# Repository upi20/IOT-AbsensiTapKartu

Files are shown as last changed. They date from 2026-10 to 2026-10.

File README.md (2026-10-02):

# Absensi RFID Terintegrasi

Alat absensi **tap kartu RFID** berbasis ESP32 yang **terhubung langsung ke website**. Kartu ditempel, alat mengirim nomornya ke server lewat WiFi (HTTP/HTTPS), dan hasilnya (MASUK / PULANG / tidak terdaftar) tampil di layar sentuh 3.5", LED RGB, dan bunyi buzzer. Semua data kehadiran tersimpan di website, bukan di alat.

*Open-source RFID attendance terminal (ESP32 + RC522 + 3.5" touch LCD) that talks to any web app through a small HTTP API. Includes firmware, a Laravel reference server, integration examples, perfboard/PCB layouts and a 3D-printed case. Documentation is in Indonesian.*

Repositori ini berisi **semua yang dibutuhkan dari nol sampai alat jadi**: daftar komponen, kabel prototipe, firmware, server + panel admin, contoh integrasi ke aplikasi lain, tata letak PCB, dan casing cetak 3D.

---

## Daftar isi

- [Fitur](#fitur)
- [Status proyek](#status-proyek-baca-dulu)
- [Cara kerja](#cara-kerja)
- [Peta tahapan](#peta-tahapan)
- [Tahap 0 — Siapkan komponen, alat, dan software](#tahap-0--siapkan-komponen-alat-dan-software)
- [Tahap 1 — Prototipe dengan kabel jumper](#tahap-1--prototipe-dengan-kabel-jumper)
- [Tahap 2 — Firmware](#tahap-2--firmware)
- [Tahap 3 — Backend (website)](#tahap-3--backend-website)
- [Tahap 4 — PCB](#tahap-4--pcb)
- [Tahap 5 — Casing cetak 3D](#tahap-5--casing-cetak-3d)
- [Pemecahan masalah](#pemecahan-masalah)
- [Struktur folder](#struktur-folder)
- [Untuk kontributor](#untuk-kontributor)
- [Lisensi](#lisensi)

Dokumen lain: [Panduan pengguna untuk klien](doc/panduan-pengguna.md) · [Panduan integrasi aplikasi](doc/integrasi-aplikasi.md) · [Riwayat perubahan](CHANGELOG.md)

---

## Fitur

**Alat (firmware ESP32)**
- Tap kartu MIFARE 13,56 MHz (RC522), hasil tampil dalam ± 0,4–0,6 detik di jaringan normal.
- Semua pengaturan lewat **layar sentuh**: pilih WiFi, isi password, Base URL server, dan API key. Tidak perlu mengubah kode untuk tiap lokasi.
- **Antrean offline** 200 tap: kalau server tidak bisa dihubungi, tap disimpan dan dikirim ulang otomatis (tanpa catatan ganda berkat `tap_id`).
- Foto pemilik kartu (JPEG kecil), pesan dari server, jam tersinkron.
- **Screensaver pengumuman** (judul, isi, ikon) yang diambil dari website.
- **Layar meredup** saat alat diam; kartu tetap terbaca.
- Menu Pengaturan ber-PIN, kalibrasi layar, tes buzzer & LED, cek kabel RFID, reset pabrik (tekan EN 3 kali).
- Heartbeat tiap menit, sehingga website tahu alat mana yang aktif.
- Tahan menyala lama: **watchdog** (restart sendiri kalau program macet) dan **restart harian terjadwal** saat sepi (jamnya diatur per alat dari website, bawaan 03:00).
- **Mode absen**: otomatis (server menentukan datang/pulang) atau **pilih DATANG / PULANG** lewat dua tombol di layar utama (endpoint `/check-in` & `/check-out`), diatur dari menu alat atau dari website.
- Mudah dirawat dari jauh: **kode error di layar** (contoh `E11` = password WiFi salah), laporan kesehatan dan **ringkasan crash** ke website, dan **update firmware jarak jauh (OTA)** yang kembali sendiri ke versi lama kalau firmware baru gagal.

**Website**
- **API sederhana** (`/ping`, `/tap`, `/heartbeat`, opsional `/announcements`) yang bisa diterapkan di aplikasi apa saja: lihat [doc/spesifikasi-api.md](doc/spesifikasi-api.md).
- **Server acuan Laravel** dengan panel admin: anggota & kartu, kehadiran, kartu belum terdaftar, rekap + CSV, daftar alat (PIN per alat), pengumuman, pengaturan (API key, judul, layar redup).
- **Contoh integrasi** PHP dan Node.js tanpa framework, skrip pemeriksa server, dan koleksi Postman lengkap.

---

## Status proyek (baca dulu)

Supaya tidak ada yang tersesat: bagian di bawah ini dibedakan antara yang **sudah diuji di alat sungguhan** dan yang **baru berupa desain**.

| Bagian | Status |
|---|---|
| Prototipe kabel jumper di expansion board | ✅ Dirakit dan berjalan |
| Firmware v1.3.0 | ✅ Berjalan di alat prototipe (tap, antrean, pengumuman, layar redup) |
| Firmware v1.4.0 (watchdog, restart harian, identitas baru) | ✅ Berjalan di alat (boot, tap, heartbeat, watchdog aktif); ⚠️ restart harian **belum diuji** |
| Firmware v1.5.0 (kode error, ringkasan crash, update jarak jauh) | ✅ Update jarak jauh diuji di alat (unduh ± 15 detik, rollback saat restart di masa percobaan juga terbukti); ⚠️ tiap kode error belum diuji satu per satu |
| Server Laravel + panel admin | ✅ Dipakai di server percobaan; 145 tes otomatis lulus |
| Contoh integrasi PHP/Node + Postman | ✅ Lolos skrip pemeriksa dan 114 pemeriksaan Postman |
| Firmware v1.6.0–1.9.1 (mode absen DATANG/PULANG, menu Update firmware, buzzer langsung ke D17) | ✅ Dikirim ke alat lewat update jarak jauh: otomatis 1.5.0 → 1.6.0 → 1.7.0, manual 1.7.0 → 1.8.0 → 1.9.0 → 1.9.1. ⚠️ Mode Pilih Datang/Pulang **belum diuji dengan tap sungguhan** |
| PCB dot matrix (papan bolong 1 sisi 30 × 50) | ✅ Alat pertama dirakit dengan tata letak ini dan berjalan (layar, sentuh, RFID, WiFi, tap, buzzer). ⚠️ Kabel LED (tahap 16) belum diuji; casing belum disesuaikan |
| PCB cetak (KiCad) | ⚠️ Desain lolos DRC, **belum dipesan dan belum diuji** |
| Casing cetak 3D | ⚠️ Desain lolos cek tabrakan otomatis, **belum dicetak** |

Kalau Anda merakit bagian yang bertanda ⚠️, lakukan cek cetak kertas 1:1 yang dijelaskan di tahap itu, dan laporkan hasilnya lewat *Issues*.

---

## Cara kerja

```mermaid
flowchart LR
  K[Kartu RFID] -->|tap| A["Alat<br/>ESP32 + RC522 + LCD"]
  A -->|"POST /tap (WiFi, HTTPS)"| W["Website<br/>(server acuan Laravel<br/>atau aplikasi Anda)"]
  W -->|"status: MASUK / PULANG / ..."| A
  A -.->|heartbeat tiap 1 menit| W
  W -.->|pengaturan & pengumuman| A
  W --> P[Panel admin / laporan]
```

1. Kartu ditempel. Alat membaca UID kartu dan mengubahnya menjadi **nomor 10 digit**.
2. Alat mengirim `POST {Base URL}/tap` dengan header `X-API-Key` dan `X-Device-ID`.
3. Website memutuskan statusnya (`check_in`, `check_out`, `duplicate`, `unknown`, `rejected`) dan membalas nama, pesan, dan (opsional) URL foto.
4. Alat menampilkan hasil, berbunyi, dan menyalakan LED sesuai status.

Website juga bisa mengirim **pengaturan jarak jauh** (PIN menu, judul layar, layar redup) dan **pengumuman** ke alat. Kontrak lengkapnya ada di [doc/spesifikasi-api.md](doc/spesifikasi-api.md).

---

## Peta tahapan

| Tahap | Hasil | Dokumen utama |
|---|---|---|
| 0. Persiapan | Komponen, alat, software siap | bagian di bawah |
| 1. Prototipe | Rangkaian kabel jumper berjalan | [doc/skema-lengkap.md](doc/skema-lengkap.md), [doc/rakit-lengkap.html](doc/rakit-lengkap.html) |
| 2. Firmware | Alat membaca kartu dan tampil di layar | [firmware/](firmware/) |
| 3. Backend | Website menerima tap, panel admin | [api/README.md](api/README.md), [doc/integrasi-aplikasi.md](doc/integrasi-aplikasi.md), [doc/spesifikasi-api.md](doc/spesifikasi-api.md), [contoh-integrasi/](contoh-integrasi/README.md) |
| 4. PCB | Rangkaian rapi tanpa kabel jumper | [doc/rakit-dotmatrix.html](doc/rakit-dotmatrix.html), [doc/pcb-papan-induk.md](doc/pcb-papan-induk.md) |
| 5. Casing | Alat jadi, siap dipasang di dinding | [doc/casing.md](doc/casing.md) |

> **File `.html`** di folder `doc/` adalah panduan interaktif. GitHub hanya menampilkan kodenya, jadi **unduh repositori lalu buka file itu di browser** (dobel klik).

---

## Tahap 0 — Siapkan komponen, alat, dan software

### Komponen (1 unit)

| Komponen | Keterangan | Catatan |
|---|---|---|
| ESP32 DOIT DevKit V1 **30 pin** | Chip USB CH340, jarak dua deret pin 25,4 mm | Varian 38 pin **tidak** cocok dengan PCB dan casing |
| LCD 3.5" SPI **ILI9488** + touch **XPT2046** | 480 × 320, 14 pin di satu sisi pendek, PCB 98 × 56,34 mm (kompatibel LCDWIKI MSP3520) | Jumper **J1** di belakang LCD harus disolder (lihat Tahap 1) |
| RFID **RC522** | Modul standar 60 × 40 mm, 8 pin, 3,3 V | Header pin lurus |
| LED RGB 5 mm **common cathode** | 4 kaki, kaki terpanjang = katoda (−) | Bukan *common anode* |
| Buzzer **aktif** 3–5 V | 2 kaki, berbunyi sendiri bila diberi tegangan | Bukan buzzer pasif |
| Kartu / gantungan kunci MIFARE 13,56 MHz | Biasanya satu paket dengan RC522 | |
| Kabel USB data + adaptor 5 V | Untuk daya alat | |

**Untuk prototipe (Tahap 1):** expansion board ESP32 30 pin (header G-V-S per pin) dan ± 30 kabel jumper female-female.
**Untuk versi rapi (Tahap 4):** papan dot matrix atau PCB cetak beserta komponen kecilnya (resistor, transistor, dioda, kapasitor, header female). Daftarnya ada di tahap itu.

### Alat

Solder + timah, tang potong, multimeter (mode bunyi dan volt DC), obeng kecil. Untuk Tahap 4: cutter, bor 3 mm, lem. Untuk Tahap 5: baut M3 dan spacer.

### Software

| Software | Untuk | Versi yang dipakai di proyek ini |
|---|---|---|
| [Arduino IDE 2](https://www.arduino.cc/en/software) (atau `arduino-cli`) | Firmware | IDE 2.3.10 / arduino-cli 1.5.1 |
| Paket board **esp32 by Espressif Systems** | Firmware | 3.3.12 |
| PHP 8.3 + Composer + PostgreSQL | Server acuan (Tahap 3) | PHP 8.3, Laravel 13 |
| KiCad 10 (opsional) | Membuka / mengubah PCB cetak | 10.0.6 |
| OpenSCAD versi *snapshot* (opsional) | Membuka / mengubah casing | 2026.09.30 |
| Python 3 + PyMuPDF (opsional) | Membuat ulang templat dot matrix | |

---

## Tahap 1 — Prototipe dengan kabel jumper

Tujuannya membuktikan semua komponen berfungsi sebelum dibuat rapi. **Cabut USB setiap kali memasang atau memindah kabel.**

### 1.1 Aturan daya (penting)

- **Semua komponen memakai 3,3 V.** Jangan ada kabel ke pin 5V.
- Di expansion board, jumper **JUMP** harus di posisi **3.3V** (mengatur semua pin V).
- Pakai satu kabel USB saja, ke port **ESP32** (bukan port expansion).
- ESP32 hanya bisa tersambung ke WiFi **2,4 GHz**.

### 1.2 Solder jumper J1 di LCD

Menurut skema resmi modul LCD: kalau VCC diberi **3,3 V**, jumper **J1 harus disambung** (dijembatani timah). Kalau VCC 5 V, J1 dibiarkan terbuka. Rangkaian ini memakai 3,3 V, jadi:

1. Cari bantalan bertanda **J1** di belakang LCD (dekat regulator U1).
2. Sambungkan kedua bantalannya dengan sedikit timah.
3. Setelah J1 disambung, **VCC LCD tidak boleh lagi diberi 5 V**: chip layar bisa rusak.

### 1.3 Pasang kabel

Ikuti [doc/skema-lengkap.md](doc/skema-lengkap.md) (versi interaktif: [doc/rakit-lengkap.html](doc/rakit-lengkap.html)). Ringkasan pin:

| Bagian | Pin modul → GPIO ESP32 |
|---|---|
| LCD | VCC → 3V3, GND → GND, CS → 5, RESET → 4, DC → **16**, SDI → 23, SCK → 18, **LED → 2**, SDO tidak disambung |
| Touch | T_CLK → 22, T_CS → 15, T_DIN → 21, T_DO → 19, T_IRQ tidak disambung |
| RC522 | SDA → 33, SCK → 14, MOSI → 13, MISO → 35, RST → 32, 3.3V → 3V3, GND → GND, IRQ tidak disambung |
| Buzzer aktif | + → 17, − → GND |
| LED RGB | R → 25, G → 26, B → 27, kaki terpanjang (K) → GND |

Catatan:
- **DC jangan di GPIO2.** Pin LED LCD (lampu latar) memang di GPIO2; firmware memakainya untuk meredupkan layar. Kalau LED LCD disambung ke 3V3, layar menyala terus tanpa fitur redup.
- Pin **GPIO12 jangan dipakai** (pin boot yang membuat ESP32 gagal menyala).
- Resistor 220–330 Ω di tiap kaki warna LED RGB disarankan. Untuk prototipe boleh tanpa resistor karena firmware membatasi arus pin.

### 1.4 Tes per bagian

Sebelum menjalankan tes, siapkan software di [Tahap 2.1](#21-pasang-software). Sketsa tes ada di [firmware/tes/](firmware/tes/):

| Urutan | Sketsa | Yang dites | Hasil yang benar |
|---|---|---|---|
| 1 | `tes_touch` | Layar + layar sentuh | Muncul kalibrasi 3 titik, lalu mode menggambar: titik muncul tepat di bawah jari/stylus |
| 2 | `tes_miso` | Kabel MOSI dan MISO RC522 tidak bersentuhan | Monitor serial menulis `AMAN` terus-menerus |
| 3 | `tes_rfid` | RC522 menjawab | Baris pertama (susunan kabel yang direncanakan) diakhiri `<== RC522 MENJAWAB` |

Buzzer dan LED dites dari firmware utama (menu **Tes buzzer & LED**), setelah Tahap 2.

---

## Tahap 2 — Firmware

Kode ada di [firmware/absensi/](firmware/absensi/). Bahasa komentar: Indonesia.

### 2.1 Pasang software

1. Pasang **Arduino IDE 2**.
2. **Tools → Board → Boards Manager**, cari `esp32`, pasang **esp32 by Espressif Systems** (dipakai: 3.3.12). Kalau tidak muncul, tambahkan URL `https://espressif.github.io/arduino-esp32/package_esp32_index.json` di **Settings → Additional boards manager URLs**.
3. **Tools → Manage Libraries**, pasang:

   | Library | Versi dipakai | Untuk |
   |---|---|---|
   | TFT_eSPI (Bodmer) | 2.5.43 | Layar |
   | RFID_MFRC522v2 | 2.0.6 | RC522 |
   | ArduinoJson (Benoit Blanchon) | 7.4.3 | JSON |
   | TJpg_Decoder (Bodmer) | 1.1.0 | Foto |
   | XPT2046_Touchscreen (Paul Stoffregen) | 1.4 | Hanya untuk sketsa `tes_touch` |

   Pengaturan pin layar ada di `tft_setup.h` di folder sketsa dan dibaca otomatis oleh TFT_eSPI. **File library tidak perlu diubah.**
4. **Mac Apple Silicon:** pasang Rosetta 2 (alat `ctags` di paket Arduino masih x86):
   ```bash
   softwareupdate --install-rosetta --agree-to-license
   ```
5. **Windows:** pasang driver **CH340** kalau port COM tidak muncul.

### 2.2 Atur ID alat

Buka [firmware/absensi/config.h](firmware/absensi/config.h), ubah `ID_ALAT` (bawaan `"ABS-001"`). **Setiap alat harus punya ID berbeda**; ID ini dikirim sebagai `X-Device-ID` dan tidak terhapus saat reset pabrik. Isi `""` supaya dibuat otomatis dari alamat MAC (contoh `ABS-79438C`).

Sejak v1.5.0, ID yang dipakai juga disimpan di memori alat. Upload lewat USB memakai `ID_ALAT` di `config.h`. Update jarak jauh (2.7) tidak memakai `ID_ALAT`, tapi ID yang tersimpan di alat, jadi satu file firmware aman dikirim ke semua alat.

Pengaturan lain di file yang sama (biasanya tidak perlu diubah): PIN bawaan `2026`, interval heartbeat 60 detik, batas antrean 200, batas waktu tap 3 detik, layar redup 60 detik ke 20 %.

### 2.3 Upload

**Lewat Arduino IDE (semua sistem operasi):**
1. Buka `firmware/absensi/absensi.ino`.
2. Board: **ESP32 Dev Module** (bukan "DOIT ESP32 DEVKIT V1", karena yang itu tidak punya menu partisi).
3. **Partition Scheme: Minimal SPIFFS (1.9MB APP with OTA/128KB SPIFFS)**. Wajib: firmware ± 1,35 MB tidak muat di partisi bawaan, dan skema ini punya 2 slot untuk update jarak jauh.
4. Upload Speed: **460800** (Mac/Linux). Kalau upload gagal atau di Windows, pakai **115200**.
5. Pilih port, klik Upload. Kalau tertahan di `Connecting....`, tahan tombol **BOOT** sampai persentase muncul.

**Lewat skrip (Mac/Linux, butuh `arduino-cli`):** dari folder `firmware/`:
```bash
./upload.sh -m              # compile + upload firmware utama, lalu buka monitor serial
./upload.sh -c              # compile saja (cek tanpa alat)
./upload.sh -b              # buat file untuk update jarak jauh (lihat 2.7)
./upload.sh tes_rfid -m     # upload sketsa tes
./monitor.sh                # monitor serial 115200 baud, keluar: Ctrl+C
PORT=/dev/ttyUSB0 ./upload.sh    # pilih port sendiri
```
Skrip memakai partisi Minimal SPIFFS dan kecepatan 460800 secara otomatis. `arduino-cli` dicari di `PATH`, lalu di dalam Arduino IDE (macOS). Lokasi lain: `ARDUINO_CLI=/path/arduino-cli ./upload.sh`.

> **Alat dengan firmware ≤ 1.4.0** (partisi lama Huge APP) harus di-upload **sekali lewat USB** ke v1.5.0, karena partisinya berubah. Pengaturan (WiFi, Base URL, API key, PIN, kalibrasi) tetap, tapi antrean tap dan pengumuman yang tersimpan terhapus. Kirim dulu antrean yang tersisa (tunggu sampai Info alat → Antrean = 0). Setelah itu, update berikutnya bisa lewat jarak jauh.

### 2.4 Siapkan server sementara (kalau website belum ada)

Saat pertama menyala, alat meminta **Base URL** dan **API key**. Kalau server Tahap 3 belum siap, jalankan contoh server PHP di laptop (satu WiFi dengan alat):

```bash
cd contoh-integrasi/php
php -S 0.0.0.0:8080 index.php
```

Base URL-nya `http://<IP-laptop>:8080`, API key `ganti-dengan-kunci-anda`. Kartu contoh yang terdaftar: `0218893066` dan `0012345678` (`0055555555` sengaja nonaktif). Kartu Anda sendiri akan tampil "tidak terdaftar" sampai nomornya ditambahkan ke data contoh. Ini cukup untuk membuktikan alat bekerja. Rinciannya: [contoh-integrasi/README.md](contoh-integrasi/README.md).

### 2.5 Pertama kali menyala

Alat baru (atau setelah reset pabrik) menjalankan urutan ini:
1. **Kalibrasi layar sentuh** 3 titik (hanya kalau belum pernah).
2. **Panduan 4 langkah:**
   1. **WiFi**: pilih dari hasil pindai (atau "Ketik manual"), isi password.
   2. **Base URL**: sudah terisi `https://`. Lengkapi, contoh `https://absensi.example.com/api/absensi` atau `http://192.168.1.10:8080`. Tanpa `/` di akhir.
   3. **API key**: sama persis dengan di server.
   4. **Tes koneksi**, lalu **Simpan**.
3. Layar utama tampil. Tempel kartu.

Monitor serial (115200 baud) menampilkan catatan seperti `RFID: RC522 terdeteksi`, `HTTP POST /tap -> 200`, dan `Tap: 245 ms`.

### 2.6 Menu dan fitur alat

| Fitur | Cara |
|---|---|
| Menu Pengaturan | Ikon gir di layar utama, PIN bawaan **2026** (5 kali salah = terkunci 60 detik). Menu tertutup sendiri setelah 60 detik tanpa sentuhan |
| Isi menu | WiFi, Server, Tes koneksi, Info alat, Ganti PIN, Kalibrasi layar, Tes buzzer & LED, Tes screensaver, Cek kabel RFID, Mode absen, Update firmware, Reset pabrik |
| Mode absen | Menu **Mode absen**: **Otomatis** (semua tap ke `/tap`, server menentukan datang/pulang) atau **Pilih Datang / Pulang**: layar utama menampilkan tombol **DATANG** dan **PULANG**. Petugas memilih sekali, lalu semua tap dikirim ke `/check-in` atau `/check-out` sampai diganti. Pilihan dikosongkan otomatis saat tanggal berganti; tap sebelum memilih tidak dikirim. Bisa juga diatur per alat dari website (`config.tap_mode`) |
| Kalibrasi ulang layar | Menu **Kalibrasi layar**, atau tekan **EN** lalu tekan **BOOT** saat muncul "Tekan BOOT sekarang" (jeda 1 detik) |
| Reset pabrik | Tekan **EN 3 kali berturut-turut** (masing-masing sebelum alat menyala 5 detik), lalu pilih "Ya, reset"; atau lewat menu. Menghapus WiFi, URL, API key, PIN, judul, kalibrasi, antrean, pengumuman. **ID alat tidak terhapus** |
| Layar redup | Setelah diam 60 detik, layar meredup ke 20 %. Kartu tetap diproses. Sentuhan pertama hanya menyalakan layar. Angka bisa diubah dari website (`dim_after`, `dim_level`) |
| Antrean offline | Server tidak terjangkau → tap disimpan (maks. 200) dan dikirim ulang saat alat diam |
| Restart harian | Sekali sehari pada jam yang diatur per alat di website (bawaan **03:00**, jam alat), hanya saat alat diam. Antrean tap tetap tersimpan. Kosongkan jamnya di website untuk mematikan |
| Watchdog | Kalau program macet lebih dari 60 detik, alat restart sendiri. Alasan restart terakhir terlihat di **Info alat → Restart** dan dikirim ke website |
| Kode error | Masalah tampil di baris bawah layar utama dengan kode, contoh **E11 Password WiFi salah**. Daftar lengkap di 2.8. Kode yang sedang aktif juga ada di **Info alat → Error** |
| Laporan ke website | Tiap menit: sinyal, RAM, status RFID, antrean, kode error, alasan restart, dan ringkasan crash terakhir. Website menandai alat yang perlu diperhatikan |
| Update jarak jauh | Firmware baru diunggah di website, lalu alat memasangnya sendiri saat diam, **atau langsung lewat menu Update firmware** (lihat 2.7) |
| Pengaturan dari website | PIN menu (per alat), jam restart (per alat), judul layar, layar redup, pengumuman, update firmware (per alat) |

### 2.7 Update firmware jarak jauh (OTA)

Dipakai untuk memperbarui alat yang sudah terpasang di lokasi **tanpa kabel USB**: file firmware diunggah ke website, lalu alat mengunduh dan memasangnya sendiri.

**Syarat (cukup dicek sekali):**
- Alat sudah ber-firmware **1.5.0 atau lebih baru**. Alat dengan firmware lama harus di-upload lewat USB dulu (lihat catatan di 2.3), karena partisinya berbeda.
- Website mendukung update firmware. Server acuan Laravel (Tahap 3.A) sudah punya menu **Firmware**. Aplikasi sendiri: lihat [doc/spesifikasi-api.md](doc/spesifikasi-api.md) bagian 6.1.

#### Langkah 1 — Naikkan nomor versi

Buka [firmware/absensi/config.h](firmware/absensi/config.h) dan ubah `VERSI_FIRMWARE`, contoh `"1.5.0"` → `"1.5.1"`.

Wajib: alat **mengabaikan** update yang versinya sama dengan versi yang sedang terpasang, dan website menolak file yang di dalamnya tidak ada nomor versi yang Anda isi.

#### Langkah 2 — Build file `.bin`

File untuk OTA **bukan** hasil upload biasa. ID alat tidak boleh ikut tertanam, supaya satu file bisa dikirim ke semua alat dan tiap alat tetap memakai ID-nya sendiri. Pilih salah satu cara:

**Cara A — skrip (Mac/Linux, disarankan).** Dari folder `firmware/`, tanpa alat tersambung:
```bash
./upload.sh -b
```
Hasilnya di folder `firmware/build/`:

| File | Untuk apa |
|---|---|
| `absensi-1.5.1.bin` | **Diunggah ke website** (Langkah 3) |
| `absensi-1.5.1.elf` | **Simpan baik-baik** (jangan diunggah). Hanya file ini yang bisa menerjemahkan laporan crash dari versi 1.5.1 (lihat 2.8) |
| `absensi/` | File sementara hasil compile, abaikan |

**Cara B — Arduino IDE (semua sistem operasi).**
1. Di `config.h`, hapus `//` di depan baris `// #define OTA_BUILD`, sehingga menjadi `#define OTA_BUILD`.
2. Board dan Partition Scheme sama seperti 2.3 (**ESP32 Dev Module**, **Minimal SPIFFS (1.9MB APP with OTA/128KB SPIFFS)**).
3. Menu **Sketch → Export Compiled Binary**. Tunggu sampai selesai.
4. Buka folder `firmware/absensi/build/esp32.esp32.esp32/`. Yang diunggah ke website adalah **`absensi.ino.bin`**. Jangan pakai `absensi.ino.merged.bin`, `absensi.ino.bootloader.bin`, atau `absensi.ino.partitions.bin`. Simpan juga `absensi.ino.elf`, beri nama sesuai versinya.
5. **Kembalikan `//` di depan `#define OTA_BUILD`.** Kalau lupa, upload lewat USB ke alat baru tidak memakai `ID_ALAT`, tapi ID dari MAC (contoh `ABS-79438C`).

#### Langkah 3 — Unggah dan pilih alat (server acuan)

1. Panel admin → **Firmware** → **Unggah firmware**. Isi **Versi** sama persis dengan `VERSI_FIRMWARE` (contoh `1.5.1`), pilih file `.bin`, lalu klik **Unggah**.
2. Panel admin → **Alat** → di kartu alat yang akan diperbarui, pilih **Update firmware ke: 1.5.1**, lalu simpan. Status alat menjadi **"Menunggu alat mengunduh"**.
3. Untuk semua alat sekaligus, pakai tombol **Terapkan ke semua alat** di halaman Firmware. **Cobakan dulu ke satu alat** sampai statusnya "Sudah terpasang", baru ke semua.

#### Langkah 4 — Tunggu alat memasang sendiri

1. Alat menerima tawaran update lewat heartbeat (paling lama 1 menit).
2. Update baru mulai saat **tidak ada kartu atau sentuhan selama 1 menit**, supaya orang yang sedang absen tidak terganggu.
3. Layar menampilkan **"Memperbarui firmware v1.5.0 → v1.5.1"**, bilah kemajuan, dan **"Jangan cabut listrik alat"**. Unduhan memakan waktu ± 15–60 detik, tergantung internet.
4. Alat mengecek isi file (MD5), menampilkan "Firmware terpasang", lalu restart dengan versi baru.
5. Di halaman Alat, status menjadi **"Sudah terpasang"**, dan riwayat kejadian mencatat `Firmware 1.5.0 -> 1.5.1`.

**Atau pasang sekarang juga (manual, firmware 1.7.0 ke atas):** di alat buka **Pengaturan → Update firmware**. Alat langsung bertanya ke server. Kalau muncul **"Tersedia v…"**, tekan **Pasang sekarang** → **Pasang**. Cara ini tidak menunggu alat diam dan tidak menunggu jeda 30 menit setelah gagal, dan alasan kegagalan tampil di layar. Server hanya menawarkan versi yang **sudah dijadwalkan untuk alat itu** (Langkah 3). Kalau belum dijadwalkan, menu menjawab "Sudah versi terbaru".

Selama update, buzzer diam, LED menyala biru, dan tampilan lain (jam, sinyal) berhenti sebentar: semua kemampuan alat dipakai untuk mengunduh. Itu wajar selama bilah kemajuan bergerak.

#### Kalau ada yang salah

| Yang terjadi | Artinya / yang dilakukan |
|---|---|
| Server sudah menawarkan update tapi alat tidak kunjung memasang | Alat sedang dipakai, menu Pengaturan sedang terbuka, atau percobaan pertama gagal tersambung (alat lalu menunggu 30 menit). Pakai **menu Update firmware** untuk memasang langsung dan melihat alasannya |
| Lama di "Menunggu alat mengunduh" | Alat offline, sedang dipakai terus, atau firmware alat masih < 1.5.0. Cek status Online dan versi firmware alat |
| Layar "Update firmware gagal" | Unduhan putus atau file rusak. Alat tetap memakai versi lama dan **mencoba lagi 30 menit kemudian**. Alasannya terlihat di Info alat → Firmware |
| Riwayat: "Firmware 1.5.1 -> 1.5.0" tanpa status gagal | Listrik padam atau tombol EN ditekan di menit pertama setelah update, jadi alat kembali ke versi lama untuk berjaga-jaga. Bukan salah firmware: alat **mengulang update sendiri** (paling banyak 3 kali) |
| Status "Gagal, kembali ke 1.5.0" | Firmware baru crash, macet (watchdog), atau listrik drop (brownout) sebelum dinyatakan sehat (5 menit, atau 1 menit setelah server tersambung), jadi alat **kembali sendiri ke versi lama**. Versi itu tidak dicoba lagi. Perbaiki kodenya (lihat laporan crash di riwayat kejadian), naikkan versi (1.5.2), lalu unggah ulang |
| Website menolak file | Versi yang diisi tidak ditemukan di dalam file (lupa Langkah 1, atau salah ketik), file bukan `absensi.ino.bin`, atau ukuran lebih dari 1,9 MB |

Jangan cabut listrik selama layar "Memperbarui firmware" dan di menit pertama setelah alat restart. Kalaupun terjadi, alat tidak rusak: saat mengunduh, firmware baru ditulis ke slot cadangan dan baru dipakai setelah selesai dicek; sesudah restart, alat kembali ke versi lama lalu mengulang update.

Catatan keamanan: alat memakai HTTPS tanpa pemeriksaan sertifikat (sama seperti request lain). Orang yang bisa menyadap jaringan alat secara teori bisa mengirim firmware palsu. Karena itu, update hanya dikirim ke alat yang dipilih di website.

### 2.8 Kode error di layar

Konsumen cukup menyebutkan kode yang tampil di baris bawah layar (atau di **Info alat → Error**).

| Kode | Arti | Yang dicek |
|---|---|---|
| E10 | WiFi tidak ditemukan | Router menyala? Nama WiFi benar? WiFi harus **2,4 GHz**. Alat terlalu jauh dari router? |
| E11 | Password WiFi salah | Ganti password di Pengaturan → WiFi (password router mungkin baru diganti) |
| E12 | WiFi gagal tersambung | Router penuh atau menolak perangkat baru (filter MAC). Restart router |
| E13 | WiFi tidak memberi alamat IP | DHCP router mati atau alamat habis. Restart router |
| E20 | Server tidak bisa dihubungi | Internet lokasi putus, atau Base URL salah alamat. Buka website dari HP di WiFi yang sama |
| E21 | API key salah | Samakan API key di alat (Pengaturan → Server) dengan di website |
| E22 | Alat ditolak server | Alat dinonaktifkan / belum diizinkan di website |
| E23 | Alamat API salah | Base URL keliru (harus diakhiri jalur API, tanpa `/` di akhir), atau `http` vs `https` |
| E24 | Server error / sibuk | Masalah di website (HTTP 5xx / 429). Tap tetap disimpan di antrean |
| E25 | Balasan server tidak valid | Base URL mengarah ke halaman biasa, bukan API |
| E26 | Server terlalu lama menjawab | Internet lambat atau server berat |
| E30 | Pembaca RFID tidak terdeteksi | Kabel RC522 longgar. Menu → Cek kabel RFID |
| E31 | Jam belum sinkron | Server tidak mengirim `server_time` dan NTP diblokir jaringan |

**Membaca laporan crash.** Kalau alat pernah crash, halaman Alat di website menampilkan alamat seperti `0x400d4634 0x400880ed` beserta id build. Terjemahkan alamat itu dengan file `.elf` dari versi yang sama:

```bash
~/Library/Arduino15/packages/esp32/tools/esp-x32/*/bin/xtensa-esp32-elf-addr2line -pfiaC \
  -e firmware/build/absensi-1.5.0.elf 0x400d4634 0x400880ed
```
Hasilnya berupa nama fungsi dan baris kode penyebab crash. Linux: ganti `~/Library/Arduino15` dengan `~/.arduino15`.

---

## Tahap 3 — Backend (website)

Pilih salah satu (boleh keduanya):

### 3.A Pakai server acuan Laravel (paling cepat)

Server lengkap dengan panel admin ada di [api/](api/README.md). Ringkasnya:

```bash
cd api
composer install
cp .env.example .env          # isi DB_* (PostgreSQL) dan APP_URL
php artisan key:generate
php artisan migrate           # membuat akun "admin" (tanpa password) dan API key acak
php artisan absensi:admin-password admin
php artisan storage:link
./serve.sh                    # http://127.0.0.1:8133
```

Kebutuhan: PHP ^8.3 (ekstensi pdo_pgsql, mbstring, fileinfo; gd untuk foto), Composer, **PostgreSQL** (SQLite/MySQL tidak didukung). Tidak perlu Node/npm.

Di panel admin (`/admin`):
1. **Pengaturan**: salin **Base URL** (`<APP_URL>/api/absensi`) dan **API key**, isikan di alat.
2. Tempel kartu di alat. Kartu baru muncul di **Kartu belum terdaftar** → klik **Daftarkan** → isi nama → simpan.
3. Tempel lagi: alat menampilkan **MASUK** (tap pertama hari itu). Tap lagi dalam 60 detik = **sudah tercatat**; tap setelahnya = **PULANG**.

Langkah lengkap, opsi, dan perintah artisan: [api/README.md](api/README.md).

### 3.B Integrasikan ke aplikasi Anda sendiri

Alat tidak terikat ke Laravel. Aplikasi apa pun (PHP, Node, Python, Go, ...) bisa memakainya.

1. **Mulai dari [doc/integrasi-aplikasi.md](doc/integrasi-aplikasi.md)**: gambaran besar, **6 fitur wajib** (Kartu belum terdaftar, Rekap, Alat, Firmware, Pengumuman, Pengaturan), data yang perlu disimpan, urutan kerja, dan checklist siap pakai.
2. Kontrak teknis alat ↔ aplikasi: [doc/spesifikasi-api.md](doc/spesifikasi-api.md).
3. Salin pola dari server contoh yang sudah menjalankan keenam fitur: [contoh-integrasi/php/index.php](contoh-integrasi/php/index.php) atau [contoh-integrasi/node/server.js](contoh-integrasi/node/server.js) ([cara pakai](contoh-integrasi/README.md)).
4. Uji aplikasi Anda dengan [contoh-integrasi/tes/cek-server.sh](contoh-integrasi/tes/cek-server.sh) dan koleksi Postman di [contoh-integrasi/postman/](contoh-integrasi/postman/) (bisa otomatis dengan Newman).

### 3.C Online di internet

- Alat mendukung **HTTPS** (sertifikat tidak diverifikasi, jadi tetap gunakan API key yang panjang dan acak).
- Pasang server di VPS (nginx + PHP-FPM) atau jalankan di komputer sendiri dan buka lewat **Cloudflare Tunnel**. Penjelasannya ada di [api/README.md](api/README.md#memasang-di-internet).
- Untuk server publik: `APP_ENV=production`, `APP_DEBUG=false`, dan buat API key baru dari halaman Pengaturan.

---

## Tahap 4 — PCB

Setelah prototipe berjalan, pindahkan rangkaian ke papan supaya rapi dan muat di casing. Ada dua pilihan dengan **posisi soket LCD yang sama**, sehingga casingnya serupa:

| | A. PCB dot matrix (papan bolong) | B. PCB cetak |
|---|---|---|
| Biaya | Paling murah | Biaya cetak + ongkir |
| Cara | Rakit dan sambung kabel sendiri | Pesan ke pabrik, solder komponen |
| Status | Tata letak & panduan selesai, belum dirakit fisik | Desain lolos DRC, belum dipesan |
| Panduan | [doc/rakit-dotmatrix.html](doc/rakit-dotmatrix.html) | [doc/pcb-papan-induk.md](doc/pcb-papan-induk.md) |

Pada kedua pilihan, ESP32, LCD, dan RC522 **dicolokkan ke header female** (tidak disolder), sehingga mudah diganti. Pin yang dipakai sama dengan prototipe, jadi **firmware tidak berubah**.

### 4.A PCB dot matrix

1. Bahan per unit: papan dot matrix **1 sisi** 9 × 15 cm berisi **30 × 50 lubang** (label kolom `1a`–`1z`, `2a`–`2d`, baris `001`–`050`), header female 1×15 ×2, 1×14 ×1, 1×8 ×1, header male 1×4 (kabel LED), resistor 220 Ω ×3, elko **220 µF**, keramik **47 nF** ×2, buzzer aktif 12 mm, kabel silikon 24 AWG merah dan hitam, kabel jumper female 4 jalur untuk LED. Papan dipakai utuh; baris 042–050 tidak dipakai.
2. Buka [doc/rakit-dotmatrix.html](doc/rakit-dotmatrix.html) di browser dan ikuti langkahnya. Semua komponen dipasang di **depan** (sisi polos) dan disolder di **belakang** (sisi tembaga); kabel disolder langsung menempel ke kaki, tanpa lubang tembus. Buzzer langsung ke D17 (tanpa transistor), LED dipasang di casing lewat kabel. Papan di halaman itu bisa dibalik depan/belakang, dan setiap kabel punya kode serta posisi lubang yang ditulis **sama dengan label di papan** (`1z-024` = kolom 1z, baris 024).
3. Opsional: cetak templat 1:1 [hardware/dotmatrix/hasil/templat-1-1.pdf](hardware/dotmatrix/hasil/templat-1-1.pdf) (A4 tegak, skala 100 %, garis skala harus tepat 50 mm) sebagai peta di samping papan.

> Tata letak ini memakai papan 30 × 50. LCD lebih lebar dari papan dan menjorok ke kiri dan atas, jadi **casing (Tahap 5) belum cocok** untuk versi dot matrix ini dan akan dirancang ulang.

Semua posisi berasal dari satu file, [hardware/dotmatrix/tata_letak.py](hardware/dotmatrix/tata_letak.py). Kalau diubah, jalankan `python3 hardware/dotmatrix/tata_letak.py` untuk memperbarui panduan HTML, data JSON, dan templat (PDF dibuat kalau PyMuPDF terpasang; kalau tidak, cetak file SVG-nya dari browser dengan skala 100 %).

### 4.B PCB cetak

Desain KiCad ada di [hardware/pcb/](hardware/pcb/). File siap pesan sudah tersedia di [hardware/pcb/hasil/](hardware/pcb/hasil/) (Gerber `.zip` untuk JLCPCB atau pabrik lain, PDF cetak 1:1, gambar 3D). Langkah memesan, cek cetak kertas 1:1, dan merakit: [doc/pcb-papan-induk.md](doc/pcb-papan-induk.md).

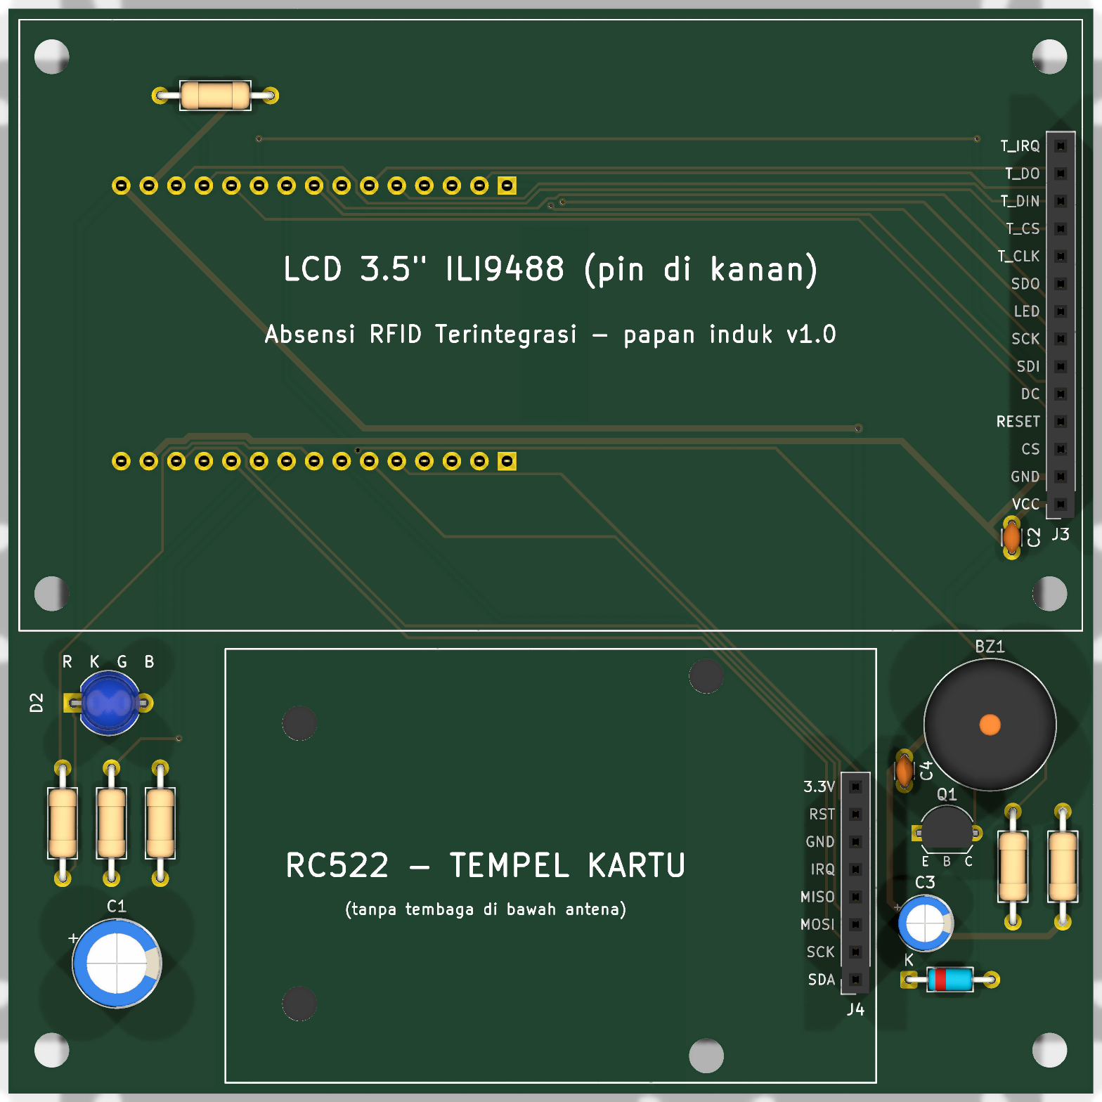
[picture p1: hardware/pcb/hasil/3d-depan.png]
PCB tampak depan (render 3D)


---

## Tahap 5 — Casing cetak 3D

Casing dua bagian (depan + tutup belakang, 105,8 × 113,8 × 41,2 mm) dibuat di OpenSCAD dari ukuran PCB, dengan jendela LCD, area **TEMPEL KARTU**, tabung cahaya LED, lubang USB-C di samping, lubang tombol EN/BOOT, dan gantungan dinding.

1. File cetak: [hardware/casing/hasil/casing-depan.stl](hardware/casing/hasil/casing-depan.stl) dan [hardware/casing/hasil/casing-belakang.stl](hardware/casing/hasil/casing-belakang.stl), untuk **PCB dot matrix** (bawaan). Untuk PCB cetak, ubah `versi = "pcb"` di [hardware/casing/casing.scad](hardware/casing/casing.scad) lalu buat ulang STL.
2. Saran cetak: **PETG**, layer 0,2 mm, infill 20–30 %, sisi luar menempel ke bed, tanpa support.
3. Baut per unit: spacer M3 11 mm F-F ×8, baut M3×25 ×8, M3×5 ×8, M3×30 ×4.

Panduan lengkap (pesan ke jasa cetak, urutan merakit, cara mengubah ukuran): [doc/casing.md](doc/casing.md).

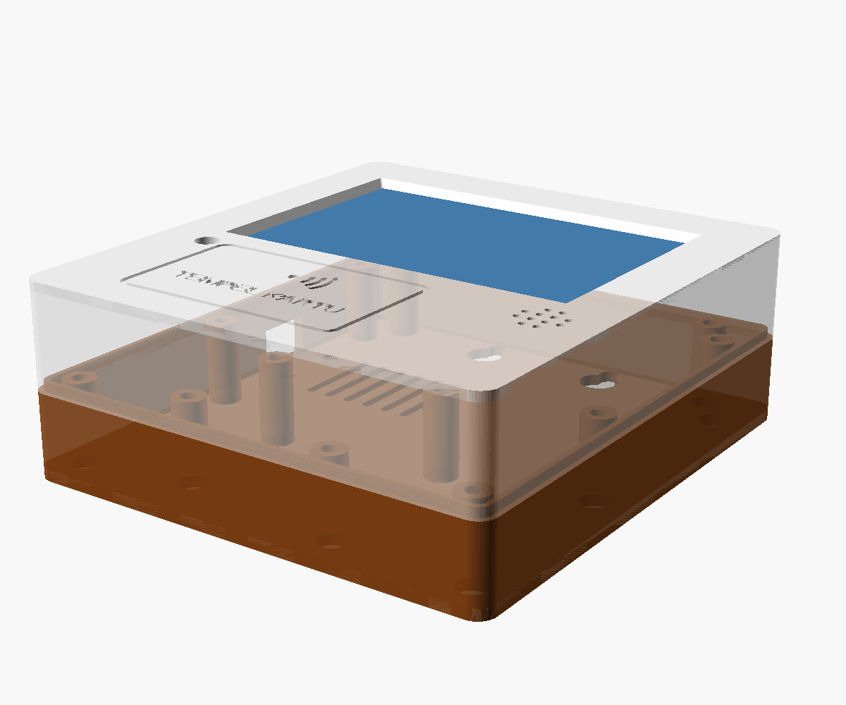
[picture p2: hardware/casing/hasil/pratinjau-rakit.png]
Casing tampak rakitan


---

## Pemecahan masalah

| Gejala | Penyebab / solusi |
|---|---|
| Layar menampilkan kode `E..` | Lihat tabel [kode error](#28-kode-error-di-layar) |
| `Sketch too big` | Partition Scheme belum **Minimal SPIFFS (1.9MB APP with OTA)** |
| `fork/exec .../ctags: bad CPU type` (Mac) | Rosetta 2 belum terpasang |
| Upload gagal di 921600 baud | Chip CH340: pakai 460800 atau 115200 |
| Tertahan di `Connecting....` | Tahan **BOOT** sampai upload mulai |
| `Failed to communicate with the flash chip` | Ada kabel menahan pin boot: jangan pakai GPIO12, dan GPIO2 hanya untuk LED LCD |
| `Resource busy` (Mac/Linux) | Port dipakai Serial Monitor. Tutup monitor, atau pakai `firmware/upload.sh` (menghentikannya otomatis) |
| Layar putih polos | Kabel CS, RESET, DC, SDI, SCK |
| Layar gelap | Kabel LED LCD ke GPIO2 lepas, atau firmware lama (< 1.3.0) |
| Sentuhan meleset | Kalibrasi ulang layar |
| `RFID: tidak terdeteksi (versi 0x00)` | Ada kabel RC522 tertukar (sering SDA dan SCK) atau lepas. Jalankan `tes_rfid` |
| Versi `0xFF` | RC522 tidak menjawab: cek 3,3 V, GND, dan solderan header RC522 |
| Versi `0xEE` | Kabel MOSI dan MISO bersentuhan. Jalankan `tes_miso` |
| Tes koneksi gagal | Base URL harus diawali `http://` atau `https://`, tanpa `/` di akhir dan tanpa `/ping`. WiFi harus 2,4 GHz. Untuk server di laptop: izinkan port di firewall |
| Kartu "tidak terdaftar" | Daftarkan kartunya di website (Tahap 3) |

Lebih banyak: [doc/skema-lengkap.md](doc/skema-lengkap.md#9-troubleshooting), [api/README.md](api/README.md), [contoh-integrasi/README.md](contoh-integrasi/README.md).

---

## Struktur folder

```
README.md                 ← panduan ini
LICENSE, NOTICE           ← lisensi Apache-2.0
firmware/
  absensi/                ← firmware alat (absensi.ino, config.h, tft_setup.h, ...)
  tes/                    ← sketsa tes: tes_touch, tes_miso, tes_rfid
  upload.sh, monitor.sh   ← compile/upload & monitor serial (Mac/Linux)
api/                      ← server acuan Laravel + panel admin
contoh-integrasi/         ← contoh server PHP & Node, skrip pemeriksa, koleksi Postman
CHANGELOG.md              ← riwayat perubahan firmware, server, dokumentasi
hardware/
  dotmatrix/              ← tata letak PCB dot matrix (tata_letak.py) + templat 1:1
  pcb/                    ← PCB cetak (KiCad 10): buat_pcb.py, rute.py, buat.sh, hasil/
  casing/                 ← casing 3D (OpenSCAD): casing.scad, buat.sh, hasil/
doc/
  integrasi-aplikasi.md   ← panduan integrasi ke aplikasi lain (6 fitur wajib, Postman)
  spesifikasi-api.md      ← kontrak API alat ↔ website
  skema-lengkap.md        ← kabel prototipe (acuan pin)
  rakit-lengkap.html      ← panduan interaktif kabel prototipe
  rakit-dotmatrix.html    ← panduan interaktif PCB dot matrix (papan 1 sisi 30 × 50)
  panduan-pengguna.md     ← panduan pengguna/klien: absen, mode, menu, kode error, update, perawatan
  pcb-papan-induk.md      ← PCB cetak: pesan, cek, rakit
  casing.md               ← casing: cetak, baut, rakit
```

---

## Untuk kontributor

- **Firmware:** `cd firmware && ./upload.sh -c` untuk memastikan kode tetap bisa dikompilasi.
- **Server:** `cd api && php artisan test --compact` (butuh database `absensi_alat_test`), lalu `vendor/bin/pint`.
- **Contoh integrasi:** `contoh-integrasi/tes/cek-server.sh` terhadap contoh PHP dan Node.
- **PCB cetak:** ubah [hardware/pcb/buat_pcb.py](hardware/pcb/buat_pcb.py), jalankan `hardware/pcb/buat.sh` (saat ini skrip memakai lokasi KiCad di macOS dan mengunduh Java + Freerouting untuk Mac Apple Silicon ke `hardware/pcb/alat/`). DRC harus 0 pelanggaran.
- **Casing:** ubah [hardware/casing/casing.scad](hardware/casing/casing.scad), jalankan `hardware/casing/buat.sh` (butuh `openscad` di PATH). Semua cek tabrakan harus `ok`.
- Teks untuk pengguna dan komentar kode memakai **bahasa Indonesia**.
- Kirim laporan hasil rakit (foto, ukuran yang meleset) lewat *Issues*: sangat membantu bagian yang belum diuji fisik.

---

## Lisensi

[Apache License 2.0](LICENSE). Lihat juga [NOTICE](NOTICE) untuk bagian pihak ketiga.

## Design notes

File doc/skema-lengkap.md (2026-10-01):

# Skema Kabel Prototipe

Bagian dari [Absensi RFID Terintegrasi](../README.md) — **Tahap 1**.

Semua sambungan kabel **LCD 3.5" + touch, buzzer, LED RGB, dan RFID RC522** ke ESP32 DOIT DevKit V1 (30 pin) yang dipasang di **expansion board 30 pin** (header G-V-S per pin), memakai kabel jumper female-female. Tidak perlu breadboard: setiap pin hanya untuk satu kabel.

Versi interaktif (gambar kabel, sorotan per langkah, centang progres): [rakit-lengkap.html](rakit-lengkap.html). Unduh repositori lalu buka file itu di browser.

> **Aturan utama:** semua komponen memakai **3,3 V**. Jangan ada kabel yang masuk ke pin **5V**. Selama memasang kabel, **cabut kabel USB**.

---

## Daftar Isi

1. [Tabel semua sambungan](#1-tabel-semua-sambungan)
2. [Daya: kenapa semua 3,3 V](#2-daya-kenapa-semua-33-v)
3. [Peta header expansion](#3-peta-header-expansion)
4. [Mengenali komponen](#4-mengenali-komponen)
5. [Urutan pemasangan dan tes](#5-urutan-pemasangan-dan-tes)
6. [Tips kabel female-female](#6-tips-kabel-female-female)
7. [Cek sebelum colok USB](#7-cek-sebelum-colok-usb)
8. [Pin yang tidak boleh dipakai](#8-pin-yang-tidak-boleh-dipakai)
9. [Troubleshooting](#9-troubleshooting)
10. [Ringkasan GPIO untuk program](#10-ringkasan-gpio-untuk-program)

---

## 1. Tabel semua sambungan

Cara membaca kolom "Ke expansion":
- **D17, baris S** = di deret pin, cari tulisan **D17**. Setiap tulisan punya 3 pin berjajar: **S** (sinyal, paling luar dekat tepi board), **V** (tegangan, tengah), **G** (GND, paling dalam dekat ESP32).
- **Header daya** = blok pin 2×4 bertuliskan **5V 5V 3.3V 3.3V** dan **GND GND GND GND**.

Expansion board lain mungkin menamai atau mengurutkan pin berbeda. Yang penting **GPIO-nya sama** (lihat [bagian 10](#10-ringkasan-gpio-untuk-program)).

### LCD 3.5" ILI9488

| Pin LCD | Ke expansion | Catatan |
|---|---|---|
| VCC | Header daya, pin **3.3V** | **Wajib 3,3 V**, dan jumper J1 di LCD harus disambung (lihat [bagian 2](#2-daya-kenapa-semua-33-v)) |
| GND | Header daya, pin **GND** | Pin GND mana saja |
| CS | **D5**, baris S | |
| RESET | **D4**, baris S | |
| D/C (DC) | **D16**, baris S | **Bukan D2** |
| SDI (MOSI) | **D23**, baris S | |
| SCK | **D18**, baris S | |
| LED | **D2**, baris S | Lampu latar. Firmware menyalakan dan meredupkannya lewat D2 |
| SDO (MISO) | *tidak disambung* | |

### Touch (di modul LCD yang sama)

| Pin touch | Ke expansion | Catatan |
|---|---|---|
| T_CLK | **D22**, baris S | Boleh juga ke pin D22 di header I2C (GPIO sama) |
| T_CS | **D15**, baris S | |
| T_DIN | **D21**, baris S | Boleh juga ke pin D21 di header I2C (GPIO sama). Di modul lain bernama T_IN |
| T_DO | **D19**, baris S | Di modul lain bernama T_OUT |
| T_IRQ | *tidak disambung* | |

Touch memakai pin sendiri (tidak berbagi kabel dengan layar), dibaca firmware dengan cara bit-bang.

### Buzzer aktif

| Kaki buzzer | Ke expansion | Catatan |
|---|---|---|
| **+** (kaki panjang, ada tanda +) | **D17**, baris S | |
| **−** (kaki pendek) | **D17**, baris **G** | Pin G mana saja |

### LED RGB 5 mm common cathode

| Kaki LED | Ke expansion | Catatan |
|---|---|---|
| Katoda (**kaki terpanjang**) | **D25**, baris **G** | Pin G mana saja |
| R (merah) | **D25**, baris S | Sebaiknya lewat resistor 220–330 Ω |
| G (hijau) | **D26**, baris S | Sebaiknya lewat resistor 220–330 Ω |
| B (biru) | **D27**, baris S | Sebaiknya lewat resistor 220–330 Ω |

### RFID RC522 (modul 60 × 40 mm)

| Pin RC522 | Ke expansion | Catatan |
|---|---|---|
| **3.3V** | **D34**, baris **V** | Jumper JUMP harus di 3.3V. **Jangan ke 5V** |
| GND | **D34**, baris **G** | Pin G mana saja |
| SDA (kadang tertulis SS atau NSS) | **D33**, baris S | Ini chip select SPI, bukan SDA I2C |
| SCK | **D14**, baris S | |
| MOSI | **D13**, baris S | |
| MISO | **D35**, baris S | D35 hanya bisa input, cocok untuk MISO |
| RST | **D32**, baris S | |
| IRQ | *tidak disambung* | |

Kolom D34 dipakai untuk daya RFID karena pin S D34 memang tidak dipakai: **"kolom D34 = daya RFID"**. RFID memakai jalur SPI sendiri (D14, D13, D35), terpisah dari LCD (D18, D23).

---

## 2. Daya: kenapa semua 3,3 V

| Hal | Penjelasan |
|---|---|
| Sumber daya | Cukup **satu kabel USB ke port ESP32**. Kabel ini sekaligus untuk upload dan monitor serial |
| Jaringan 3,3 V | Pin **3.3V** di header daya dan semua pin **V** (kalau JUMP di 3.3V) mendapat daya dari regulator 3,3 V di ESP32 |
| Pin 5V expansion | Pada expansion board jenis ini, header 5V baru bertegangan kalau USB-C atau DC jack **expansion** sendiri dicolok. Rangkaian ini **tidak memakai 5V sama sekali** |
| Jumper **JUMP** | Mengatur tegangan semua pin **V**. **Harus di posisi 3.3V** (menutup pin 3.3V dan V). Kalau di 5V dan expansion diberi daya, RC522 bisa rusak |
| LCD, jumper **J1** | Menurut skema resmi modul LCD: VCC 5 V → J1 dibuka (regulator U1 di LCD menurunkan ke 3,3 V); VCC 3,3 V → **J1 disambung**. Rangkaian ini memberi 3,3 V, jadi **sambungkan J1 dengan timah**. Setelah J1 disambung, **VCC tidak boleh lagi 5 V** |
| RFID RC522 | Chip MFRC522 hanya tahan **3,3 V**. 5 V bisa merusaknya |
| Buzzer | Buzzer aktif 3–5 V. Di 3,3 V bunyinya sedikit lebih pelan, itu normal |
| LED RGB | Dinyalakan langsung dari pin GPIO (3,3 V) |
| Lampu LCD (LED) | Pin LED LCD masuk ke transistor di modul LCD (lewat resistor 1 kΩ), jadi arus dari D2 hanya ± 2–3 mA |

---

## 3. Peta header expansion

Setiap tulisan pin (misalnya D17) punya satu kolom berisi 3 pin: **S, V, G**. Di kedua deret, **S selalu paling luar** (dekat tepi board) dan **G selalu paling dalam** (dekat ESP32).

Keterangan isi sel: `.` = kosong, `-` = tidak dipakai, `xx` = **jangan dipakai**.

### 3a. Orientasi normal: colokan DC dan USB-C expansion di KANAN

```
Deret atas (deret LCD): LCD, touch, buzzer
         D23   D22   TX0   RX0   D21   D19   D18   D5    D17   D16   D4    D2    D15
  S      SDI   T_CLK -     -     T_DIN T_DO  SCK   CS    BZ+   DC    RST   BL    T_CS
  V      .     .     .     .     .     .     .     .     .     .     .     .     .
  G      .     .     .     .     .     .     .     .     BZ-   .     .     .     .

        ┌──────────────── ESP32 DevKit (port USB ESP32 di kanan) ────────────────┐
        └────────────────────────────────────────────────────────────────────────┘

Deret bawah: RFID, LED RGB
         EN    VP    VN    D34   D35   D32   D33   D25   D26   D27   D14   D12   D13
  G      .     .     .     RFGND .     .     .     LED-  .     .     .     .     .
  V      .     .     .     RF3V3 .     .     .     .     .     .     .     .     .
  S      xx    -     -     -     MISO  RST   SDA   R     Hijau Biru  SCK   xx    MOSI

Header daya 2×4 (pojok kanan bawah):     5V    5V    3.3V  3.3V
                                         GND   GND   GND   GND
  LCD VCC → 3.3V, LCD GND → salah satu GND. LCD LED → D2 baris S (bukan 3.3V).
Header I2C (kanan atas): kolom D22, D21, VCC, GND, masing-masing 2 pin.
```

- Deret atas: `RST` = RESET LCD, `DC` = D/C LCD, `BL` = LED LCD (lampu latar), `BZ+`/`BZ-` = kaki buzzer.
- Deret bawah: `MISO`, `RST`, `SDA`, `SCK`, `MOSI` = pin RC522. `RF3V3`/`RFGND` = daya RC522. `R`, `Hijau`, `Biru` = kaki warna LED, `LED-` = katoda LED.

### 3b. Board diputar 180°: colokan DC dan USB-C expansion di KIRI

Semua posisi berputar: deret EN … D13 pindah ke atas, deret D23 … D15 pindah ke bawah, dan urutan kiri-kanan terbalik. **Tulisan di board tetap sama**, jadi selalu cocokkan dengan tulisannya.

```
Deret atas sekarang deret EN … D13: RFID, LED RGB
         D13   D12   D14   D27   D26   D25   D33   D32   D35   D34   VN    VP    EN
  S      MOSI  xx    SCK   Biru  Hijau R     SDA   RST   MISO  -     -     -     xx
  V      .     .     .     .     .     .     .     .     .     RF3V3 .     .     .
  G      .     .     .     .     .     LED-  .     .     .     RFGND .     .     .

        ┌──────────────── ESP32 DevKit (port USB ESP32 di kiri) ─────────────────┐
        └────────────────────────────────────────────────────────────────────────┘

Deret bawah sekarang deret D23 … D15: LCD, touch, buzzer
         D15   D2    D4    D16   D17   D5    D18   D19   D21   RX0   TX0   D22   D23
  G      .     .     .     .     BZ-   .     .     .     .     .     .     .     .
  V      .     .     .     .     .     .     .     .     .     .     .     .     .
  S      T_CS  BL    RST   DC    BZ+   CS    SCK   T_DO  T_DIN -     -     T_CLK SDI

Header daya 2×4 (pojok kiri atas):  GND   GND   GND   GND    ← baris luar
                                    3.3V  3.3V  5V    5V     ← baris dalam
Header I2C: pindah ke kiri bawah.
```

**Kalau LCD dibalik** (layar menghadap meja): urutan pin LCD tercermin, jadi dari kiri ke kanan terbaca T_IRQ, T_DO, T_DIN, T_CS, T_CLK, SDO, LED, SCK, SDI, DC, RESET, CS, GND, **VCC**. Tetap ikuti tulisan di pin LCD.

---

## 4. Mengenali komponen

### Buzzer aktif (± 12 × 9,5 mm, 2 kaki)
- Kaki **+** lebih **panjang**, dan di badan buzzer biasanya ada tanda **+** di dekat kaki itu.
- Kalau kedua kaki sudah sama panjang, cari tanda + di bagian atas badan.
- Buzzer **aktif**: bagian bawah tertutup rapat (hitam) dan berbunyi sendiri bila diberi 3–5 V. Kalau bagian bawahnya terlihat papan hijau, itu buzzer **pasif**: firmware ini tidak membunyikannya dengan benar, jadi ganti dengan buzzer aktif.
- Stiker di atas buzzer boleh dilepas supaya suaranya lebih keras.

### LED RGB 5 mm common cathode (4 kaki)
- Kaki **terpanjang = katoda (−)**, disambung ke GND.
- Urutan kaki yang paling umum, dilihat dengan kaki menghadap ke bawah: **R, katoda, G, B**.
  - **R** = kaki tunggal di satu sisi katoda.
  - **G** dan **B** = dua kaki di sisi lain katoda (G lebih dekat ke katoda, B paling luar).
- Urutan bisa berbeda antar pabrik. Kalau warnanya tertukar saat dites, tukar kabelnya.
- Cara memastikan jenisnya: hubungkan kaki terpanjang ke GND, lalu sentuhkan satu kaki warna ke 3,3 V lewat resistor 220–330 Ω. Kalau menyala, LED itu **common cathode** (benar). Kalau tidak pernah menyala, kemungkinan **common anode**: ganti LED.

### RFID RC522
- Pin biasanya: **SDA, SCK, MOSI, MISO, IRQ, GND, RST, 3.3V**. Urutan fisiknya bisa berbeda, jadi **selalu ikuti tulisan di papan RC522**.
- **SDA** di RC522 kadang tertulis **SS** atau **NSS**. Ini pin chip select SPI, **bukan** SDA milik I2C. Jangan dicolok ke header I2C.
- **Header pin RC522 harus disolder.** Kalau pin header masih lepas (hanya diselipkan), kabel tidak kontak dengan baik dan RC522 tidak terbaca.
- Modul ini hanya untuk **3,3 V**.

---

## 5. Urutan pemasangan dan tes

Pasang **satu komponen, tes, baru lanjut**. Setiap kali memasang atau memindah kabel: **cabut USB dulu**. Siapkan software dulu ([README Tahap 2.1](../README.md#21-pasang-software)).

### Langkah 1: LCD dan touch
1. Sambungkan jumper **J1** di belakang LCD dengan timah ([bagian 2](#2-daya-kenapa-semua-33-v)).
2. Jumper **JUMP** di expansion di posisi **3.3V**.
3. Pasang kabel sesuai tabel [LCD](#lcd-35-ili9488) dan [touch](#touch-di-modul-lcd-yang-sama) (SDO dan T_IRQ dibiarkan kosong).
4. Upload sketsa tes layar sentuh: dari folder `firmware/`, `./upload.sh tes_touch -m` (atau buka `firmware/tes/tes_touch/tes_touch.ino` di Arduino IDE).
5. Hasil benar: kalibrasi 3 titik, lalu mode menggambar. Titik kuning muncul tepat di bawah stylus.

### Langkah 2: firmware utama
1. Upload firmware utama (`./upload.sh -m`, atau buka `firmware/absensi/absensi.ino` dengan partisi **Minimal SPIFFS (1.9MB APP with OTA)**).
2. Firmware tetap berjalan walau RFID, buzzer, dan LED belum dipasang (layar boot menulis "RFID tidak terdeteksi").
3. Selesaikan panduan pertama kali di layar (WiFi, Base URL, API key). Lihat [README Tahap 2.4–2.5](../README.md#24-siapkan-server-sementara-kalau-website-belum-ada).

### Langkah 3: buzzer (2 kabel)
1. Kaki **−** ke **D17 baris G**.
2. Kaki **+** ke **D17 baris S**.
3. Colok USB. Menu Pengaturan (ikon gir, PIN `2026`) → **Tes buzzer & LED**: buzzer harus berbunyi.

### Langkah 4: LED RGB (4 kabel)
1. Kaki **terpanjang (katoda)** ke **D25 baris G**.
2. Kaki **R** ke **D25 baris S**, **G** ke **D26 baris S**, **B** ke **D27 baris S**.
3. Menu → **Tes buzzer & LED**: LED menyala merah, hijau, biru, lalu putih (masing-masing 0,7 detik, disertai bip).

**Soal resistor:** idealnya setiap kaki warna (R, G, B) diberi resistor **220–330 Ω** secara seri (satu kaki resistor dipelintir ke kaki LED, kaki resistor yang lain masuk ke kabel female). Untuk prototipe boleh tanpa resistor: firmware mengatur pin LED ke kekuatan arus terendah, sehingga arusnya tetap kecil. Ini bukan cara ideal (LED sedikit kurang terang). Di PCB (Tahap 4) resistor sudah termasuk.

### Langkah 5: RFID RC522 (7 kabel)
1. **GND** ke **D34 baris G**.
2. **3.3V** ke **D34 baris V** (cek lagi: JUMP di 3.3V).
3. **SDA** ke **D33**, **SCK** ke **D14**, **MOSI** ke **D13**, **MISO** ke **D35**, **RST** ke **D32** (semua baris S).
4. IRQ dibiarkan kosong.
5. Colok USB. Layar boot harus menulis "RC522 (0x..)" dan monitor serial `RFID: RC522 terdeteksi`.
6. Kalau tidak terdeteksi: menu → **Cek kabel RFID**, atau upload `tes_miso` lalu `tes_rfid` (lihat [Troubleshooting](#rfid-rc522)).
7. Tempelkan kartu rata di atas antena: bunyi bip dan hasil tampil.

---

## 6. Tips kabel female-female

- Kabel female pas untuk pin header (expansion, LCD, RC522), tetapi **longgar di kaki komponen yang tipis** seperti buzzer dan LED.
- Dorong kabel **sampai mentok** ke pangkal kaki.
- Kalau masih goyang: **tekuk sedikit** ujung kaki komponen (huruf L kecil) sebelum dimasukkan, atau **pelintir** kakinya supaya lebih tebal dan menjepit.
- Pastikan **kaki-kaki LED dan buzzer tidak saling bersentuhan**. Kalau perlu, renggangkan kakinya sedikit.
- Tarik pelan setiap kabel setelah dipasang. Kalau lepas dengan mudah, pasang ulang.

---

## 7. Cek sebelum colok USB

- [ ] Jumper **JUMP** di posisi **3.3V**
- [ ] **Tidak ada** kabel di pin **5V** header daya
- [ ] Jumper **J1** di LCD sudah disambung
- [ ] LCD **VCC** di pin **3.3V** header daya, LCD **LED** di **D2 baris S**, LCD **GND** di GND
- [ ] RFID **3.3V** di **D34 baris V**, RFID **GND** di **D34 baris G**
- [ ] Semua kabel sinyal di baris **S** (paling luar)
- [ ] Buzzer **+** di D17 S, **−** di D17 G (tidak tertukar)
- [ ] LED: **kaki terpanjang** di D25 G
- [ ] Tidak ada kabel di **D12, TX0, RX0, EN** (D2 hanya untuk LED LCD)
- [ ] Kaki LED dan kaki buzzer tidak saling bersentuhan
- [ ] Hanya **satu** kabel USB, dicolok ke **port di ESP32**

---

## 8. Pin yang tidak boleh dipakai

| Pin | Alasan |
|---|---|
| **D12** | Pin boot yang menentukan tegangan flash. Kalau tertarik HIGH saat menyala, ESP32 gagal boot. **Jangan pernah dipakai** |
| **D2** | Pin boot + LED biru bawaan board. **Hanya untuk LED LCD (lampu latar).** Jangan pindahkan DC atau sinyal lain ke sini: DC LCD menahan D2 HIGH saat reset sehingga upload gagal. Pin LED LCD aman karena tidak menahan D2 HIGH |
| **TX0, RX0** | Jalur USB ke komputer (upload dan monitor serial) |
| **EN** | Tombol reset ESP32 |
| D34, VP, VN | Hanya bisa input. Tidak dipakai (pin V dan G di kolom D34 dipakai untuk daya RFID) |
| **5V** (header daya) | Tidak ada komponen 5 V di rangkaian ini |

Pin S yang masih kosong hanya **D34, VP, VN**, dan ketiganya input saja (misalnya untuk tombol, dengan resistor pull-up luar).

---

## 9. Troubleshooting

### Umum

| Gejala | Periksa |
|---|---|
| Upload gagal `Failed to communicate with the flash chip` | Ada kabel yang menahan pin boot. Pastikan tidak ada kabel di **D12** dan D2 hanya berisi LED LCD. Cabut kabel komponen yang baru dipasang, upload, lalu pasang lagi |
| Upload tertahan `Connecting....` | Tahan tombol **BOOT** sampai persentase upload muncul |
| Upload gagal `Resource busy` | Tutup Serial Monitor Arduino IDE, atau pakai `firmware/upload.sh` |
| ESP32 restart terus (brownout) | Ada korsleting 3,3 V ke GND. Cabut USB, cek kabel V dan G, dan kaki komponen yang bersentuhan |
| Ada komponen terasa **panas** | **Cabut USB segera.** Biasanya kabel daya tertukar atau masuk 5V |

### LCD dan touch

| Gejala | Periksa |
|---|---|
| Layar putih polos | CS (D5), DC (D16), RESET (D4), SCK (D18), SDI (D23) |
| Layar gelap total | LED ke D2 baris S, VCC ke 3.3V, GND, dan J1 sudah disambung |
| Layar redup sendiri | Normal: setelah diam 60 detik lampu meredup. Tempel kartu atau sentuh layar untuk menyalakannya |
| Warna terbalik (putih jadi hitam) | Tambahkan `#define TFT_INVERSION_ON` (atau `TFT_INVERSION_OFF`) di `firmware/absensi/tft_setup.h` |
| Merah dan biru tertukar | Tambahkan `#define TFT_RGB_ORDER TFT_BGR` (atau `TFT_RGB`) di `tft_setup.h` |
| Touch tidak merespons | T_CLK (D22), T_DIN (D21), T_DO (D19), T_CS (D15) |
| Titik sentuh meleset | Kalibrasi ulang (menu **Kalibrasi layar**) |

### Buzzer

| Gejala | Periksa |
|---|---|
| Tidak bunyi | Kaki + dan − tertukar? + harus ke D17 **S**. Kabel longgar di kaki buzzer? |
| Bunyi terus sejak dicolok | Kaki + masuk ke baris **V**, bukan S. Pindahkan ke S |
| Bunyi pelan | Normal untuk buzzer 3–5 V yang diberi 3,3 V. Lepas stikernya |
| Hanya "klik" pelan | Buzzer **pasif**. Ganti dengan buzzer aktif |

### LED RGB

| Gejala | Periksa |
|---|---|
| Tidak menyala sama sekali | Kaki **terpanjang** ke G? Kabel longgar? Kalau sudah benar, kemungkinan LED **common anode**: ganti |
| Warna tertukar (merah jadi hijau, dll.) | Urutan kaki LED berbeda. Tukar kabelnya |
| Satu warna tidak menyala | Kabel warna itu longgar, atau salah kolom (D25/D26/D27) |
| Redup | Normal kalau tanpa resistor dan arus dibatasi firmware |

### RFID RC522

Buka menu **Cek kabel RFID** di alat, atau upload `tes_miso` dan `tes_rfid`.

| Versi terbaca | Arti |
|---|---|
| Nilai lain, misalnya `0x91`, `0x92` (asli), `0x82`, `0x88`, `0x12`, `0xB2` (klon) | RC522 menjawab, kabel baik |
| `0x00` | Ada kabel tertukar (sering **SDA dan SCK**) atau lepas. `tes_rfid` mencoba semua susunan kabel |
| `0xFF` | RC522 tidak menjawab: cek 3,3 V (D34 V), GND (D34 G), JUMP di 3.3V, dan header RC522 sudah disolder |
| `0xEE` | Kabel **MOSI (D13) dan MISO (D35) bersentuhan**. Pisahkan konektornya, cek dengan `tes_miso` |

| Gejala | Periksa |
|---|---|
| Terdeteksi tapi kartu tidak terbaca | Tempelkan kartu rata di atas antena RC522, jarak 0–3 cm, tahan 1 detik. Jauhkan dari benda logam |
| Kadang terbaca, kadang tidak | Kabel longgar, terutama SCK dan MISO. Tekan ulang semua kabel RC522 |
| RC522 panas | **Cabut USB.** Kemungkinan 3,3 V/GND tertukar atau masuk 5 V |

---

## 10. Ringkasan GPIO untuk program

Sama dengan [firmware/absensi/config.h](../firmware/absensi/config.h) dan [tft_setup.h](../firmware/absensi/tft_setup.h).

| Fungsi | GPIO | Pin expansion |
|---|---|---|
| LCD CS / DC / RST | 5 / 16 / 4 | D5 / D16 / D4 |
| LCD SCK / MOSI | 18 / 23 | D18 / D23 |
| LCD LED (lampu latar, PWM) | 2 | D2 |
| Touch CLK / DIN / DOUT / CS | 22 / 21 / 19 / 15 | D22 / D21 / D19 / D15 |
| Buzzer | 17 | D17 |
| LED R / G / B | 25 / 26 / 27 | D25 / D26 / D27 |
| RFID SS(SDA) / SCK / MOSI / MISO / RST | 33 / 14 / 13 / 35 / 32 | D33 / D14 / D13 / D35 / D32 |
| Tombol BOOT | 0 | (tombol di board) |

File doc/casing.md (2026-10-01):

# Casing cetak 3D

Bagian dari [Absensi RFID Terintegrasi](../README.md) — **Tahap 5**.

Casing dua bagian untuk papan 10 × 10 cm: **PCB dot matrix** ([rakit-dotmatrix.html](rakit-dotmatrix.html), bawaan) atau **PCB cetak** ([pcb-papan-induk.md](pcb-papan-induk.md)). Dibuat di OpenSCAD dari ukuran papan dan gambar resmi LCD, jadi posisi lubang sama persis dengan papan. Pilih versinya dengan parameter `versi` di `casing.scad` (`dotmatrix` atau `pcb`): posisi USB, tombol EN/BOOT, LED, dan RC522 bergeser ± 1 mm di antara keduanya.

> **Status (1 Okt 2026):** desain selesai, lolos cek tabrakan dengan PCB, LCD, RC522, ESP32, buzzer, elko, dan LED. **Belum dicetak.** Cetak **1 set dulu** untuk dicoba sebelum mencetak banyak.

---

## 1. File

| File | Isi |
|---|---|
| `hardware/casing/hasil/casing-depan.stl` | **Kirim ke jasa cetak.** Panel depan + dinding |
| `hardware/casing/hasil/casing-belakang.stl` | **Kirim ke jasa cetak.** Tutup belakang |
| `hardware/casing/hasil/pratinjau-*.png` | Gambar depan, belakang, bagian dalam, rakitan |
| `hardware/casing/casing.scad` | Desain (buka di OpenSCAD). Semua ukuran di bagian atas file |
| `versi` di `casing.scad` | `dotmatrix` (bawaan, untuk PCB dot matrix) atau `pcb` (PCB cetak). Posisi USB, tombol EN/BOOT, LED, dan RC522 bergeser ± 1 mm |
| `hardware/casing/buat.sh` | Membuat ulang STL + gambar + cek tabrakan: `cd hardware/casing && ./buat.sh` (butuh `openscad` di PATH) |

Melihat 3D: buka `casing.scad` di OpenSCAD, pilih **bagian** (depan / belakang / rakit) di panel Customizer, tekan **F5**.

---

## 2. Bentuk

Ukuran luar **105.8 × 113.8 × 41.2 mm** (lebar × tinggi × tebal), sudut membulat.

| Bagian | Isi |
|---|---|
| **Depan** (tebal 22.8 mm) | Jendela LCD selebar area sentuh (77.8 × 50.6 mm, tepi miring), area **TEMPEL KARTU** (garis kartu + simbol, diukir), lubang LED + tabung cahaya, 12 lubang suara buzzer, 4 tiang baut |
| **Belakang** (tebal 20.4 mm) | 12 tiang tempat PCB duduk, lubang **USB-C di sisi kiri**, lubang **EN** dan **BOOT** (tekan dengan tusuk gigi), 2 lubang gantungan dinding, ventilasi di belakang ESP32, tulisan EN dan BOOT |

Kedua bagian bertemu dengan sambungan berundak (rapat, tidak bergeser). PCB terjepit di antara tiang belakang dan tiang depan.

Panel di atas RC522 setebal 2 mm, dan kartu berjarak ± 6–7 mm dari antena. Ini masih jauh di dalam jangkauan RC522 (± 3–5 cm).

---

## 3. Pesan ke jasa cetak

Contoh pesan untuk jasa cetak 3D (lewat WhatsApp atau email):

> Halo, saya mau cetak 2 file STL (casing alat elektronik, 1 set dulu):
> - casing-depan.stl (105.8 × 113.8 × 22.8 mm)
> - casing-belakang.stl (105.8 × 113.8 × 20.4 mm)
>
> Bahan **PETG**, warna bebas (saran: hitam atau putih). Layer 0.2 mm, infill 20–30 %, dinding 3 lapis.
> Arah cetak: **sisi luar di bawah** (panel depan menempel ke bed, tutup belakang juga), tanpa support.
> Lubang baut sengaja kecil (pilot 2.6 mm untuk sekrup M3), mohon tidak diperbesar.

| Pilihan | Saran | Alasan |
|---|---|---|
| Bahan | **PETG** | Lebih kuat dan tahan panas daripada PLA (aman di ruangan panas / dekat jendela) |
| Alternatif | PLA+ | Lebih murah, cukup untuk dalam ruangan ber-AC |
| Hindari | Resin | Getas untuk casing yang dibaut, dan lebih mahal untuk ukuran ini |
| Arah cetak | Sisi luar di bawah | Permukaan depan rata dan rapi, tidak perlu support |

---

## 4. Belanja tambahan (per unit)

| Barang | Jumlah | Untuk |
|---|---|---|
| Spacer M3 **11 mm** female-female (kuningan / nilon) | 8 | 4 untuk LCD, 4 untuk RC522 |
| Baut M3 × **25 mm** | 8 | Dari belakang casing, lewat PCB, ke spacer |
| Baut M3 × **5 mm** | 8 | LCD dan RC522 ke spacer |
| Baut M3 × **30 mm** | 4 | Menyatukan casing depan dan belakang |
| Sekrup dinding + fisher | 2 | Gantungan dinding (kepala sekrup maks. Ø 8 mm, batang maks. Ø 4 mm) |

Untuk 5 unit: 40 spacer, 40 baut M3×25, 40 baut M3×5, 20 baut M3×30.

> Kalau lubang RC522 di modul Anda tidak sejajar dengan tiangnya (lihat [pcb-papan-induk.md §5](pcb-papan-induk.md)), RC522 tetap tertahan header dan panel depan. Spacer RC522 boleh tidak dipasang.

---

## 5. Merakit

1. Solder semua komponen ke PCB. **LED RGB dipasang tinggi:** kubah LED ± 13 mm di atas PCB (kaki jangan dipotong pendek), supaya masuk ke tabung cahaya di panel depan.
2. Letakkan PCB di atas tiang **tutup belakang** (sisi ESP32 menghadap ke tutup belakang, USB ke lubang di sisi kiri).
3. Pasang 8 spacer 11 mm di sisi depan PCB (4 lubang LCD, 4 lubang RC522), lalu kencangkan dengan baut M3×25 **dari luar tutup belakang**.
4. Colokkan ESP32 (dari belakang PCB, sebelum langkah 2), LCD, dan RC522. Kencangkan LCD dan RC522 ke spacer dengan baut M3×5.
5. Tes alat dulu (colok USB lewat lubang samping).
6. Pasang **casing depan**, lalu kencangkan 4 baut M3×30 dari belakang: 2 di pita atas, 2 di pojok bawah (lewat PCB). Baut langsung masuk ke plastik (lubang pilot 2.6 mm), jangan terlalu kencang.
7. Pasang 2 sekrup di dinding (jarak **30 mm**, sejajar), gantung alat lewat lubang kunci di belakang lalu geser ke bawah.

---

## 6. Kalau perlu diubah

Semua ukuran ada di atas `hardware/casing/casing.scad`, contoh:

| Masalah | Ubah |
|---|---|
| Kartu kurang terbaca | `panel` (tebal panel depan) jadi 1.5 |
| Casing terlalu sempit / longgar ke PCB | `jarak_pcb` |
| ESP32 menyentuh tutup belakang | `ruang_esp32` |
| LCD tertekan panel / longgar | `celah_lcd` |
| Lubang baut terlalu sempit / longgar | `lubang_ulir` (pilot), `lubang_baut` (tembus) |

Setelah mengubah, jalankan `./buat.sh` (STL baru + cek tabrakan otomatis).

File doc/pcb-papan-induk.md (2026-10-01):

# PCB cetak (papan induk)

Bagian dari [Absensi RFID Terintegrasi](../README.md) — **Tahap 4.B**. Pilihan lain yang lebih murah: PCB dot matrix ([rakit-dotmatrix.html](rakit-dotmatrix.html), Tahap 4.A). Nilai beberapa komponen di versi dot matrix berbeda (2N3904, FR107, 220 µF, 22 µF, 47 nF, tanpa R6), tetapi rangkaiannya sama.

PCB ini menggantikan kabel jumper. Modul prototipe (ESP32 DevKit 30 pin, LCD 3.5", RC522) **dicolokkan** ke PCB lewat header female, tidak disolder langsung. Jadi:

- **Firmware tidak berubah.** Semua pin sama dengan [skema-lengkap.md §10](skema-lengkap.md#10-ringkasan-gpio-untuk-program).
- Modul yang rusak tinggal dicabut dan diganti.
- Semua komponen tambahan **through-hole** (berkaki panjang), mudah disolder sendiri.
- Expansion board tidak dipakai lagi.
- Yang dipesan ke pabrik hanya **PCB kosong**. Komponen dibeli dan disolder sendiri.

> **Status (1 Okt 2026):** desain KiCad selesai, DRC bersih (0 pelanggaran, semua jalur tersambung). **Belum dipesan.** Sebelum memesan, lakukan cek cetak 1:1 di §6.

---

## 1. File

Semua ada di folder `hardware/pcb/`:

| File | Isi |
|---|---|
| `absensi-pcb.kicad_pro` | **Buka ini di KiCad** (dobel klik), lalu buka PCB Editor. Tampilan 3D: menu View > 3D Viewer |
| `absensi-pcb.kicad_pcb` | Desain PCB: bentuk papan, komponen, jalur |
| `hasil/absensi-pcb-jlcpcb.zip` | **File pesanan** (Gerber + bor). Upload ini ke JLCPCB |
| `hasil/absensi-pcb-gko.zip` | Isi sama, nama gaya Protel/Altium (`.GTL`, `.GKO` untuk outline, `.DRL`) untuk pabrik yang meminta `.GKO` |
| `hasil/absensi-pcb-gbr.zip` | Isi sama, semua lapisan berekstensi `.gbr` |
| `hasil/cetak-depan.pdf` | Cetak 1:1 sisi depan (LCD, RFID, LED, buzzer) |
| `hasil/cetak-belakang.pdf` | Cetak 1:1 sisi belakang (ESP32), sudah dicerminkan |
| `hasil/3d-depan.png`, `hasil/3d-belakang.png` | Gambar 3D |
| `buat_pcb.py` | Semua ukuran dan posisi komponen (ubah di sini, bukan di KiCad) |
| `buat.sh` | Membuat ulang semuanya: `cd pcb && ./buat.sh` |

`buat.sh` membuat papan dari `buat_pcb.py`, menarik jalur otomatis (Freerouting), menambah tuangan GND, memeriksa DRC, lalu membuat file pesanan, file cetak, dan gambar 3D. Freerouting dan Java portabel diunduh sekali ke `hardware/pcb/alat/` (± 130 MB, tidak dipasang ke sistem).

> Kalau desain diubah langsung di KiCad lalu `buat.sh` dijalankan, perubahan itu **tertimpa**. Ubah ukuran di `buat_pcb.py`, atau berhenti memakai `buat.sh` dan lanjutkan di KiCad saja.

---

## 2. Tata letak

Papan **100 × 100 mm**, 2 lapis. Dilihat dari depan:

```
┌──────────────────────────────────┐
│ ○                              ○ │  ○ = lubang M3 (4 lubang LCD, dipakai juga untuk casing)
│   ┌──────────────────────────┐ ▐ │
│   │   LCD 3.5" (depan)       │ ▐ │  ▐ = header LCD 14 pin (VCC paling bawah)
│   │   ESP32 di BELAKANG,     │ ▐ │
│   │   USB di tepi kiri       │ ▐ │
│ ○ └──────────────────────────┘ ○ │
│ LED  ┌───────────────────┐ ▐ 🔊  │  ▐ = header RC522 8 pin (SDA paling bawah)
│ R1-3 │ RC522 (depan)     │ ▐ Q1  │
│ C1   │ TEMPEL KARTU      │ ▐ D1  │
│ ○    └───────────────────┘   ○   │  ○ = 2 lubang casing + 4 lubang RC522
└──────────────────────────────────┘
```

| Bagian | Posisi | Alasan |
|---|---|---|
| LCD | Depan, atas. PCB LCD 98 × 56.34, pin di kanan | Sesuai gambar resmi LCD |
| RC522 | Depan, bawah LCD, pin di kanan | Area kartu di bawah layar |
| Area antena RC522 | **Tanpa tembaga** di kedua sisi | Tembaga melemahkan pembacaan kartu |
| ESP32 DevKit | **Belakang**, USB di tepi kiri papan, komponen menghadap keluar | USB bisa dicolok dari samping casing |
| Area antena WiFi ESP32 | Tanpa tembaga, ± 2 cm dari RC522 | Sinyal WiFi |
| Tombol EN & BOOT | Di belakang, dekat USB | Beri lubang di casing belakang (EN 3 kali = reset pabrik) |
| Tuangan GND | Sisi belakang, seluas papan | Mengurangi gangguan |

Jarak antar papan: header female ± 8.5 mm + plastik header modul ± 2.5 mm = **± 11 mm**. Pakai **spacer M3 11 mm** (atau 10 mm + ring) untuk LCD dan RC522. Komponen di bawah LCD (R6, C2) sengaja yang pendek.

---

## 3. Sambungan

`3V3` dan `GND` = pin 3V3 dan GND milik DevKit.

### LCD 3.5" (J3, 14 pin)

| Pin LCD | Ke | Catatan |
|---|---|---|
| VCC | 3V3 | **Jangan 5V** (J1 di LCD disolder) |
| GND | GND | |
| CS | IO5 | |
| RESET | IO4 | |
| DC | IO16 | |
| SDI (MOSI) | IO23 | |
| SCK | IO18 | |
| LED | IO2 | + R6 10 kΩ ke GND (IO2 pasti LOW saat menyala) |
| SDO (MISO) | – | |
| T_CLK | IO22 | |
| T_CS | IO15 | |
| T_DIN | IO21 | |
| T_DO | IO19 | |
| T_IRQ | – | |

Pin LED LCD aman langsung ke IO2: menurut skema resmi LCD, pin LED masuk ke transistor S8050 lewat resistor 1 kΩ di modul LCD, jadi arusnya hanya ± 2.6 mA.

### RC522 (J4, 8 pin)

| Pin | Ke |
|---|---|
| SDA (SS) | IO33 |
| SCK | IO14 |
| MOSI | IO13 |
| MISO | IO35 |
| IRQ | – |
| GND | GND |
| RST | IO32 |
| 3.3V | 3V3 |

### Buzzer lewat transistor (BZ1, Q1, R4, R5, D1)

```
IO17 ──[R4 1 kΩ]──┬── B  (Q1 S8050)
                [R5 10 kΩ]
GND ──────────────┴── E

3V3 ──┬── buzzer (+)
      │      buzzer (−) ── C (Q1)
      └──|◄── D1 1N4148 (garis/katoda ke 3V3)
```

HIGH di IO17 tetap = bunyi, firmware tidak berubah.

### LED RGB (D2) dan kapasitor

| Bagian | Sambungan |
|---|---|
| R1, R2, R3 (220 Ω) | IO25 → R, IO26 → G, IO27 → B |
| Kaki K (terpanjang) | GND |
| C1 470 µF | 3V3–GND (kiri bawah) |
| C2 100 nF | 3V3–GND dekat header LCD |
| C3 10 µF + C4 100 nF | 3V3–GND dekat header RC522 |

---

## 4. Daftar belanja (5 unit + cadangan)

| Komponen | Per unit | Beli |
|---|---|---|
| **PCB** (JLCPCB, file `absensi-pcb-jlcpcb.zip`) | 1 | 5 |
| Header female 1×15, 2.54 mm | 2 | 12 |
| Header female 1×14 | 1 | 6 |
| Header female 1×8 | 1 | 6 |
| Resistor 220 Ω 1/4 W | 3 | 20 |
| Resistor 1 kΩ 1/4 W | 1 | 10 |
| Resistor 10 kΩ 1/4 W | 2 | 20 |
| Transistor S8050 (NPN, TO-92) | 1 | 10 |
| Dioda 1N4148 | 1 | 10 |
| Elko 470 µF 10 V (Ø 8 mm, jarak kaki 3.5 mm) | 1 | 6 |
| Elko 10 µF (Ø 5 mm, jarak kaki 2.5 mm) | 1 | 6 |
| Kapasitor keramik 100 nF (jarak kaki 2.5 mm) | 2 | 12 |
| Spacer M3 11 mm + baut M3 | ± 8 + 16 | 1 paket |
| LED RGB 5 mm katoda bersama | 1 | 6 |
| Buzzer aktif 12 mm (jarak kaki 7.6 mm) | 1 | 6 |

---

## 5. Ukuran yang diambil dari internet (perlu dicek)

| Modul | Ukuran di desain | Sumber | Keyakinan |
|---|---|---|---|
| LCD | PCB 98 × 56.34, lubang Ø3.2 berjarak 92 × 49.5, 14 pin di tengah sisi pendek, 2.00 mm dari tepi, VCC paling bawah (pin di kanan) | Gambar resmi LCDWIKI MSP3520 | Tinggi (cocok dengan ukur Anda 9.97 × 5.57 cm) |
| ESP32 DevKit | 51.5 × 28, jarak dua deret pin **25.4 mm**, pin pertama 6 mm dari ujung antena | 3 footprint KiCad di GitHub, semuanya sama | Tinggi, tetapi cek jarak deret |
| RC522 | 60 × 40, deret pin 1.9 mm dari tepi kanan, SDA 9.5 mm dari tepi bawah, 4 lubang | Footprint AZ-Delivery RC522 | **Sedang**: tiap pabrik bisa beda beberapa mm |
| Buzzer | Jarak kaki 7.6 mm | Footprint standar buzzer 12 mm | Sedang (Anda mengukur Ø14 mm) |
| LED RGB | Urutan kaki R, K, G, B | Umum untuk LED katoda bersama | Sedang |
| S8050 | Urutan kaki E, B, C (sisi datar menghadap Anda) | Datasheet umum S8050 | Tinggi |

---

## 6. Cek sebelum memesan (wajib)

1. **Cetak** `hasil/cetak-depan.pdf` dan `hasil/cetak-belakang.pdf` di A4 dengan **skala 100 %** ("Actual size", jangan "Fit to page").
2. **Ukur kotak papan di kertas: harus 10.0 × 10.0 cm.** Kalau tidak, pengaturan printer salah.
3. Di kertas **depan**:
   - Letakkan **LCD** (layar menghadap atas) di kotak LCD. Ke-14 pin harus jatuh tepat di 14 lingkaran J3, dan 4 lubang LCD harus sejajar dengan 4 lubang di kertas. Pin **VCC** di posisi paling bawah.
   - Letakkan **RC522** di kotak RC522, pin di kanan. **SDA** harus di lingkaran paling bawah J4. Catat kalau lubang RC522 tidak sejajar (lubang ini hanya penyangga, pin yang paling penting).
   - Tusukkan kaki **buzzer**, **LED**, dan **S8050** ke lingkarannya.
4. Di kertas **belakang**: letakkan **ESP32 DevKit** dengan komponen menghadap atas dan USB di tepi. Ke-30 pin harus jatuh tepat di lingkaran J1 dan J2, dan tulisan pin di kertas harus sama dengan tulisan di DevKit (3V3, GND, 15, 2, 4, ...).
5. Kalau ada yang meleset, ubah ukurannya di `hardware/pcb/buat_pcb.py` (semua ukuran ada di bagian atas file), lalu jalankan `./buat.sh` lagi. Laporkan juga lewat *Issues* supaya desainnya diperbaiki untuk semua orang.
6. Casing untuk versi PCB cetak: ubah `versi = "pcb"` di `hardware/casing/casing.scad` dan buat ulang STL (lihat [casing.md](casing.md)).

---

## 7. Memesan di JLCPCB

1. Buka jlcpcb.com, klik **Order now**, upload `hardware/pcb/hasil/absensi-pcb-jlcpcb.zip`.
2. Pastikan terbaca **100 × 100 mm, 2 layers**.
3. Pilihan: PCB Qty **5**, Thickness **1.6 mm**, Surface Finish **HASL**, warna bebas. Pilihan lain biarkan bawaan.
4. **Jangan** centang PCB Assembly (komponen disolder sendiri).
5. Cek pratinjau gambar PCB, pilih pengiriman, bayar. Cek harga dan ongkos kirim terbaru sebelum membayar.

---

## 8. Merakit

1. **Rakit satu unit dulu.** Urutan solder dari yang paling pendek: resistor, dioda, kapasitor keramik, transistor, LED, elko, buzzer, lalu header female.
2. Header female ESP32 (J1, J2) dipasang **dari sisi belakang** dan disolder di sisi depan. Semua komponen lain dipasang dari depan dan disolder di belakang.
3. Perhatikan arah: elko (kaki + ke tanda +), dioda (garis ke tanda garis), S8050 (sisi datar sesuai gambar), LED (kaki terpanjang ke K), buzzer (+ ke tanda +).
4. Sebelum memasang modul: ukur dengan multimeter bahwa **3V3 dan GND tidak tersambung singkat**.
5. Pasang ESP32, upload firmware, cek layar, touch, kartu, buzzer, LED. Setelah lolos, rakit 4 unit sisanya.

---

## 9. Nanti: versi terpadu

Untuk produksi puluhan unit: modul ESP32-WROOM disolder langsung, plus USB-C, chip USB, dan regulator sendiri. Lebih kecil dan murah per unit, tetapi desainnya lebih sulit dan komponennya SMD. Tidak perlu untuk 5 unit.

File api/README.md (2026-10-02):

# Absensi RFID Terintegrasi — Server & Panel Admin

Server Laravel untuk alat absensi tap RFID. Isinya dua bagian:

1. **API standar alat** di `/api/absensi` — *implementasi acuan* dari
   [`doc/spesifikasi-api.md`](../doc/spesifikasi-api.md). Kalau Anda membuat aplikasi sendiri yang
   ingin dihubungkan ke alat, spesifikasi itulah acuannya; kode di sini contoh lengkap yang berjalan.
2. **Panel admin sederhana** di `/admin` — kelola anggota & kartu, lihat tap hari ini, rekap, alat
   (termasuk **pemantauan kesehatan alat** dan **mode absen** Otomatis / Pilih Datang/Pulang),
   **update firmware jarak jauh**, dan pengaturan.

- Laravel 13, PHP 8.3+, PostgreSQL, Blade + satu stylesheet (`public/css/admin.css`), tanpa build Node
- Zona waktu `Asia/Jakarta` (ubah dengan `APP_TIMEZONE`), bahasa Indonesia
- Tidak perlu scheduler (cron) maupun queue worker

Panduan lengkap proyek (alat, perakitan, firmware) ada di [`README.md` utama](../README.md). Contoh
server minimal (PHP/Node) dan skrip pemeriksa API ada di [`contoh-integrasi/`](../contoh-integrasi/README.md).

## Kebutuhan

- PHP **8.3** atau lebih baru dengan ekstensi:
  - wajib: `pdo_pgsql`, `mbstring`, `fileinfo` (plus ekstensi bawaan yang dibutuhkan Laravel, mis.
    `openssl`, `ctype`, `tokenizer`, `xml`)
  - opsional: `gd` untuk unggah foto anggota (tanpa GD aplikasi tetap jalan, hanya unggah foto yang
    dinonaktifkan) dan `exif` agar foto dari ponsel diputar sesuai orientasinya
- Composer 2
- **PostgreSQL**. Aplikasi memakai fitur khusus PostgreSQL (pencarian `ilike`, kolom
  `jsonb`), jadi **SQLite dan MySQL/MariaDB tidak didukung**.
- Node.js/npm **tidak** dibutuhkan.

## Setup dari clone baru

```bash
cd api
composer install
cp .env.example .env
php artisan key:generate
```

Buat dua database (yang kedua hanya untuk tes otomatis), misalnya:

```bash
createdb absensi_alat
createdb absensi_alat_test        # dipakai php artisan test (lihat phpunit.xml)
# atau: psql -U postgres -c "CREATE DATABASE absensi_alat;"  (dan absensi_alat_test)
```

Isi koneksi database di `.env` (`DB_HOST`, `DB_PORT`, `DB_DATABASE=absensi_alat`, `DB_USERNAME`,
`DB_PASSWORD`), lalu:

```bash
php artisan migrate
php artisan absensi:admin-password admin   # atur password admin (ditanya 2x, min. 8 karakter)
php artisan storage:link                   # agar foto anggota bisa diakses di /storage/...
```

`php artisan migrate` membuat semua tabel sekaligus:

- akun admin awal: username `admin`, email `admin@example.com`, **tanpa password** (tidak bisa login
  sampai `absensi:admin-password admin` dijalankan);
- **API key acak 24 karakter** untuk alat (lihat panel → **Pengaturan**);
- pengaturan bawaan: judul layar alat `Absensi RFID`, screensaver (3 detik per pengumuman, muncul
  setelah diam 30 detik).

Data contoh (opsional):

```bash
php artisan db:seed                              # 2 anggota contoh: Budi Santoso (0218893066), Siti Aminah (0287454020)
php artisan db:seed --class=AnnouncementSeeder   # 10 pengumuman contoh untuk screensaver
```

Menjalankan server:

```bash
./serve.sh            # = php artisan serve --host=127.0.0.1 --port=8133
# atau: php artisan serve
```

Buka `http://localhost:8133/admin` lalu masuk sebagai `admin`. `./serve.sh` hanya mendengarkan
`127.0.0.1`, jadi server tidak bisa diakses dari perangkat lain. Untuk mencoba alat lewat jaringan lokal
(LAN), jalankan `php artisan serve --host=0.0.0.0 --port=8133` dan pakai Base URL
`http://<ip-komputer>:8133/api/absensi` (izinkan port 8133 di firewall). Untuk akses dari internet, lihat
[Memasang di internet](#memasang-di-internet).

`.env.example` memakai `APP_ENV=local` dan `APP_DEBUG=true` untuk pengembangan. Tidak perlu
`php artisan config:cache`; `php artisan serve` membaca `.env` setiap request. Catatan: `php artisan serve`
meneruskan `APP_ENV` dari saat ia dijalankan, jadi perubahan `APP_ENV` baru berlaku setelah server
dijalankan ulang (`APP_DEBUG` langsung berlaku).

## Menghubungkan alat

Di menu **Pengaturan** alat, isi:

| Isian di alat | Nilai |
|---|---|
| Base URL | `<APP_URL>/api/absensi`, mis. `https://absensi.example.com/api/absensi` (alamat lengkapnya juga tampil di panel → **Pengaturan** → Koneksi alat) |
| API key | panel → **Pengaturan** → Koneksi alat |

Tekan "Tes koneksi". Alat otomatis muncul di halaman **Alat** (dikenali dari `X-Device-ID`),
tidak perlu didaftarkan dulu.

Cara mendaftarkan kartu baru: tempel kartu di alat (layar: KARTU TIDAK TERDAFTAR) → buka
**Kartu belum terdaftar** di panel → **Daftarkan** (nomor kartu terisi otomatis) → isi nama → Simpan.

## Memasang di internet

Alat harus bisa menjangkau server. Pilihan umum:

- **VPS + nginx**: arahkan *document root* ke `api/public` dengan PHP-FPM, atau jadikan nginx
  *reverse proxy* ke `./serve.sh` (`http://127.0.0.1:8133`). Pasang sertifikat HTTPS (mis. Let's Encrypt).
- **Cloudflare Tunnel** (tanpa membuka port): jalankan `cloudflared` di komputer yang sama dengan server
  dan arahkan ingress ke `http://localhost:8133`.

Hal yang perlu diperhatikan:

- Di `.env` server publik: `APP_ENV=production`, `APP_DEBUG=false` (galat hanya menampilkan pesan
  singkat, tanpa detail kode), dan `APP_URL=https://<domain-anda>`.
- **Proxy tepercaya**: `bootstrap/app.php` hanya memercayai proxy lokal
  (`trustProxies(at: ['127.0.0.1', '::1'])`), cocok untuk nginx/cloudflared yang berjalan di mesin yang
  sama. Header `X-Forwarded-*` dari alamat lain diabaikan. IP klien (untuk batas login & batas API)
  diambil dari `X-Forwarded-For`. Kalau proxy berada di mesin lain, tambahkan alamatnya di situ.
- **URL https**: middleware `SecureUrlsBehindTunnel` memaksa semua URL (termasuk `photo_url` foto anggota,
  redirect, dan form) memakai `https` dan memberi cookie sesi atribut `Secure` bila request datang lewat
  HTTPS (`X-Forwarded-Proto: https` dari proxy tepercaya) atau memakai host yang sama dengan `APP_URL`
  `https://…`. Akses langsung `http://127.0.0.1:8133` tetap memakai `http`.
- **Buat ulang API key** di panel → **Pengaturan** sebelum dipakai sungguhan, lalu isi ulang di alat.
- Folder `storage/` dan `bootstrap/cache/` harus bisa ditulis oleh proses PHP.
- Opsional: `composer install --no-dev --optimize-autoloader` di server produksi. Paket pengembangan
  Laravel Boost hanya aktif bila `APP_ENV=local` atau `APP_DEBUG=true`; untuk mematikannya sama sekali
  tambahkan `BOOST_BROWSER_LOGS_WATCHER=false` di `.env`.

## API standar `/api/absensi`

Lengkapnya di [`doc/spesifikasi-api.md`](../doc/spesifikasi-api.md). Ringkasnya:

| Endpoint | Fungsi |
|---|---|
| `GET /ping` | Tes koneksi. `{"ok":true,"message":"Terhubung ke <judul>","server_time":"…+07:00","config":{…}}` |
| `POST /tap` | Kartu ditempelkan → `check_in` / `check_out` / `duplicate` / `unknown` / `rejected` |
| `POST /check-in`, `POST /check-out` | Mode absen **Pilih Datang/Pulang** (firmware 1.6.0+): body & respons sama dengan `/tap` (+ `"mode"`), jenis tap ditentukan endpoint. Lihat [Mode absen](#mode-absen) |
| `POST /heartbeat` | Tiap 60 detik. Mencatat status alat, membalas `server_time` + `config` |
| `GET /announcements` | Pengumuman screensaver: `{"ok":true,"interval":3,"idle":30,"items":[{"id":"12","title":"…","description":"…","icon":"rapat"}]}` |
| `GET /firmware/{id}` | File `.bin` untuk update jarak jauh (URL-nya dari `config.firmware_update`). Hanya untuk alat yang dijadwalkan ke firmware itu, selain itu 404 |

- Header wajib: `X-API-Key` (salah/kosong → **401** `{"ok":false,"message":"API key salah"}`) dan
  `X-Device-ID` (kosong → **400**). `X-Spec-Version` diterima tanpa diperiksa.
- Body POST yang bukan objek JSON, `rfid` kosong/tidak valid, atau data lain yang formatnya salah
  → **400** `{"ok":false,"message":"…"}`.
- Batas request → **429** `{"ok":false,"message":"Terlalu banyak permintaan"}`:
  - 240 request/menit per alat (`X-Device-ID`) + IP. Alat normal hanya beberapa request per menit
    (heartbeat 1/menit, antrean paling cepat 1 tap/detik), jadi batas ini tidak tercapai.
  - API key salah 20 kali/menit dari satu IP → semua request dari IP itu dibalas 429 sampai menit itu
    lewat (memperlambat tebakan API key).
- Semua hasil bisnis → **HTTP 200**.
- `config` berisi `title` (judul layar), `pin` (PIN menu Pengaturan alat, hanya dikirim kalau diisi
  di panel), `dim_after` & `dim_level` (layar redup setelah diam sekian detik ke sekian persen, bawaan
  60 detik & 20 %), `announcements_rev` (penanda versi pengumuman), dan `restart_at` (jam restart harian
  alat ini, `"HH:MM"` menurut jam di layar alat; selalu dikirim, `""` = alat tidak restart otomatis; bawaan
  `"03:00"`, diatur per alat di halaman **Alat**), serta `tap_mode` (`"auto"` / `"select"`, hanya dikirim kalau
  mode absen alat itu diatur di halaman **Alat**).
- `GET /announcements`: hanya pengumuman aktif, urut nomor urutan, maks. 10; `id` berupa teks,
  `description` tidak dikirim kalau kosong. `interval`/`idle` dari menu **Pengumuman** (bawaan 3 dan 30 detik).
- `config.announcements_rev` = `"<jumlah pengumuman>-<unix perubahan terakhir>-<interval>-<idle>"`,
  mis. `"2-1790729112-3-30"`. Nilainya berubah setiap pengumuman ditambah/diubah/dihapus atau pengaturan
  screensaver diganti, sehingga alat mengambil ulang `/announcements` pada heartbeat berikutnya (±1 menit).
- `config.firmware_update` (`version`, `url`, `size`, `md5`) hanya dikirim kalau alat dijadwalkan update,
  versinya belum terpasang, dan belum pernah gagal dipasang di alat itu (`raw.ota_failed`). Lihat
  [Update firmware jarak jauh](#update-firmware-jarak-jauh).

```bash
curl -X POST http://localhost:8133/api/absensi/tap \
  -H "X-API-Key: <api-key>" -H "X-Device-ID: ABS-1A2B3C" -H "X-Spec-Version: 1" \
  -H "Content-Type: application/json" \
  -d '{"device_id":"ABS-1A2B3C","tap_id":"1A2B3C-5F3A9C21","rfid":"0218893066","tapped_at":"2026-09-30T07:45:12+07:00","queued":false,"raw":null}'
```

### Log request API

Semua request ke `/api/...` (termasuk yang ditolak 400/401/429) dicatat oleh middleware
`CatatLogApi` ke `storage/logs/api-YYYY-MM-DD.log`, terpisah dari `laravel.log`: alat (X-Device-ID),
seluruh parameter, balasan server, dan lama proses. API key hanya dicatat ada-tidaknya, dan PIN alat
disembunyikan. Kunci di log berbahasa Inggris: `method`, `url`, `device` (`id`, `registered`), `api_key`,
`spec_version`, `ip`, `user_agent`, `duration_ms`, `request`, `response` (`status`, `body`), `error`.
Disimpan 30 hari (ubah dengan `API_LOG_DAYS` di `.env`). Contoh melihat tap satu alat:

```bash
grep '"id":"ABS-1A2B3C"' storage/logs/api-$(date +%F).log | grep 'absensi/tap'
```

### Aturan tap di implementasi acuan ini

Per anggota, per hari kalender `Asia/Jakarta` (lihat `app/Services/AttendanceService.php`):

| Kondisi | `status` | `ok` | `message` | Lainnya |
|---|---|---|---|---|
| Nomor kartu tidak terdaftar | `unknown` | false | Kartu belum terdaftar | dicatat → muncul di "Kartu belum terdaftar" |
| Anggota nonaktif | `rejected` | false | Kartu nonaktif | `name` |
| < 60 detik dari tap diterima sebelumnya | `duplicate` | true | Sudah tercatat | `time` = jam tap sebelumnya |
| Tap diterima pertama hari itu | `check_in` | true | Selamat datang | `time` |
| Tap diterima berikutnya | `check_out` | true | Sampai jumpa | `time`, `info: ["Masuk 07:45"]` |

- Jeda duplikat 60 detik bisa diubah dengan `ABSENSI_DUPLICATE_WINDOW_SECONDS` di `.env`.
- `photo_url` (URL absolut) disertakan kalau anggota punya foto.
- **Tap antrean** (`queued: true`) memakai `tapped_at` dari alat. Waktu diterima yang dipakai kalau
  `tapped_at` `null`/tidak valid, lebih dari **5 menit di masa depan**, atau lebih dari **30 hari yang
  lalu** (jam alat kemungkinan salah). Tap biasa selalu memakai jam server.
- Tap antrean yang jamnya **lebih awal dari check-in yang sudah ada** di hari yang sama juga dicatat
  sebagai `check_in`; check-in yang lama tidak diubah (bisa saja dari alat lain dan bukan jam pulang).
  Jadi satu hari bisa punya dua `check_in`: rekap, dasbor, dan `info: ["Masuk …"]` selalu memakai yang
  paling awal, jam pulang tetap `check_out` terakhir.
- **`tap_id`** disimpan per alat. Tap dengan `tap_id` yang sudah pernah dicatat tidak dicatat lagi:
  dibalas `duplicate` (jam tap aslinya), atau hasil yang sama untuk `unknown`/`rejected`.
- JSON mentah dari alat disimpan di `attendances.payload`; body terakhir per alat di
  `devices.last_payload`.
- Nomor kartu disimpan sebagai 10 digit (mis. `0218893066`, yaitu UID `0A 0B 0C 0D` dibaca
  little-endian). Kartu lama yang dulu didaftarkan sebagai hex 4 byte (mis. `0A0B0C0D`) tetap dikenali
  karena nilainya sama.

### Mode absen

Butuh firmware alat **1.6.0** ke atas (spesifikasi bagian 4.1). Di halaman **Alat**, pilihan **Mode absen** per alat:
*Ikuti pengaturan di alat* (`devices.tap_mode` null, `config.tap_mode` tidak dikirim), *Otomatis (1 endpoint /tap)*
(`auto`), atau *Pilih Datang/Pulang di alat* (`select`: petugas memilih DATANG/PULANG di layar alat, tap dikirim ke
`/check-in` atau `/check-out`). Mode yang sedang dipakai alat dan pilihan saat ini (Datang / Pulang / belum dipilih)
diambil dari heartbeat (`raw.tap_mode`, `raw.tap_select`) dan ditampilkan di kartu alat.

| Endpoint | Kondisi | `status` | `message` | Lainnya |
|---|---|---|---|---|
| `/check-in` | Sudah ada `check_in` di tanggal yang sama | `duplicate` | Sudah absen datang | `time` = jam `check_in` pertama |
| `/check-in` | Selain itu | `check_in` | Selamat datang | `time` |
| `/check-out` | Ada `check_out` < 60 detik (jeda tap ganda) di tanggal yang sama | `duplicate` | Sudah tercatat | `time` = jam `check_out` itu |
| `/check-out` | Selain itu | `check_out` | Hati-hati di jalan | `info: ["Masuk tadi 07:45"]` atau `["Belum absen datang hari ini"]` |

Kartu tidak terdaftar / nonaktif, `tap_id` (berlaku lintas `/tap`, `/check-in`, `/check-out`), tap antrean, foto, dan
penyimpanan `payload` sama dengan `/tap`; barisnya masuk ke tabel `attendances` yang sama, jadi rekap tetap satu.
Kolom `devices.tap_mode`, `reported_tap_mode`, `tap_select` dibuat migrasi `2026_10_02_000001`; sebelum migrasi itu
dijalankan API & halaman Alat tetap jalan, hanya tanpa pengaturan mode absen.

### Kesehatan alat

Setiap `/heartbeat` menyimpan data kesehatan dari `raw` ke tabel `devices` (`uptime_s`, `reset_reason`,
`rfid_ok`, `queue`, `free_heap`, `min_free_heap`, `error_code`, `ota_failed`, `heartbeat_at`). Kejadian
penting dicatat di tabel `device_events` (200 terbaru per alat):

| Kejadian | Kapan |
|---|---|
| `boot` | `uptime_s` lebih kecil dari heartbeat sebelumnya (alat restart), beserta `reset_reason` |
| `crash` | `raw.crash` dikirim (crash yang sama dalam 10 menit tidak dicatat ulang) |
| `firmware` | Versi firmware berganti, mis. `Firmware 1.4.0 -> 1.5.0` |
| `ota_failed` | Alat melapor update firmware gagal (versi baru di `raw.ota_failed`) |

Halaman **Alat** menampilkan peringatan (`Device::healthIssues()`), dan **Dasbor** menampilkan daftar alat
yang perlu diperiksa. Batasnya konstanta di `app/Models/Device.php`: offline > 10 menit, pembaca RFID
tidak terdeteksi, kode error di layar, sinyal < −80 dBm, antrean > 20 tap, ≥ 3 restart tidak normal
(`watchdog`/`panic`/`brownout`) dalam 24 jam, update firmware gagal, RAM terendah < 20000 byte.

### Update firmware jarak jauh

Butuh firmware alat **1.5.0** ke atas.

1. Kompilasi firmware dengan `VERSI_FIRMWARE` baru di `config.h` (`cd firmware && ./upload.sh -c absensi`,
   lokasi file `.bin` dijelaskan di README firmware).
2. Panel → **Firmware** → unggah: versi (`1.5.0`), file `.bin` (maks. 1966080 byte = slot OTA partisi
   `min_spiffs`), catatan. Server menolak file yang byte pertamanya bukan `0xE9` (image aplikasi ESP32)
   atau yang tidak memuat teks versinya. File disimpan di `storage/app/private/firmware/<versi>.bin`.
3. Panel → **Alat** → "Update firmware ke" per alat, atau **Terapkan ke semua alat** di halaman Firmware.
   Pada heartbeat berikutnya alat menerima `config.firmware_update`, mengunduh `GET /api/absensi/firmware/{id}`
   (dengan `X-API-Key`; dibalas `application/octet-stream`, `Content-Length`, dan header `x-MD5`), lalu
   restart. Status per alat: *Menunggu alat mengunduh*, *Sudah terpasang*, atau *Gagal, kembali ke …*.

Alat tidak memeriksa sertifikat HTTPS, jadi pihak yang bisa menyadap jaringan alat bisa saja memasang
firmware palsu. Jadwalkan update hanya untuk alat yang memang ingin diupdate, lalu kosongkan lagi bila perlu.
Unggahan ±2 MB juga butuh `upload_max_filesize` dan `post_max_size` PHP minimal 2M (bawaan PHP sudah cukup).

### Foto anggota

Diunggah di panel (JPG/PNG, maks. 8 MB), lalu diproses dengan GD menjadi **JPEG baseline**, muat di
dalam **160×160** piksel, **≤ 30 KB** (kualitas diturunkan sampai muat), dan disimpan di
`storage/app/public/anggota/`. Lihat `app/Services/MemberPhoto.php`.

## Panel admin `/admin`

Masuk dengan **username atau email** + password. Salah 5 kali untuk akun yang sama dari satu IP →
dikunci 60 detik; selain itu maksimal 10 percobaan login per menit per IP.

| Menu | Isi |
|---|---|
| **Dasbor** | Hari ini: masuk / pulang / belum hadir, 20 tap terakhir (diperbarui tiap 10 detik), status alat (aktif bila terlihat < 3 menit), daftar alat yang perlu diperiksa |
| **Anggota** | Cari, tambah, ubah (nama, NIS/NIP, nomor kartu, foto, aktif), hapus |
| **Kehadiran** | Semua tap kartu pada tanggal yang dipilih (bisa dicari); hapus satu tap atau semua tap tanggal itu (mis. untuk mengulang tes) |
| **Kartu belum terdaftar** | Nomor kartu yang pernah ditempel tapi belum punya pemilik → tombol "Daftarkan" (nomor kartu terisi otomatis) |
| **Rekap** | Rentang tanggal, per anggota per hari: jam masuk pertama & jam pulang terakhir; ekspor CSV |
| **Alat** | Satu kartu per alat: status Online/Offline, **peringatan kesehatan**, terakhir terlihat, firmware, IP, WiFi & RSSI, lama menyala, alasan restart terakhir, pembaca RFID, antrean offline, RAM, kode error di layar, tap hari ini, dan **riwayat 10 kejadian terakhir** (restart, crash, ganti firmware, update gagal). Bisa diubah: nama, **PIN menu Pengaturan per alat** (opsional, 4–8 digit), **jam restart harian per alat** (bawaan 03:00, sebaiknya jam sepi; kosongkan = tidak restart otomatis), dan **target update firmware**. Galat isian tampil di kartu alat yang bersangkutan |
| **Firmware** | Unggah file `.bin` untuk update jarak jauh (versi, ukuran, MD5, jumlah alat yang dijadwalkan), **Terapkan ke semua alat**, hapus |
| **Pengumuman** | Pengumuman untuk screensaver alat: judul (maks. 40), deskripsi (maks. 160), ikon, aktif, urutan; **aksi massal** (tampilkan / sembunyikan / hapus yang dicentang); plus pengaturan screensaver (lama tiap pengumuman 2–60 detik, muncul setelah diam 5–600 detik). Sampai ke alat dalam ±1 menit |
| **Pengaturan** | Base URL & API key (bisa dibuat ulang), judul layar alat dan **layar redup** (redup setelah 0 atau 10–3600 detik, kecerahan 0–100 %; untuk semua alat), ganti password |

## Perintah Artisan

Daftar lengkap: `php artisan list absensi`.

```bash
php artisan absensi:admin-password admin                       # atur/ganti password admin (tersembunyi, 2x)
php artisan absensi:admin-create operator operator@example.com # akun admin baru (tanpa password)
php artisan absensi:member-create "Andi Wijaya" 1234567890 --identifier=1003
php artisan absensi:member-list
php artisan absensi:member-deactivate 1234567890 [--activate]
php artisan absensi:unknown-cards [--limit=20] [--all]
php artisan absensi:report [2026-09-30]                        # rekap satu hari di terminal
php artisan absensi:device-create "Nama alat"                  # USANG: kunci alat untuk API lama /api/v1
```

## Struktur kode

```
routes/api.php                          /api/absensi (standar) dan /api/v1 (usang)
routes/web.php                          panel /admin
bootstrap/app.php                       proxy tepercaya, middleware, format galat API
app/Http/Middleware/AuthenticateAbsensiDevice.php   cek X-API-Key, X-Device-ID, catat alat
app/Http/Middleware/CatatLogApi.php     log semua request API ke storage/logs/api-*.log
app/Http/Middleware/SecureUrlsBehindTunnel.php      URL https & cookie Secure di belakang proxy
app/Http/Controllers/Api/AbsensiController.php      ping / tap / heartbeat / announcements / firmware
app/Services/AttendanceService.php      aturan masuk / pulang / duplikat
app/Services/MemberPhoto.php            olah foto untuk layar alat
app/Http/Controllers/Admin/*            halaman panel
app/Models/Setting.php                  api_key, title, screensaver_interval, screensaver_idle, dim_after, dim_level
app/Models/Announcement.php             pengumuman, isi GET /announcements & announcements_rev
app/Models/Device.php                   alat, data kesehatan dari heartbeat, peringatan (healthIssues)
app/Models/DeviceEvent.php              riwayat kejadian alat (boot, crash, firmware, ota_failed)
app/Models/FirmwareRelease.php          file firmware untuk update jarak jauh
config/absensi.php                      jeda duplikat (ABSENSI_DUPLICATE_WINDOW_SECONDS)
resources/views/admin/*                 tampilan Blade
public/css/admin.css, public/js/admin.js
```

## API lama `/api/v1` (USANG)

Masih aktif hanya untuk firmware lama yang sudah terpasang; **jangan dipakai untuk alat baru**, dan
akan dihapus setelah semua alat memakai `/api/absensi`. Header `X-Device-Key` (kunci per alat, dibuat
dengan `php artisan absensi:device-create "Nama"`; hanya hash yang disimpan). Endpoint:
`GET /api/v1/ping`, `POST /api/v1/tap` (`{"uid":"A1B2C3D4"}`), `GET /api/v1/attendances/today`.
Respons lama tidak berubah (`unknown_card` → 404, `inactive` → 403, dst.). Tap dari API lama
tercatat di tabel yang sama, jadi tetap tampil di panel.

## Test

```bash
php artisan test        # memakai database absensi_alat_test & APP_ENV=testing (lihat phpunit.xml)
./vendor/bin/pint       # format kode
```

Database tes memakai pengguna/password yang sama dengan `.env` (`DB_USERNAME`, `DB_PASSWORD`); hanya
nama database yang diganti `phpunit.xml`.

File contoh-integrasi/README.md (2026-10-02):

# Contoh Integrasi Absensi RFID Terintegrasi

Folder ini untuk **pengembang aplikasi** (sistem sekolah, HRIS, ERP, dan sebagainya) yang ingin memakai alat absensi RFID. Isinya server contoh yang **sudah lengkap** (API alat + 6 fitur wajib), skrip pemeriksa, dan koleksi Postman. Jalankan dulu, lihat cara kerjanya, lalu salin polanya ke aplikasi Anda.

Tanpa framework, tanpa `npm install`/`composer`, tanpa langkah build.

```
contoh-integrasi/
├── php/index.php        ← PHP 8 + SQLite, satu file
├── node/server.js       ← Node.js 18+, hanya modul bawaan, data di file JSON
├── tes/cek-server.sh    ← pemeriksa API alat (bash + curl + python3)
└── postman/             ← koleksi + environment Postman, plus contoh-firmware.bin (firmware palsu untuk uji)
```

Baca juga:

| Dokumen | Isi |
|---|---|
| [doc/integrasi-aplikasi.md](../doc/integrasi-aplikasi.md) | **Panduan integrasi**: 6 fitur wajib, data yang perlu disimpan, urutan kerja, checklist |
| [doc/spesifikasi-api.md](../doc/spesifikasi-api.md) | **Kontrak teknis** alat ↔ aplikasi: endpoint, header, format JSON, kode HTTP |

## Daftar isi

1. [Langkah cepat](#1-langkah-cepat)
2. [Menjalankan server contoh](#2-menjalankan-server-contoh)
3. [Menghubungkan alat](#3-menghubungkan-alat)
4. [Enam fitur wajib di server contoh](#4-enam-fitur-wajib-di-server-contoh)
5. [Referensi API admin](#5-referensi-api-admin)
6. [Menguji API alat dengan `cek-server.sh`](#6-menguji-api-alat-dengan-cek-serversh)
7. [Menguji dengan Postman & Newman](#7-menguji-dengan-postman--newman)
8. [Checklist integrasi](#8-checklist-integrasi)
9. [Catatan hosting](#9-catatan-hosting)
10. [Daftar endpoint & kasus API alat](#10-daftar-endpoint--kasus-api-alat)

---

## 1. Langkah cepat

```bash
# 1) Jalankan salah satu server contoh (dari folder utama repo)
cd contoh-integrasi/php && php -S 0.0.0.0:8080 index.php
#    atau:  cd contoh-integrasi/node && node server.js

# 2) Di terminal lain: tes koneksi seperti yang dilakukan alat
curl -H "X-API-Key: ganti-dengan-kunci-anda" -H "X-Device-ID: ABS-TES001" http://localhost:8080/ping

# 3) Lihat pengaturan lewat API admin
curl -H "X-Admin-Key: ganti-kunci-admin" http://localhost:8080/admin/settings

# 4) Uji semuanya (API alat + 6 fitur wajib), dari folder utama repo
npx newman run contoh-integrasi/postman/AbsensiRFID.postman_collection.json \
  -e contoh-integrasi/postman/AbsensiRFID.postman_environment.json \
  --env-var base_url=http://localhost:8080 --working-dir contoh-integrasi/postman
```

Lalu sambungkan alat sungguhan ([bagian 3](#3-menghubungkan-alat)) dan tempelkan kartu.

---

## 2. Menjalankan server contoh

Kedua server berperilaku sama: endpoint, status HTTP, dan bentuk JSON-nya identik (hanya teks pesan galat yang sedikit berbeda). Pilih bahasa yang paling dekat dengan aplikasi Anda.

### PHP 8 + SQLite

```bash
cd contoh-integrasi/php
php -S 0.0.0.0:8080 index.php
```

Butuh ekstensi `pdo_sqlite` (bawaan di hampir semua instalasi PHP). Database `data.sqlite` dan tabelnya dibuat otomatis; database versi lama dilengkapi kolom barunya saat server jalan.

### Node.js 18+

```bash
cd contoh-integrasi/node
node server.js                # port lain: PORT=9000 node server.js
```

Data disimpan di `data.json` (dibuat otomatis, dibaca ulang setiap request, jadi boleh diedit tanpa restart).

### Yang dibuat otomatis

| Data | Isi awal |
|---|---|
| Anggota | `0218893066` Budi Santoso (aktif), `0012345678` Siti Aminah (aktif), `0055555555` Rina Kurnia (**nonaktif**, untuk contoh `rejected`) |
| Pengumuman | "Rapat Guru" (ikon `rapat`) dan "Libur Nasional" (ikon `libur`), keduanya aktif |
| Pengaturan | `api_key` `ganti-dengan-kunci-anda`, `title` "Aplikasi Contoh", `dim_after` 60, `dim_level` 20, `screensaver_interval` 3, `screensaver_idle` 30, `duplicate_window` 60, `default_restart_at` "03:00" |
| Alat | terdaftar otomatis saat sebuah `X-Device-ID` pertama kali menghubungi server |
| Firmware | file hasil unggah disimpan di folder `firmware/` di samping server |

`data.sqlite`, `data.json`, dan folder `firmware/` diabaikan git. Untuk mengulang dari awal: hentikan server, hapus file/folder itu, jalankan lagi.

### Yang perlu Anda ganti

| Konstanta (di bagian atas file) | Bawaan | Keterangan |
|---|---|---|
| `ADMIN_KEY` | `ganti-kunci-admin` | Kunci API admin (header `X-Admin-Key`). **Ganti** sebelum dipasang di jaringan mana pun |
| Zona waktu | WIB | PHP: `date_default_timezone_set('Asia/Jakarta')`; Node: `ZONA_JAM = 7` (WITA 8, WIT 9) |
| `PORT` (Node) | 8080 | atau variabel lingkungan `PORT` |

Pengaturan lain (API key alat, judul layar, dan seterusnya) diubah lewat `PUT /admin/settings`, bukan di kode.

### Aturan bisnis `/tap` di contoh

Ada di fungsi `tentukanStatus()`. Silakan ubah sesuai aturan instansi Anda.

1. Kartu tidak ada di anggota → `unknown` (tap tetap dicatat, muncul di **Kartu belum terdaftar**)
2. Anggota nonaktif → `rejected` dengan pesan "Kartu nonaktif"
3. Tap ulang dalam `duplicate_window` detik (bawaan 60) sejak tap terakhir yang diterima → `duplicate`
4. Tap pertama hari itu → `check_in`
5. Tap berikutnya di hari yang sama → `check_out` (dengan `info` "Masuk tadi HH:MM")

Tap antrean (`queued: true`) memakai `tapped_at` dari alat. `tap_id` yang sama dikirim ulang → server membalas respons yang dulu tanpa mencatat baris baru.

---

## 3. Menghubungkan alat

1. Pastikan laptop dan alat berada di **jaringan WiFi yang sama** (alat hanya bisa memakai WiFi **2.4 GHz**).
2. Cari IP laptop:
   - macOS: `ipconfig getifaddr en0`
   - Linux: `hostname -I`
   - Windows: `ipconfig` (lihat "IPv4 Address")
3. Di alat, buka **Pengaturan** (PIN bawaan `2026`) → **Server**, lalu isi:
   - **Base URL**: `http://<ip-laptop>:8080`, contoh `http://192.168.1.10:8080` (tanpa `/` dan tanpa `/ping` di akhir)
   - **API key**: nilai `api_key` di pengaturan, awalnya `ganti-dengan-kunci-anda`
4. Tekan **Tes koneksi**. Layar menampilkan "Terhubung ke Aplikasi Contoh", dan judul layar utama mengikuti `config.title`.
5. Tempelkan kartu. Kartu yang belum terdaftar tampil **KARTU TIDAK TERDAFTAR** beserta nomornya, lalu muncul di `GET /admin/unknown-cards`.

Kalau tes koneksi gagal, periksa firewall laptop (izinkan port 8080). Server contoh juga menerima awalan path, jadi Base URL `http://192.168.1.10:8080/api/absensi` pun bisa dipakai.

---

## 4. Enam fitur wajib di server contoh

Server contoh tidak punya halaman web. Keenam fitur wajib (lihat [panduan integrasi bagian 2](../doc/integrasi-aplikasi.md#2-fitur-wajib)) disediakan sebagai **API JSON admin** supaya mudah ditiru di framework apa pun. Aplikasi Anda bebas memakai halaman web, API, atau keduanya.

| Fitur wajib | API admin contoh | Yang terlihat di alat |
|---|---|---|
| **Kartu belum terdaftar** | `GET /admin/unknown-cards` → daftarkan dengan `POST /admin/members` | Kartu tak dikenal: KARTU TIDAK TERDAFTAR; setelah didaftarkan: MASUK |
| **Rekap** | `GET /admin/report` (JSON atau `format=csv`), `GET /admin/attendances` | – |
| **Alat** | `GET /admin/devices`, `GET /admin/devices/{id}`, `PUT /admin/devices/{id}` | `config.pin`, `config.restart_at` |
| **Firmware** | `GET/POST /admin/firmware`, `DELETE /admin/firmware/{versi}`, `POST /admin/firmware/{versi}/apply-all`, target per alat lewat `PUT /admin/devices/{id}` | `config.firmware_update` + unduhan `GET /firmware/{versi}` |
| **Pengumuman** | `GET/POST /admin/announcements`, `PUT/DELETE /admin/announcements/{id}` | `config.announcements_rev`, isi `GET /announcements` |
| **Pengaturan** | `GET/PUT /admin/settings` | `config.title`, `config.dim_after`, `config.dim_level`, `interval`/`idle` di `/announcements`, API key |
| *(pendukung)* Anggota | `GET/POST /admin/members`, `PUT/DELETE /admin/members/{rfid}` | nama & foto di layar saat tap |

Koleksi Postman folder **"2. Admin contoh"** menjalankan semua fitur ini sebagai satu skenario berurutan (ubah pengaturan → kelola anggota → daftarkan kartu baru → rekap → kelola alat → update firmware → pengumuman → kembalikan pengaturan), lengkap dengan pemeriksaan bahwa perubahan benar-benar sampai ke alat.

---

## 5. Referensi API admin

### 5.0 Aturan umum

- **Alamat:** `http://<server>:8080/admin/...`. Awalan apa pun sebelum `/admin/` juga diterima, misalnya `/api/absensi/admin/settings`.
- **Header wajib:** `X-Admin-Key: ganti-kunci-admin` (konstanta `ADMIN_KEY`). Body request berupa JSON (`Content-Type: application/json`), kecuali unggah firmware.
- **Body sebagian:** `PUT` hanya mengubah field yang dikirim.
- **ID:** `id` pengumuman dan kehadiran di API admin berupa **angka**; di API alat (`GET /announcements`) `id` berupa **teks**.
- **Waktu:** ISO 8601 dengan offset, contoh `2026-10-02T07:15:00+07:00`.

| HTTP | Arti | Bentuk |
|---|---|---|
| 200 | Berhasil | `{"ok": true, ...}` |
| 201 | Data baru dibuat (`POST`) | `{"ok": true, ...}` |
| 400 | Body bukan objek JSON `{...}` | `{"ok": false, "message": "..."}` |
| 401 | `X-Admin-Key` salah atau kosong | `{"ok": false, "message": "Admin key salah"}` |
| 404 | Data atau endpoint tidak ada | `{"ok": false, "message": "..."}` |
| 413 | Body JSON lebih dari 1 MB | `{"ok": false, "message": "..."}` |
| 422 | Validasi gagal. `message` = galat field pertama, `errors` = semua galat per field | `{"ok": false, "message": "...", "errors": {"field": "..."}}` |

Contoh galat umum (respons asli server contoh PHP):

```bash
curl http://localhost:8080/admin/settings                      # tanpa X-Admin-Key
```
```json
{
  "ok": false,
  "message": "Admin key salah"
}
```
```bash
curl -X PUT http://localhost:8080/admin/settings -H "X-Admin-Key: ganti-kunci-admin" \
  -H "Content-Type: application/json" -d '[1, 2, 3]'           # body bukan objek
```
```json
{
  "ok": false,
  "message": "Body harus JSON berupa objek {...}"
}
```
```bash
curl http://localhost:8080/admin/tidak-ada -H "X-Admin-Key: ganti-kunci-admin"
```
```json
{
  "ok": false,
  "message": "Endpoint tidak ada"
}
```

> Semua contoh respons di bagian ini adalah **keluaran asli** server contoh PHP saat koleksi Postman dijalankan (Node membalas bentuk yang sama). Daftar yang panjang dipotong.

### 5.1 Pengaturan

#### `GET /admin/settings`

```bash
curl http://localhost:8080/admin/settings -H "X-Admin-Key: ganti-kunci-admin"
```
```json
{
  "ok": true,
  "settings": {
    "api_key": "ganti-dengan-kunci-anda",
    "title": "Aplikasi Contoh",
    "dim_after": 60,
    "dim_level": 20,
    "screensaver_interval": 3,
    "screensaver_idle": 30,
    "duplicate_window": 60,
    "default_restart_at": "03:00"
  }
}
```

#### `PUT /admin/settings`

| Field | Aturan | Dikirim ke alat sebagai |
|---|---|---|
| `title` | teks 1-30 karakter | `config.title` (+ `message` di `/ping`) |
| `dim_after` | bilangan bulat `0` atau 10-3600 (detik) | `config.dim_after` |
| `dim_level` | bilangan bulat 0-100 (persen) | `config.dim_level` |
| `screensaver_interval` | bilangan bulat 2-60 (detik) | `interval` di `/announcements` |
| `screensaver_idle` | bilangan bulat 5-600 (detik) | `idle` di `/announcements` |
| `duplicate_window` | bilangan bulat 0-3600 (detik) | aturan `duplicate` di `/tap` |
| `default_restart_at` | `"HH:MM"` atau `""` (mati) | `config.restart_at` untuk alat tanpa jam restart sendiri |
| `api_key` | 8-64 karakter `A-Z a-z 0-9 . _ -` | dicek di header `X-API-Key`. **Mengganti ini memutus semua alat** sampai API key di setiap alat ikut diganti |

```bash
curl -X PUT http://localhost:8080/admin/settings -H "X-Admin-Key: ganti-kunci-admin" \
  -H "Content-Type: application/json" \
  -d '{"title": "Postman Uji", "dim_after": 120, "dim_level": 35, "screensaver_interval": 5, "screensaver_idle": 45, "duplicate_window": 0, "default_restart_at": "04:15"}'
```
```json
{
  "ok": true,
  "settings": {
    "api_key": "ganti-dengan-kunci-anda",
    "title": "Postman Uji",
    "dim_after": 120,
    "dim_level": 35,
    "screensaver_interval": 5,
    "screensaver_idle": 45,
    "duplicate_window": 0,
    "default_restart_at": "04:15"
  }
}
```

Satu field salah → tidak ada yang disimpan (422). Contoh body `{"title": "", "dim_after": 5, "dim_level": 101, "screensaver_interval": 1, "screensaver_idle": 700, "duplicate_window": -1, "default_restart_at": "25:00", "api_key": "pendek"}`:

```json
{
  "ok": false,
  "message": "Judul wajib diisi, 1-30 karakter",
  "errors": {
    "title": "Judul wajib diisi, 1-30 karakter",
    "dim_after": "dim_after harus 0 atau 10-3600 (detik)",
    "dim_level": "dim_level harus 0-100 (persen)",
    "screensaver_interval": "screensaver_interval harus 2-60 (detik)",
    "screensaver_idle": "screensaver_idle harus 5-600 (detik)",
    "duplicate_window": "duplicate_window harus 0-3600 (detik)",
    "default_restart_at": "default_restart_at harus \"HH:MM\" (00:00-23:59) atau \"\" (mati)",
    "api_key": "API key harus 8-64 karakter: huruf, angka, titik, garis bawah, atau tanda minus"
  }
}
```

Perubahan sampai ke alat di balasan `/ping` atau `/heartbeat` berikutnya:

```json
{
  "ok": true,
  "message": "Terhubung ke Postman Uji",
  "server_time": "2026-10-02T08:34:45+07:00",
  "config": {
    "title": "Postman Uji",
    "dim_after": 120,
    "dim_level": 35,
    "announcements_rev": "2-1790904822",
    "restart_at": "04:15"
  }
}
```

### 5.2 Anggota

Dipakai untuk mendaftarkan kartu (termasuk dari daftar Kartu belum terdaftar).

| Field | Aturan |
|---|---|
| `rfid` | wajib saat tambah; dinormalkan (spasi dibuang, huruf besar); maks. 32 karakter `0-9 A-F`; harus belum terdaftar. Tidak bisa diubah |
| `name` | wajib, 1-60 karakter |
| `photo_url` | URL `http(s)://`, `null`, atau `""` (= `null`). JPEG baseline maks. 160×160 px & 30 KB |
| `active` | `true`/`false` (bawaan `true`). `false` → tap dijawab `rejected` |

#### `GET /admin/members`

```bash
curl http://localhost:8080/admin/members -H "X-Admin-Key: ganti-kunci-admin"
```
```json
{
  "ok": true,
  "members": [
    {
      "rfid": "0218893066",
      "name": "Budi Santoso",
      "photo_url": null,
      "active": true
    },
    {
      "rfid": "0055555555",
      "name": "Rina Kurnia",
      "photo_url": null,
      "active": false
    },
    {
      "rfid": "0012345678",
      "name": "Siti Aminah",
      "photo_url": null,
      "active": true
    }
  ]
}
```

#### `POST /admin/members` → 201

```bash
curl -X POST http://localhost:8080/admin/members -H "X-Admin-Key: ganti-kunci-admin" \
  -H "Content-Type: application/json" \
  -d '{"rfid": "ab1a0fa3fdd3f", "name": "Postman Anggota", "photo_url": "https://contoh.com/foto/postman-160.jpg"}'
```
```json
{
  "ok": true,
  "member": {
    "rfid": "AB1A0FA3FDD3F",
    "name": "Postman Anggota",
    "photo_url": "https://contoh.com/foto/postman-160.jpg",
    "active": true
  }
}
```

Galat (422), body `{"rfid": "XYZ-123", "name": "", "photo_url": "ftp://contoh.com/a.jpg", "active": "ya"}`:

```json
{
  "ok": false,
  "message": "Nomor kartu hanya boleh angka 0-9 dan huruf A-F, maks. 32 karakter",
  "errors": {
    "rfid": "Nomor kartu hanya boleh angka 0-9 dan huruf A-F, maks. 32 karakter",
    "name": "Nama wajib diisi, maks. 60 karakter",
    "photo_url": "photo_url harus alamat http:// atau https:// (atau null)",
    "active": "active harus true atau false"
  }
}
```
```json
{
  "ok": false,
  "message": "Nomor kartu AB1A0FA3FDD3F sudah terdaftar",
  "errors": {
    "rfid": "Nomor kartu AB1A0FA3FDD3F sudah terdaftar"
  }
}
```

#### `PUT /admin/members/{rfid}`

```bash
curl -X PUT http://localhost:8080/admin/members/AB1A0FA3FDD3F -H "X-Admin-Key: ganti-kunci-admin" \
  -H "Content-Type: application/json" \
  -d '{"name": "Postman Anggota (diubah)", "photo_url": null, "active": false}'
```
```json
{
  "ok": true,
  "member": {
    "rfid": "AB1A0FA3FDD3F",
    "name": "Postman Anggota (diubah)",
    "photo_url": null,
    "active": false
  }
}
```

#### `DELETE /admin/members/{rfid}`

```bash
curl -X DELETE http://localhost:8080/admin/members/AB1A0FA3FDD3F -H "X-Admin-Key: ganti-kunci-admin"
```
```json
{
  "ok": true
}
```

Nomor kartu yang tidak ada → 404:

```json
{
  "ok": false,
  "message": "Anggota tidak ditemukan"
}
```

### 5.3 Kartu belum terdaftar

#### `GET /admin/unknown-cards`

Nomor kartu yang pernah di-tap dengan hasil `unknown` dan **sekarang** belum ada di anggota, urut `last_seen_at` terbaru. Begitu didaftarkan lewat `POST /admin/members`, kartu itu hilang dari daftar dan tap berikutnya langsung dikenali.

```bash
curl http://localhost:8080/admin/unknown-cards -H "X-Admin-Key: ganti-kunci-admin"
```
```json
{
  "ok": true,
  "cards": [
    {
      "rfid": "9904884543",
      "taps": 2,
      "first_seen_at": "2026-10-02T08:34:46+07:00",
      "last_seen_at": "2026-10-02T08:34:46+07:00",
      "last_device_id": "PM-MUQAJ0VZ"
    },
    {
      "rfid": "9999999990",
      "taps": 2,
      "first_seen_at": "2026-10-02T08:34:43+07:00",
      "last_seen_at": "2026-10-02T08:34:43+07:00",
      "last_device_id": "ABS-TES001"
    }
  ]
}
```

| Field | Isi |
|---|---|
| `rfid` | nomor kartu |
| `taps` | jumlah tap `unknown` |
| `first_seen_at`, `last_seen_at` | tap pertama & terakhir |
| `last_device_id` | alat tempat kartu terakhir ditempel |

Alur "Daftarkan" di halaman admin: ambil `rfid` dari daftar ini → `POST /admin/members {"rfid": "...", "name": "..."}`.

### 5.4 Rekap & kehadiran

#### `GET /admin/report?from=YYYY-MM-DD&to=YYYY-MM-DD[&format=csv]`

Per anggota per hari: `check_in` = tap `check_in` pertama, `check_out` = tap `check_out` terakhir, `duration_minutes` = selisihnya, `taps` = jumlah tap `check_in`/`check_out`/`duplicate`. Urut tanggal lalu nama. Tanpa `from`/`to` = hari ini. Rentang maks. **92 hari** (termasuk kedua ujung).

```bash
curl "http://localhost:8080/admin/report?from=2026-10-02&to=2026-10-02" -H "X-Admin-Key: ganti-kunci-admin"
```
```json
{
  "ok": true,
  "from": "2026-10-02",
  "to": "2026-10-02",
  "rows": [
    {
      "date": "2026-10-02",
      "rfid": "0218893066",
      "name": "Budi Santoso",
      "check_in": "08:33",
      "check_out": "08:34",
      "duration_minutes": 1,
      "taps": 4
    },
    {
      "date": "2026-10-02",
      "rfid": "9904884543",
      "name": "Postman Kartu Baru",
      "check_in": "08:34",
      "check_out": "08:34",
      "duration_minutes": 0,
      "taps": 2
    }
  ]
}
```

CSV (bisa dibuka di Excel):

```bash
curl -OJ "http://localhost:8080/admin/report?from=2026-10-02&to=2026-10-02&format=csv" -H "X-Admin-Key: ganti-kunci-admin"
# tersimpan sebagai rekap-2026-10-02-2026-10-02.csv
```
```csv
tanggal,rfid,nama,masuk,pulang,durasi_menit,jumlah_tap
2026-10-02,0218893066,Budi Santoso,08:33,08:34,1,4
2026-10-02,9904884543,Postman Kartu Baru,08:34,08:34,0,2
```

Galat (422):

```json
{
  "ok": false,
  "message": "Rentang rekap maksimal 92 hari",
  "errors": {
    "to": "Rentang rekap maksimal 92 hari"
  }
}
```
```json
{
  "ok": false,
  "message": "from harus tanggal YYYY-MM-DD",
  "errors": {
    "from": "from harus tanggal YYYY-MM-DD",
    "to": "to harus tanggal YYYY-MM-DD"
  }
}
```

#### `GET /admin/attendances?date=YYYY-MM-DD`

Semua tap pada satu tanggal (bawaan hari ini), termasuk `unknown`/`rejected`, terbaru dulu.

```bash
curl "http://localhost:8080/admin/attendances?date=2026-10-02" -H "X-Admin-Key: ganti-kunci-admin"
```
```json
{
  "ok": true,
  "date": "2026-10-02",
  "items": [
    {
      "id": 13,
      "time": "2026-10-02T08:34:46+07:00",
      "rfid": "9904884543",
      "name": "Postman Kartu Baru",
      "status": "check_out",
      "device_id": "PM-MUQAJ0VZ",
      "queued": false,
      "tap_id": "PM-1A0FA3FE512-A96D95"
    },
    {
      "id": 12,
      "time": "2026-10-02T08:34:46+07:00",
      "rfid": "9904884543",
      "name": "Postman Kartu Baru",
      "status": "check_in",
      "device_id": "PM-MUQAJ0VZ",
      "queued": false,
      "tap_id": "PM-1A0FA3FE4C2-537253"
    },
    {
      "id": 11,
      "time": "2026-10-02T08:34:46+07:00",
      "rfid": "9904884543",
      "name": "Postman Kartu Baru",
      "status": "unknown",
      "device_id": "PM-MUQAJ0VZ",
      "queued": false,
      "tap_id": "PM-1A0FA3FE38E-DBBB1F"
    }
  ]
}
```

`name` = nama anggota sekarang (kalau anggotanya sudah dihapus: nama saat tap, atau `null`). `queued: true` = tap dikirim belakangan dari antrean alat; `time`-nya jam tap asli.

### 5.5 Alat

Alat terdaftar otomatis saat `X-Device-ID` baru pertama kali memanggil API alat. Setiap request alat memperbarui `last_seen_at` (dan `firmware`/`ip`/`rssi`/`wifi_ssid` kalau dikirim); `/heartbeat` juga menyimpan kesehatan dari `raw`.

#### `GET /admin/devices`

Semua alat, urut `last_seen_at` terbaru.

```bash
curl http://localhost:8080/admin/devices -H "X-Admin-Key: ganti-kunci-admin"
```
```json
{
  "ok": true,
  "devices": [
    {
      "device_id": "PM-MUQAJ0VZ",
      "name": null,
      "online": true,
      "last_seen_at": "2026-10-02T08:34:47+07:00",
      "firmware": "1.5.0",
      "ip": "192.168.1.50",
      "rssi": -55,
      "wifi_ssid": "Kantor-2.4G",
      "uptime_s": 3600,
      "reset_reason": "poweron",
      "rfid_ok": true,
      "queue": 0,
      "free_heap": 181000,
      "min_free_heap": 150000,
      "error": null,
      "ota_failed": null,
      "pin": null,
      "restart_at": "04:15",
      "firmware_target": null,
      "firmware_state": null,
      "issues": []
    }
  ]
}
```

| Field | Isi |
|---|---|
| `device_id`, `name` | ID dari header `X-Device-ID`; nama bebas dari admin |
| `online` | ada request dari alat dalam 180 detik terakhir |
| `last_seen_at` | request terakhir |
| `firmware`, `ip`, `rssi`, `wifi_ssid` | dari body/`raw` request alat |
| `uptime_s`, `reset_reason`, `rfid_ok`, `queue`, `free_heap`, `min_free_heap`, `error`, `ota_failed` | dari `raw` heartbeat terakhir (tidak dikirim → `null`) |
| `pin` | PIN menu khusus alat ini (`null` = tidak dikirim ke alat) |
| `restart_at` | jam restart yang **berlaku** (milik alat, atau `default_restart_at`), `""` = mati |
| `firmware_target`, `firmware_state` | versi tujuan update; `null` / `pending` / `installed` / `failed` |
| `tap_mode` | mode absen yang dikirim server ke alat (`config.tap_mode`): `null` (ikuti pengaturan di alat), `"auto"`, atau `"select"` |
| `reported_tap_mode`, `tap_select` | dilaporkan alat lewat heartbeat (firmware ≥ 1.6.0): mode yang sedang dipakai dan pilihan saat ini (`check_in`/`check_out`/`null`) |
| `issues` | peringatan siap tampil (tabel di bawah) |

`issues` yang mungkin muncul:

| Kondisi | Pesan |
|---|---|
| tidak ada request > 600 detik | `Offline sejak <waktu>` |
| `rfid_ok` = `false` | `Pembaca RFID tidak terdeteksi (E30)` |
| `rssi` < −80 | `Sinyal WiFi lemah (-85 dBm)` |
| `queue` > 20 | `25 tap menunggu di antrean alat` |
| `error` terisi | `<kode> <arti>`, mis. `E31 Jam belum sinkron` (E10-E31, lihat spesifikasi bagian 5) |
| `ota_failed` terisi | `Update firmware 1.4.9 gagal, alat kembali ke 1.5.0` |
| ≥ 3 boot `watchdog`/`panic`/`brownout` dalam 24 jam | `Sering restart tidak normal: 3x dalam 24 jam` |
| `min_free_heap` < 20000 | `RAM hampir habis (15000 byte)` |

Contoh alat bermasalah (setelah heartbeat dengan `rfid_ok:false`, `rssi:-85`, `queue:25`, `error:"E31"`, `min_free_heap:15000`, `ota_failed:"1.4.9"`):

```json
{
  "ok": true,
  "device": {
    "device_id": "PM-MUQAJ0VZ",
    "name": "Lobi depan (Postman)",
    "online": true,
    "last_seen_at": "2026-10-02T08:34:48+07:00",
    "firmware": "1.5.0",
    "ip": "192.168.1.50",
    "rssi": -85,
    "wifi_ssid": "Kantor-2.4G",
    "uptime_s": 3660,
    "reset_reason": "poweron",
    "rfid_ok": false,
    "queue": 25,
    "free_heap": 30000,
    "min_free_heap": 15000,
    "error": "E31",
    "ota_failed": "1.4.9",
    "pin": null,
    "restart_at": "04:15",
    "firmware_target": null,
    "firmware_state": null,
    "issues": [
      "Pembaca RFID tidak terdeteksi (E30)",
      "Sinyal WiFi lemah (-85 dBm)",
      "25 tap menunggu di antrean alat",
      "E31 Jam belum sinkron",
      "Update firmware 1.4.9 gagal, alat kembali ke 1.5.0",
      "RAM hampir habis (15000 byte)"
    ]
  },
  "events": [
    {
      "type": "ota_failed",
      "message": "Update firmware 1.4.9 gagal, alat kembali ke 1.5.0",
      "details": {
        "version": "1.4.9",
        "firmware": "1.5.0"
      },
      "created_at": "2026-10-02T08:34:48+07:00"
    }
  ]
}
```

#### `GET /admin/devices/{device_id}`

Satu alat + `events` (20 kejadian terbaru, terbaru dulu). Jenis kejadian:

| `type` | Dicatat saat |
|---|---|
| `boot` | `uptime_s` lebih kecil dari heartbeat sebelumnya, atau lebih kecil dari jeda sejak heartbeat sebelumnya. Pesan: `Menyala ulang: <alasan>` |
| `crash` | `raw.crash` dikirim (yang sama dalam 10 menit tidak dicatat dua kali). `details` = isi `raw.crash` |
| `firmware` | versi firmware berubah: `Firmware 1.5.0 -> 9.9.9` |
| `ota_failed` | `raw.ota_failed` baru |

Maks. 200 kejadian disimpan per alat.

```bash
curl http://localhost:8080/admin/devices/PM-MUQAJ0VZ -H "X-Admin-Key: ganti-kunci-admin"
```
```json
{
  "ok": true,
  "device": {
    "device_id": "PM-MUQAJ0VZ",
    "name": "Lobi depan (Postman)",
    "online": true,
    "last_seen_at": "2026-10-02T08:34:48+07:00",
    "firmware": "1.5.0",
    "ip": "192.168.1.50",
    "rssi": -55,
    "wifi_ssid": "Kantor-2.4G",
    "uptime_s": 70,
    "reset_reason": "watchdog",
    "rfid_ok": true,
    "queue": 0,
    "free_heap": 181000,
    "min_free_heap": 150000,
    "error": null,
    "ota_failed": null,
    "pin": null,
    "restart_at": "04:15",
    "firmware_target": null,
    "firmware_state": null,
    "issues": []
  },
  "events": [
    {
      "type": "crash",
      "message": "Program crash di loopTask (PC 0x400d4634)",
      "details": {
        "task": "loopTask",
        "pc": "0x400d4634",
        "backtrace": "0x400d4634 0x400880ed",
        "elf": "3f2a9c1b"
      },
      "created_at": "2026-10-02T08:34:48+07:00"
    },
    {
      "type": "boot",
      "message": "Menyala ulang: watchdog (program macet)",
      "details": {
        "reset_reason": "watchdog",
        "uptime_s": 12
      },
      "created_at": "2026-10-02T08:34:48+07:00"
    },
    {
      "type": "ota_failed",
      "message": "Update firmware 1.4.9 gagal, alat kembali ke 1.5.0",
      "details": {
        "version": "1.4.9",
        "firmware": "1.5.0"
      },
      "created_at": "2026-10-02T08:34:48+07:00"
    }
  ]
}
```

`device_id` yang tidak ada → 404 `{"ok": false, "message": "Alat tidak ditemukan"}`.

#### `PUT /admin/devices/{device_id}`

| Field | Aturan | Dikirim ke alat |
|---|---|---|
| `name` | teks maks. 40 karakter; `""`/`null` = kosong | – |
| `pin` | teks 4-8 angka; `""`/`null` = hapus (alat memakai PIN terakhirnya) | `config.pin` |
| `restart_at` | `"HH:MM"`, `""` = tidak restart otomatis, `null` = ikut `default_restart_at` | `config.restart_at` |
| `firmware_target` | versi yang ada di `GET /admin/firmware`, atau `null` = tidak update | `config.firmware_update` |
| `tap_mode` | `null` (ikuti alat), `"auto"`, atau `"select"`; nilai lain → 422 | `config.tap_mode` |

```bash
curl -X PUT http://localhost:8080/admin/devices/PM-MUQAJ0VZ -H "X-Admin-Key: ganti-kunci-admin" \
  -H "Content-Type: application/json" \
  -d '{"name": "Lobi depan (Postman)", "pin": "4321", "restart_at": "05:30"}'
```
```json
{
  "ok": true,
  "device": {
    "device_id": "PM-MUQAJ0VZ",
    "name": "Lobi depan (Postman)",
    "online": true,
    "last_seen_at": "2026-10-02T08:34:47+07:00",
    "firmware": "1.5.0",
    "ip": "192.168.1.50",
    "rssi": -55,
    "wifi_ssid": "Kantor-2.4G",
    "uptime_s": 3600,
    "reset_reason": "poweron",
    "rfid_ok": true,
    "queue": 0,
    "free_heap": 181000,
    "min_free_heap": 150000,
    "error": null,
    "ota_failed": null,
    "pin": "4321",
    "restart_at": "05:30",
    "firmware_target": null,
    "firmware_state": null,
    "issues": []
  }
}
```

Galat (422), body `{"name": "<41 huruf>", "pin": "12", "restart_at": "25:00", "firmware_target": "0.0.1"}`:

```json
{
  "ok": false,
  "message": "Nama alat maks. 40 karakter",
  "errors": {
    "name": "Nama alat maks. 40 karakter",
    "pin": "PIN harus 4-8 angka (atau \"\" / null untuk menghapus)",
    "restart_at": "restart_at harus \"HH:MM\" (00:00-23:59), \"\" (mati), atau null (bawaan)",
    "firmware_target": "Versi firmware tidak ada. Unggah dulu lewat POST /admin/firmware"
  }
}
```

Balasan `/ping` alat itu sesudahnya:

```json
{
  "ok": true,
  "message": "Terhubung ke Postman Uji",
  "server_time": "2026-10-02T08:34:47+07:00",
  "config": {
    "title": "Postman Uji",
    "dim_after": 120,
    "dim_level": 35,
    "announcements_rev": "2-1790904822",
    "restart_at": "05:30",
    "pin": "4321"
  }
}
```

### 5.6 Firmware

Alur: unggah `.bin` → jadwalkan ke **satu** alat (`PUT /admin/devices/{id}` `firmware_target`) → alat menerima `config.firmware_update` di `/ping`/`/heartbeat` berikutnya → alat mengunduh, memasang, restart, lalu melapor versi baru di heartbeat → `firmware_state` = `installed`. Kalau berhasil, baru terapkan ke semua alat.

#### `POST /admin/firmware?version=X.Y.Z&notes=teks` → 201

Body = **isi file `.bin` mentah** (hasil `./upload.sh -b`, lihat README utama), `Content-Type: application/octet-stream`.

| Aturan | Galat |
|---|---|
| `version` format `angka.angka.angka` dan belum pernah diunggah | 422 `errors.version` |
| ukuran 1-1966080 byte (slot OTA `min_spiffs`) | 422 `errors.file` |
| byte pertama `0xE9` (image aplikasi ESP32, bukan file gabungan/bootloader) | 422 `errors.file` |
| teks versi ada di dalam file (mencegah salah label) | 422 `errors.file` |

```bash
curl -X POST "http://localhost:8080/admin/firmware?version=9.9.9&notes=Firmware%20contoh%20Postman" \
  -H "X-Admin-Key: ganti-kunci-admin" -H "Content-Type: application/octet-stream" \
  --data-binary @contoh-integrasi/postman/contoh-firmware.bin
```
```json
{
  "ok": true,
  "release": {
    "version": "9.9.9",
    "size": 384,
    "md5": "482f6ed9a8c9cce753c8e1c5767e2daf",
    "notes": "Firmware contoh Postman",
    "uploaded_at": "2026-10-02T08:34:48+07:00",
    "devices": 0
  }
}
```

(`contoh-firmware.bin` adalah firmware **palsu** 384 byte untuk uji, berisi teks `AbsensiRFID/9.9.9`. Jangan dipasang ke alat.)

Galat (422):

```json
{
  "ok": false,
  "message": "Versi 9.9.8 tidak ditemukan di dalam file. Pastikan VERSI_FIRMWARE di config.h sama.",
  "errors": {
    "file": "Versi 9.9.8 tidak ditemukan di dalam file. Pastikan VERSI_FIRMWARE di config.h sama."
  }
}
```
```json
{
  "ok": false,
  "message": "Bukan file firmware ESP32 (byte pertama harus 0xE9). Pakai file .bin aplikasi, bukan file gabungan/bootloader",
  "errors": {
    "file": "Bukan file firmware ESP32 (byte pertama harus 0xE9). Pakai file .bin aplikasi, bukan file gabungan/bootloader"
  }
}
```
```json
{
  "ok": false,
  "message": "Versi 9.9.9 sudah ada. Hapus dulu atau pakai nomor versi baru",
  "errors": {
    "version": "Versi 9.9.9 sudah ada. Hapus dulu atau pakai nomor versi baru"
  }
}
```

#### `GET /admin/firmware`

`devices` = jumlah alat yang `firmware_target`-nya versi ini.

```bash
curl http://localhost:8080/admin/firmware -H "X-Admin-Key: ganti-kunci-admin"
```
```json
{
  "ok": true,
  "releases": [
    {
      "version": "9.9.9",
      "size": 384,
      "md5": "482f6ed9a8c9cce753c8e1c5767e2daf",
      "notes": "Firmware contoh Postman",
      "uploaded_at": "2026-10-02T08:34:48+07:00",
      "devices": 1
    }
  ]
}
```

#### Menjadwalkan ke satu alat

```bash
curl -X PUT http://localhost:8080/admin/devices/PM-MUQAJ0VZ -H "X-Admin-Key: ganti-kunci-admin" \
  -H "Content-Type: application/json" -d '{"firmware_target": "9.9.9"}'
```

Balasan `/ping` alat itu kemudian membawa `firmware_update`. `url` = Base URL alat + `/firmware/{versi}` (satu origin, supaya alat ikut mengirim API key; di belakang reverse proxy skemanya mengikuti `X-Forwarded-Proto`):

```json
{
  "ok": true,
  "message": "Terhubung ke Postman Uji",
  "server_time": "2026-10-02T08:34:49+07:00",
  "config": {
    "title": "Postman Uji",
    "dim_after": 120,
    "dim_level": 35,
    "announcements_rev": "2-1790904822",
    "restart_at": "04:15",
    "firmware_update": {
      "version": "9.9.9",
      "url": "http://localhost:8080/firmware/9.9.9",
      "size": 384,
      "md5": "482f6ed9a8c9cce753c8e1c5767e2daf"
    }
  }
}
```

`firmware_update` hanya dikirim kalau alat punya target, versi target ≠ `firmware` alat, dan ≠ `ota_failed` alat.

#### `GET {base}/firmware/{versi}` (dipanggil alat)

Auth alat biasa (`X-API-Key` + `X-Device-ID`). Hanya alat yang dijadwalkan ke versi itu yang boleh mengunduh.

```bash
curl -o firmware.bin -D - http://localhost:8080/firmware/9.9.9 \
  -H "X-API-Key: ganti-dengan-kunci-anda" -H "X-Device-ID: PM-MUQAJ0VZ"
```
```http
HTTP/1.1 200 OK
Content-Type: application/octet-stream
Content-Length: 384
x-MD5: 482f6ed9a8c9cce753c8e1c5767e2daf

(isi file .bin mentah)
```

Alat lain / versi lain → 404:

```json
{
  "ok": false,
  "message": "Firmware tidak tersedia untuk alat ini"
}
```

Setelah alat melapor `"firmware": "9.9.9"` di heartbeat, `GET /admin/devices/{id}` menunjukkan `firmware_state: "installed"` dan kejadian `Firmware 1.5.0 -> 9.9.9`. Kalau alat melapor `raw.ota_failed: "9.9.9"`, `firmware_state` menjadi `failed` dan update tidak dikirim lagi untuk versi itu.

#### `POST /admin/firmware/{versi}/apply-all`

Jadwalkan versi ini ke **semua** alat terdaftar. `devices` = jumlah alat yang dijadwalkan.

```bash
curl -X POST http://localhost:8080/admin/firmware/9.9.9/apply-all -H "X-Admin-Key: ganti-kunci-admin"
```
```json
{
  "ok": true,
  "devices": 2
}
```

#### `DELETE /admin/firmware/{versi}`

Menghapus file & data. Alat yang dijadwalkan ke versi ini tidak jadi update (`firmware_target` → `null`).

```bash
curl -X DELETE http://localhost:8080/admin/firmware/9.9.9 -H "X-Admin-Key: ganti-kunci-admin"
```
```json
{
  "ok": true
}
```

Versi yang tidak ada → 404 `{"ok": false, "message": "Firmware tidak ditemukan"}`.

### 5.7 Pengumuman

| Field | Aturan |
|---|---|
| `title` | wajib, 1-40 karakter |
| `description` | 0-160 karakter (bawaan `""`) |
| `icon` | `info` (bawaan), `pengumuman`, `kalender`, `jam`, `peringatan`, `rapat`, `libur`, `selamat`, `kesehatan`, `buku` |
| `active` | `true`/`false` (bawaan `true`). Hanya yang aktif dikirim ke alat |
| `order` | bilangan bulat (bawaan 0). Alat menerima urut `order` lalu `id`, maks. 10 |

Setiap perubahan mengganti `rev` (`"<jumlah aktif>-<waktu>"`, selalu berbeda dari sebelumnya). Nilai ini dikirim sebagai `config.announcements_rev`; alat yang melihat rev berubah langsung mengambil ulang `GET /announcements` (dalam ±1 menit).

#### `GET /admin/announcements`

```bash
curl http://localhost:8080/admin/announcements -H "X-Admin-Key: ganti-kunci-admin"
```
```json
{
  "ok": true,
  "rev": "2-1790904822",
  "items": [
    {
      "id": 1,
      "title": "Rapat Guru",
      "description": "Hari ini pukul 13.00 di aula lantai 2.",
      "icon": "rapat",
      "active": true,
      "order": 0
    },
    {
      "id": 2,
      "title": "Libur Nasional",
      "description": "Kamis, 2 Oktober 2026 kantor tutup.",
      "icon": "libur",
      "active": true,
      "order": 0
    }
  ]
}
```

#### `POST /admin/announcements` → 201

```bash
curl -X POST http://localhost:8080/admin/announcements -H "X-Admin-Key: ganti-kunci-admin" \
  -H "Content-Type: application/json" \
  -d '{"title": "Tes Postman", "description": "Pengumuman ini dibuat oleh koleksi Postman.", "icon": "peringatan", "order": -100}'
```
```json
{
  "ok": true,
  "item": {
    "id": 3,
    "title": "Tes Postman",
    "description": "Pengumuman ini dibuat oleh koleksi Postman.",
    "icon": "peringatan",
    "active": true,
    "order": -100
  },
  "rev": "3-1790904890"
}
```

Yang diterima alat (`GET /announcements`, `id` berupa teks):

```json
{
  "ok": true,
  "interval": 5,
  "idle": 45,
  "items": [
    {
      "id": "3",
      "title": "Tes Postman",
      "description": "Pengumuman ini dibuat oleh koleksi Postman.",
      "icon": "peringatan"
    },
    {
      "id": "1",
      "title": "Rapat Guru",
      "description": "Hari ini pukul 13.00 di aula lantai 2.",
      "icon": "rapat"
    },
    {
      "id": "2",
      "title": "Libur Nasional",
      "description": "Kamis, 2 Oktober 2026 kantor tutup.",
      "icon": "libur"
    }
  ]
}
```

Galat (422):

```json
{
  "ok": false,
  "message": "Judul wajib diisi, maks. 40 karakter",
  "errors": {
    "title": "Judul wajib diisi, maks. 40 karakter",
    "description": "Deskripsi maks. 160 karakter",
    "icon": "Ikon harus salah satu dari: info, pengumuman, kalender, jam, peringatan, rapat, libur, selamat, kesehatan, buku",
    "active": "active harus true atau false",
    "order": "order harus bilangan bulat"
  }
}
```

#### `PUT /admin/announcements/{id}`

```bash
curl -X PUT http://localhost:8080/admin/announcements/3 -H "X-Admin-Key: ganti-kunci-admin" \
  -H "Content-Type: application/json" -d '{"title": "Tes Postman (diubah)"}'
```
```json
{
  "ok": true,
  "item": {
    "id": 3,
    "title": "Tes Postman (diubah)",
    "description": "Pengumuman ini dibuat oleh koleksi Postman.",
    "icon": "peringatan",
    "active": true,
    "order": -100
  },
  "rev": "3-1790904891"
}
```

#### `DELETE /admin/announcements/{id}`

```bash
curl -X DELETE http://localhost:8080/admin/announcements/3 -H "X-Admin-Key: ganti-kunci-admin"
```
```json
{
  "ok": true,
  "rev": "2-1790904893"
}
```

`id` yang tidak ada → 404 `{"ok": false, "message": "Pengumuman tidak ditemukan"}`.

---

## 6. Menguji API alat dengan `cek-server.sh`

Skrip ini berpura-pura menjadi alat dan memeriksa **API alat** server mana pun (server contoh, server acuan, atau aplikasi Anda). Butuh `bash`, `curl`, dan `python3` saja.

```bash
cd contoh-integrasi/tes
./cek-server.sh BASE_URL API_KEY [RFID_TERDAFTAR]

# contoh
./cek-server.sh http://localhost:8080 ganti-dengan-kunci-anda 0218893066
./cek-server.sh https://app.contoh.com/api/absensi rahasia-kantor-123 0012345678
```

Yang diperiksa:
1. `/ping`: `ok`, `server_time` ISO 8601, dan `config` (`title` teks 1-30, `dim_after` 0 atau 10-3600, `dim_level` 0-100, `restart_at` `"HH:MM"`/`""`, `announcements_rev` teks, `pin` 4-8 digit, `firmware_update` lengkap). Kunci `config` yang tidak dikirim diberi ⚠️.
2. API key salah → **401** (untuk `/ping` dan `/tap`).
3. `/heartbeat` dengan kesehatan lengkap (`min_free_heap`, `error`, `ota_failed`, `crash`) dan heartbeat biasa → 200.
4. `/tap`: kartu terdaftar, kirim ulang `tap_id` yang sama (balasan sama atau `duplicate`), antrean dengan `tapped_at` kemarin, antrean dengan `tapped_at: null` & `raw: null`, kartu tak terdaftar (`unknown`), `ok` sesuai `status`.
5. Format salah (body bukan JSON, `rfid` kosong) → **400**.
6. `/announcements`: 404 hanya ⚠️; kalau 200, formatnya diperiksa (maks. 10 item, `title`, `id` teks, ikon dikenal, `interval` 2-60, `idle` 5-600).
7. Kalau heartbeat membalas `config.firmware_update`: file di `url` diunduh (dengan header API kalau satu origin), lalu `Content-Length`, ukuran, dan MD5-nya dicocokkan.
8. Batas waktu: `/ping` < 8 detik, endpoint lain < 3 detik.

Setiap pemeriksaan ditandai ✅ atau ❌; ⚠️ = saran. Kode keluar = jumlah yang gagal (`0` = lulus semua), jadi bisa dipakai di CI. Potongan keluarannya:

```text
Memeriksa http://localhost:8080  (RFID uji: 0218893066)

1. Tes koneksi
→ GET /ping   (HTTP 200, 0.002112s)
    {"ok":true,"message":"Terhubung ke Aplikasi Contoh","server_time":"2026-10-02T08:36:12+07:00","config":{"title":"Aplikasi Contoh","dim_after":60," ...
  ✅ HTTP 200
  ✅ "ok" = true
  ✅ "server_time" format ISO 8601 + zona waktu (2026-10-02T08:36:12+07:00)
  ✅ "config" berupa objek
  ✅ "config.title" berupa teks, maks. 30 karakter (15)
  ✅ "config.announcements_rev" berupa teks ('2-1790904964')
  ✅ "config.dim_after" bilangan bulat 0 atau 10–3600 (60)
  ✅ "config.dim_level" bilangan bulat 0–100 (20)
  ✅ "config.restart_at" teks "" atau "HH:MM" 00:00–23:59 ('03:00')

...
12. Update firmware jarak jauh (opsional, hanya kalau heartbeat mengirim config.firmware_update)
  ⚠️  server tidak mengirim config.firmware_update untuk ABS-TES001 (wajar kalau alat ini tidak dijadwalkan update)

✅ SEMUA PEMERIKSAAN LULUS
```

Untuk memastikan kiriman ulang `tap_id` benar-benar **tidak menambah baris** di database, isi `HITUNG_DATA` dengan perintah yang mencetak jumlah baris absensi:

```bash
# server PHP bawaan
HITUNG_DATA="sqlite3 ../php/data.sqlite 'SELECT COUNT(*) FROM absensi'" \
  ./cek-server.sh http://localhost:8080 ganti-dengan-kunci-anda

# server Node bawaan
HITUNG_DATA="python3 -c \"import json; print(len(json.load(open('../node/data.json'))['absensi']))\"" \
  ./cek-server.sh http://localhost:8080 ganti-dengan-kunci-anda

# aplikasi Anda (contoh MySQL)
HITUNG_DATA="mysql -N -e 'SELECT COUNT(*) FROM absensi' nama_db" ./cek-server.sh ...
```

Untuk menguji alur unduh firmware dengan server contoh, jadwalkan dulu firmware ke alat uji skrip (`ABS-TES001`):

```bash
curl -X POST "http://localhost:8080/admin/firmware?version=9.9.9" -H "X-Admin-Key: ganti-kunci-admin" \
  -H "Content-Type: application/octet-stream" --data-binary @../postman/contoh-firmware.bin
curl -X PUT http://localhost:8080/admin/devices/ABS-TES001 -H "X-Admin-Key: ganti-kunci-admin" \
  -H "Content-Type: application/json" -d '{"firmware_target": "9.9.9"}'
./cek-server.sh http://localhost:8080 ganti-dengan-kunci-anda      # langkah 12 ikut mengunduh
curl -X DELETE http://localhost:8080/admin/firmware/9.9.9 -H "X-Admin-Key: ganti-kunci-admin"
```

> Skrip ini mengirim tap & heartbeat sungguhan (kartu `9999999990`, RFID yang Anda berikan, alat `ABS-TES001`). Jalankan di server uji, bukan di data produksi.

---
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

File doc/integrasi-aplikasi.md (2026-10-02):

# Panduan Integrasi Aplikasi

Panduan ini untuk **pengembang aplikasi lain** (sistem sekolah, HRIS, ERP, dan sebagainya) yang ingin memakai alat **Absensi RFID Terintegrasi**. Isinya: apa yang wajib dibangun, dari mana datanya, dan cara mengujinya sampai siap dipakai.

Panduan ini dipakai bersama tiga sumber lain:

| Dokumen | Isi |
|---|---|
| [spesifikasi-api.md](spesifikasi-api.md) | **Kontrak teknis** antara alat dan aplikasi: endpoint, header, format JSON, kode HTTP |
| [contoh-integrasi/](../contoh-integrasi/README.md) | Server contoh **PHP** dan **Node.js** yang sudah menjalankan semua fitur di panduan ini |
| [contoh-integrasi/postman/](../contoh-integrasi/postman/) | Koleksi **Postman** untuk menguji aplikasi Anda (bisa dijalankan otomatis dengan Newman) |

Server acuan Laravel di [api/](../api/README.md) juga menjalankan semua fitur ini lengkap dengan panel admin. Bisa dipakai langsung, atau dijadikan contoh.

---

## Daftar isi

1. [Gambaran besar](#1-gambaran-besar)
2. [Fitur wajib](#2-fitur-wajib)
3. [Urutan kerja integrasi](#3-urutan-kerja-integrasi)
4. [Data yang perlu disimpan](#4-data-yang-perlu-disimpan)
5. [API alat (yang dipanggil alat)](#5-api-alat-yang-dipanggil-alat)
6. [Fitur wajib satu per satu](#6-fitur-wajib-satu-per-satu)
7. [Server contoh & API admin contoh](#7-server-contoh--api-admin-contoh)
8. [Menguji dengan Postman & Newman](#8-menguji-dengan-postman--newman)
9. [Checklist siap pakai](#9-checklist-siap-pakai)
10. [Masalah yang sering terjadi](#10-masalah-yang-sering-terjadi)

---
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

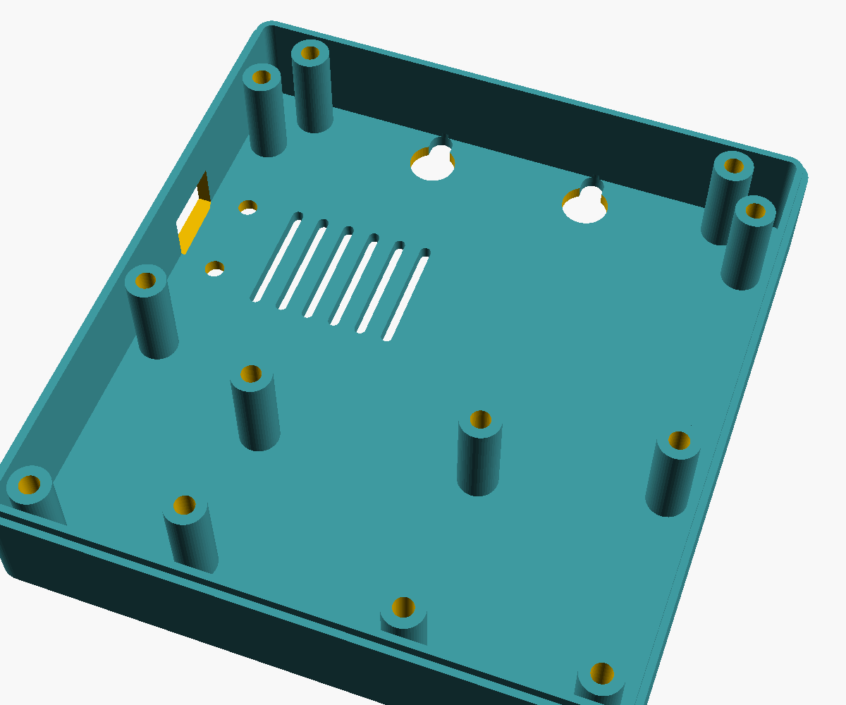
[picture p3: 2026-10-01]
hardware/casing/hasil/pratinjau-dalam.png

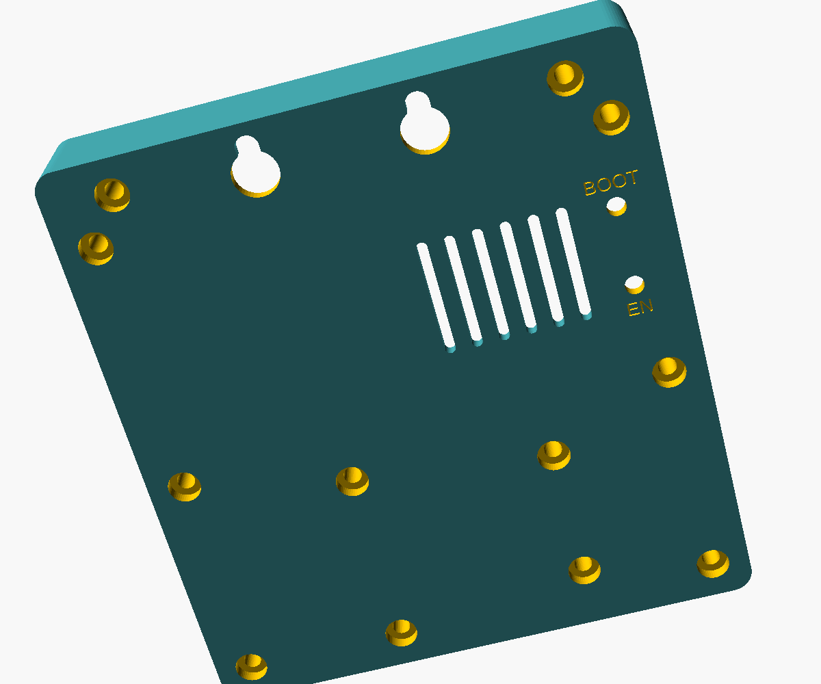
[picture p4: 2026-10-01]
hardware/casing/hasil/pratinjau-belakang.png

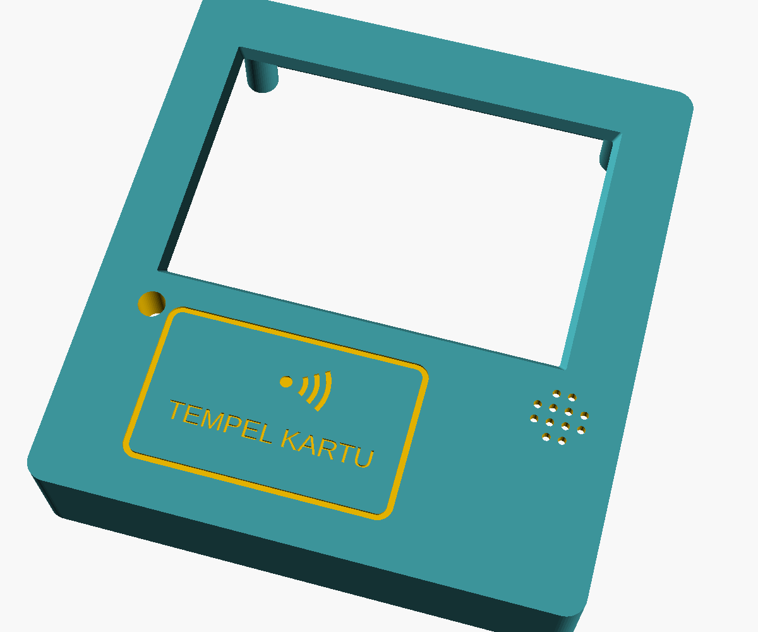
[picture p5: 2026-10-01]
hardware/casing/hasil/pratinjau-depan.png

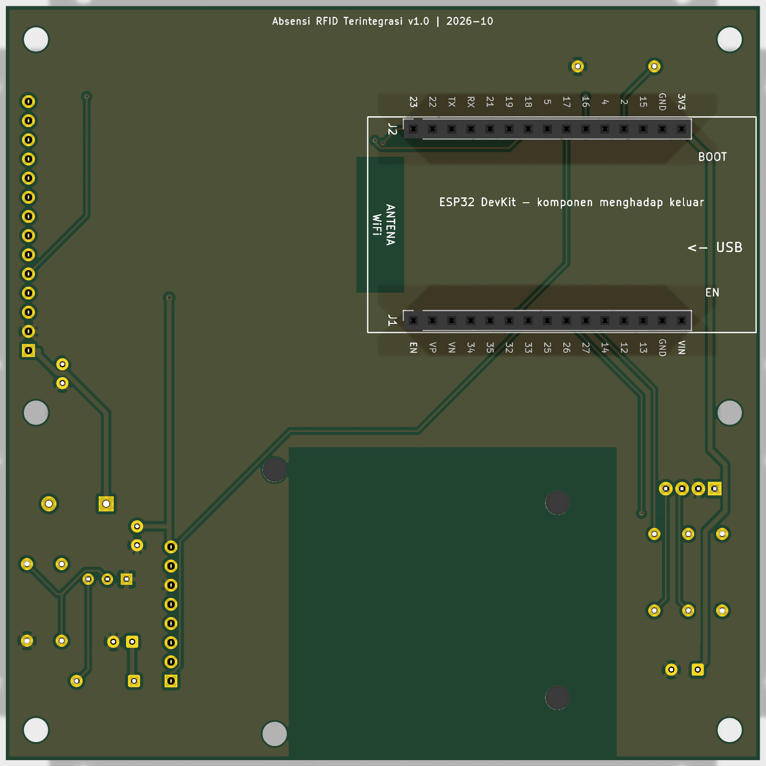
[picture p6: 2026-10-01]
hardware/pcb/hasil/3d-belakang.png

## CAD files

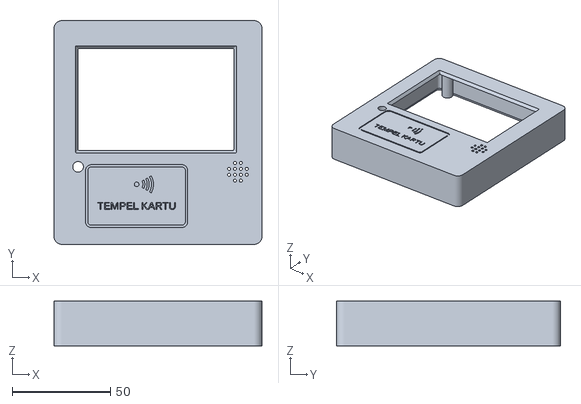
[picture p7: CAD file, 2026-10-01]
hardware/casing/hasil/casing-depan.stl
105.8 x 113.8 x 22.8

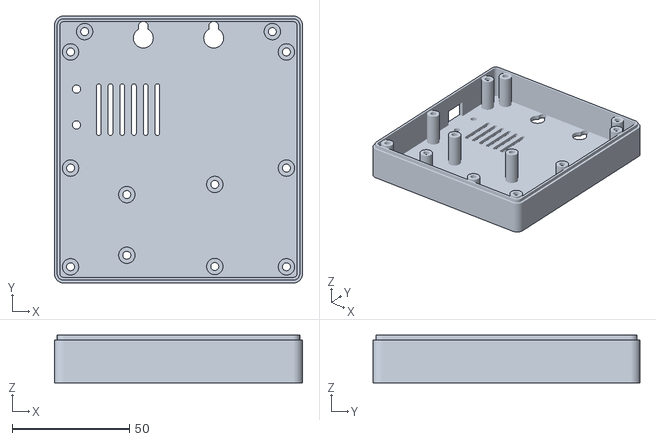
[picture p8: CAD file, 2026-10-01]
hardware/casing/hasil/casing-belakang.stl
105.8 x 113.8 x 20.4

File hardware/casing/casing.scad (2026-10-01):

// Casing Absensi RFID Terintegrasi untuk papan 100 x 100 mm (hardware/pcb/buat_pcb.py dan
// hardware/dotmatrix/tata_letak.py; pilih dengan parameter `versi`).
// Dua bagian, disatukan 4 baut M3 dari belakang:
//   depan    : panel depan + dinding (jendela LCD, area tempel kartu, lubang LED & buzzer)
//   belakang : tutup belakang (lubang USB di kiri, lubang EN & BOOT, gantungan dinding, ventilasi)
//
// Buka di OpenSCAD, pilih bagian di bawah (atau lewat Customizer), lalu F6 dan File > Export > STL.
// Atau jalankan hardware/casing/buat.sh untuk membuat semua STL + gambar sekaligus.
//
// Koordinat papan sama dengan hardware/pcb/buat_pcb.py: dilihat dari DEPAN, (0,0) = pojok kiri atas PCB,
// X ke kanan, Y ke BAWAH. Fungsi di() mengubahnya ke koordinat OpenSCAD (Y ke atas).
// Z = 0 di permukaan belakang casing, makin besar makin ke depan.

/* [Bagian] */
bagian = "rakit"; // [depan, belakang, rakit]
// dotmatrix = papan dot matrix (hardware/dotmatrix/tata_letak.py), pcb = PCB cetak (hardware/pcb/buat_pcb.py)
versi = "dotmatrix"; // [dotmatrix, pcb]

/* [Ukuran umum (mm)] */
dinding = 2.4;        // tebal dinding samping & tutup belakang
panel = 2.0;          // tebal panel depan (di atas kartu RFID; makin tipis makin jauh jarak baca)
jarak_pcb = 0.5;      // celah PCB ke dinding
pita_atas = 8.5;      // ruang di atas PCB untuk baut penyatu casing
bulat = 4;            // jari-jari sudut luar

/* [Tinggi susunan (mm)] */
ruang_esp32 = 18;     // tutup belakang ke PCB: ESP32 + soket 8.5 + komponen ESP32
tebal_pcb = 1.6;
tinggi_soket = 11.04; // soket female 8.5 + plastik header modul 2.54 (LCD & RC522 sama)
tebal_lcd = 5.8;      // PCB LCD + layar + touch (gambar resmi MSP3520)
celah_lcd = 0.4;      // layar ke panel depan

/* [Baut] */
lubang_baut = 3.4;    // lubang tembus M3
lubang_ulir = 2.6;    // lubang pilot untuk baut M3 masuk langsung ke plastik
kepala_baut = 6.2;    // ceruk kepala baut di belakang
dalam_kepala = 2.5;
tiang = 7;            // diameter tiang baut

$fn = 48;

// ---------- Turunan ----------
Z_PCB = dinding + ruang_esp32;                              // permukaan belakang PCB
Z_PCB_ATAS = Z_PCB + tebal_pcb;
Z_PANEL = Z_PCB_ATAS + tinggi_soket + tebal_lcd + celah_lcd; // permukaan dalam panel depan
Z_ATAS = Z_PANEL + panel;
Z_SAMBUNG = Z_PCB - 2;                                       // sambungan berundak depan/belakang

// Rongga dalam & luar (koordinat papan: Y ke bawah)
D_X0 = -jarak_pcb;  D_X1 = 100 + jarak_pcb;
D_Y0 = -pita_atas;  D_Y1 = 100 + jarak_pcb;
L_X0 = D_X0 - dinding;  L_X1 = D_X1 + dinding;
L_Y0 = D_Y0 - dinding;  L_Y1 = D_Y1 + dinding;

function di(x, y) = [x, 100 - y];

// ---------- Posisi dari PCB (pcb/buat_pcb.py) ----------
LUBANG_LCD = [[4.0, 4.42], [96.0, 4.42], [4.0, 53.92], [96.0, 53.92]];
// Versi dot matrix: komponen di grid 2.54 mm, RC522 & ESP32 bergeser +-1 mm dari desain PCB
DM = versi == "dotmatrix";
LUBANG_RC522 = DM ? [[65.47, 95.88], [65.47, 60.88], [27.97, 91.08], [27.97, 65.23]]
                  : [[64.35, 96.52], [64.35, 61.52], [26.85, 91.72], [26.85, 65.87]];
LUBANG_PCB_BAWAH = [[4.0, 96.0], [96.0, 96.0]];     // baut casing lewat PCB
BAUT_ATAS = [[10, -4.25], [90, -4.25]];             // baut casing di pita atas (tanpa PCB)

// Area layar sentuh yang terlihat (RTP VA 77.84 x 50.56, landscape, LCD di (1,1))
JENDELA = [1 + 9.05, 1 + 2.89, 1 + 9.05 + 77.84, 1 + 2.89 + 50.56];
LED = DM ? [9.37, 63.46] : [9.24, 64.0];
BUZZER = DM ? [90.65, 66.0] : [90.5, 66.0];
KARTU_TENGAH = DM ? [39.12, 78.36] : [39, 79];      // tengah antena RC522

// ESP32 di belakang PCB: USB di tepi kiri, tombol EN & BOOT dekat USB
USB_Y = DM ? 27.9 : 29.0;
TOMBOL_EN = DM ? [6.52, 35.52] : [6.28, 36.62];
TOMBOL_BOOT = DM ? [6.52, 20.28] : [6.28, 21.38];
Z_ESP32_PCB = Z_PCB - tinggi_soket - tebal_pcb;     // permukaan komponen ESP32 (menghadap belakang)

// ---------- Alat bantu ----------
module kotak_bulat(x0, y0, x1, y1, z0, z1, r) {
    // x0,y0,x1,y1 dalam koordinat papan
    a = di(x0, y1); b = di(x1, y0);
    rr = max(0.01, r);
    translate([0, 0, z0]) hull() for (x = [a[0] + rr, b[0] - rr], y = [a[1] + rr, b[1] - rr])
        translate([x, y, 0]) cylinder(r = rr, h = z1 - z0);
}

module di_titik(p) { translate([di(p[0], p[1])[0], di(p[0], p[1])[1], 0]) children(); }

module luar(z0, z1) { kotak_bulat(L_X0, L_Y0, L_X1, L_Y1, z0, z1, bulat); }
module rongga(z0, z1, susut = 0) {
    kotak_bulat(D_X0 + susut, D_Y0 + susut, D_X1 - susut, D_Y1 - susut, z0, z1, max(0.5, bulat - dinding - susut));
}

// ---------- Tutup belakang ----------
module belakang() {
    difference() {
        union() {
            luar(0, dinding);
            // dinding penuh sampai sambungan, lalu bibir dalam (setengah tebal) sampai PCB
            difference() { luar(0, Z_SAMBUNG); rongga(-1, Z_SAMBUNG + 1); }
            difference() { rongga(Z_SAMBUNG - 0.01, Z_PCB, -dinding / 2); rongga(Z_SAMBUNG - 1, Z_PCB + 1); }
            // tiang: PCB duduk di atasnya
            for (p = concat(LUBANG_LCD, LUBANG_RC522, LUBANG_PCB_BAWAH, BAUT_ATAS))
                di_titik(p) cylinder(d = tiang, h = Z_PCB);
        }
        // lubang tembus + ceruk kepala baut (dari luar belakang)
        for (p = concat(LUBANG_LCD, LUBANG_RC522, LUBANG_PCB_BAWAH, BAUT_ATAS)) di_titik(p) {
            translate([0, 0, -1]) cylinder(d = lubang_baut, h = Z_PCB + 2);
            translate([0, 0, -1]) cylinder(d = kepala_baut, h = dalam_kepala + 1);
        }
        // lubang USB-C di dinding kiri
        translate([L_X0 - 1, di(0, USB_Y)[1] - 6.5, dinding])
            cube([dinding + 2, 13, max(9, Z_ESP32_PCB + 2 - dinding)]);
        // lubang tombol EN & BOOT (tekan dengan tusuk gigi)
        for (p = [TOMBOL_EN, TOMBOL_BOOT]) di_titik(p) translate([0, 0, -1]) cylinder(d = 3.5, h = dinding + 2);
        // gantungan dinding (lubang kunci): masukkan kepala sekrup ke lingkaran besar, geser ke bawah
        for (x = [35, 65]) {
            di_titik([x, -1.5]) translate([0, 0, -1]) cylinder(d = 8.5, h = dinding + 2);
            hull() for (y = [-1.5, -6.5]) di_titik([x, y]) translate([0, 0, -1]) cylinder(d = 4.2, h = dinding + 2);
        }
        // ventilasi di belakang ESP32
        for (x = [16 : 5 : 41]) hull() for (y = [19, 39]) di_titik([x, y]) translate([0, 0, -1]) cylinder(d = 2, h = dinding + 2);
        // tulisan (dicerminkan supaya terbaca dari belakang)
        for (t = [["EN", TOMBOL_EN + [0, 4.5]], ["BOOT", TOMBOL_BOOT - [0, 4.5]]]) di_titik(t[1])
            translate([0, 0, -0.01]) mirror([1, 0, 0]) linear_extrude(0.6)
                text(t[0], size = 2.5, halign = "center", valign = "center");
        // di_titik([46, 80]) translate([0, 0, -0.01]) mirror([1, 0, 0]) linear_extrude(0.6)
            // text("Absensi Alat", size = 6, halign = "center", valign = "center");
    }
}
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

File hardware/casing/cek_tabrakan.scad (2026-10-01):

// Cek tabrakan: casing (depan + belakang) diiris dengan model kasar isi casing, satu per satu.
// Dipakai oleh buat.sh: openscad -D 'item=N' -o hasil.stl cek_tabrakan.scad
// Hasil kosong (atau volume ~0, hanya bersentuhan) = tidak bertabrakan.
include <casing.scad>
bagian = "cek";
item = 0;

NAMA_ITEM = ["PCB", "LCD", "RC522 + komponennya", "ESP32 + komponennya", "colokan USB-C", "soket LCD",
             "soket RC522", "buzzer", "elko C1", "LED (ditinggikan 13 mm)", "elko C3"];

module blok(x0, y0, x1, y1, z0, z1) translate([x0, 100 - y1, z0]) cube([x1 - x0, y1 - y0, z1 - z0]);

module isi(i) {
    if (i == 0) blok(0, 0, 100, 100, Z_PCB, Z_PCB_ATAS);
    if (i == 1) blok(1, 1, 99, 57.34, Z_PCB_ATAS + tinggi_soket, Z_PCB_ATAS + tinggi_soket + tebal_lcd);
    if (i == 2) blok(DM ? 21.12 : 20, DM ? 58.36 : 59, DM ? 81.12 : 80, DM ? 98.36 : 99, Z_PCB_ATAS + tinggi_soket, Z_PCB_ATAS + tinggi_soket + 1.6 + 3.5);
    if (i == 3) blok(DM ? 0.74 : 0.5, USB_Y - 14, DM ? 52.24 : 52, USB_Y + 14, Z_ESP32_PCB - 3.5, Z_ESP32_PCB + tebal_pcb);
    if (i == 4) blok(-1.2, USB_Y - 4, 8, USB_Y + 4, Z_ESP32_PCB - 3.3, Z_ESP32_PCB);
    if (i == 5) blok(95.7, 12.0, 98.3, 47.0, Z_PCB_ATAS, Z_PCB_ATAS + tinggi_soket);
    if (i == 6) blok(DM ? 77.95 : 76.8, DM ? 69.8 : 70.5, DM ? 80.49 : 79.4, DM ? 90.1 : 90.8, Z_PCB_ATAS, Z_PCB_ATAS + tinggi_soket);
    if (i == 7) translate([BUZZER[0], 100 - BUZZER[1], Z_PCB_ATAS]) cylinder(r = 6.2, h = 9.5);
    if (i == 8) translate(DM ? [10.64, 100 - 88.86, Z_PCB_ATAS] : [10, 100 - 88, Z_PCB_ATAS]) cylinder(r = 4.2, h = 12.5);
    if (i == 9) translate([LED[0], 100 - LED[1], Z_PCB_ATAS]) cylinder(r = 2.6, h = 13);
    if (i == 10) translate(DM ? [95.73, 100 - 81.24, Z_PCB_ATAS] : [84.5, 100 - 84.3, Z_PCB_ATAS]) cylinder(r = 3.3, h = 11.5);
}

echo(NAMA = NAMA_ITEM[item]);
intersection() { union() { depan(); belakang(); } isi(item); }

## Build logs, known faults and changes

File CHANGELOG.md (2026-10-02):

# Riwayat perubahan

Semua perubahan penting proyek **Absensi RFID Terintegrasi**. Versi firmware mengikuti `VERSI_FIRMWARE` di [firmware/absensi/config.h](firmware/absensi/config.h). Server (`api/`) dan contoh integrasi tidak punya nomor versi terpisah; perubahannya dicatat bersama versi firmware yang membutuhkannya.

Kompatibilitas: setiap versi firmware tetap bekerja dengan server lama. Fitur baru hanya aktif kalau server mengirim pengaturannya. Begitu juga sebaliknya: server baru tetap melayani firmware lama.

---

## Firmware 1.9.1 — 2 Oktober 2026

Rilis uji update manual. Kodenya sama dengan 1.9.0. Diuji dari website ke alat uji lewat menu **Update firmware**: buzzer diam dan LED biru selama update.

## Firmware 1.9.0 — 2 Oktober 2026

- **Perbaikan:** buzzer bisa tertahan menyala selama update firmware. Bunyi "klik" tombol Pasang tidak sempat dimatikan, karena selama mengunduh alat tidak mengurus buzzer. Sekarang buzzer dimatikan seketika saat update dimulai (`bipMati()`), dan LED menyala **biru tetap** selama update.

## Firmware 1.8.0 — 2 Oktober 2026

Rilis uji update manual. Kodenya sama dengan 1.7.0. Update berhasil, tapi menemukan masalah buzzer yang diperbaiki di 1.9.0.

## Firmware 1.7.0 — 2 Oktober 2026

- **Menu Pengaturan → Update firmware.** Alat langsung bertanya ke server (`GET /ping`) apakah ada versi yang dijadwalkan untuk alat itu.
  - Kalau ada, tampil versi dan ukurannya, dengan tombol **Pasang sekarang**. Pemasangan langsung berjalan, tanpa menunggu alat diam dan tanpa jeda 30 menit setelah gagal.
  - Kalau gagal, alasannya tampil di layar.
- Saat update gagal, log serial mencatat RAM bebas dan blok RAM terbesar, untuk mendiagnosis kegagalan koneksi HTTPS setelah alat lama menyala.

## Firmware 1.6.0 — 2 Oktober 2026

- **Mode absen** (menu **Mode absen**, atau dari website lewat `config.tap_mode`):
  - **Otomatis** (bawaan): semua tap ke `POST /tap`, server yang menentukan datang atau pulang. Sama seperti sebelumnya.
  - **Pilih Datang / Pulang**: layar utama menampilkan tombol **DATANG** dan **PULANG**.
    - Petugas memilih sekali; semua tap berikutnya dikirim ke `POST /check-in` atau `POST /check-out` sampai pilihannya diganti.
    - Pilihan dikosongkan otomatis saat tanggal berganti.
    - Tap sebelum memilih tidak dikirim, dan layar menampilkan "PILIH MODE DULU".
  - Antrean offline ikut menyimpan mode tiap tap. Baris antrean lama tetap terbaca.
  - Heartbeat mengirim `raw.tap_mode` dan `raw.tap_select`.
  - Menu Info alat menambah baris **Mode absen**.
- **Buzzer langsung ke pin D17** tanpa transistor kini didukung. Arus pin D17 dinaikkan ke kekuatan maksimum (± 40 mA) supaya bunyinya tidak serak.
- Menu Pengaturan ditata ulang untuk 12 tombol.

## Firmware 1.5.0 — 2 Oktober 2026

- **Kode error di layar:** E10–E13 (WiFi), E20–E26 (server), E30 (RFID), dan E31 (jam), di baris bawah layar utama, langkah boot, dan Info alat. Juga dikirim di heartbeat (`raw.error`).
- **Ringkasan crash** dari coredump (task, PC, backtrace, id build), dikirim di heartbeat (`raw.crash`) lalu dihapus. Heartbeat juga mengirim `min_free_heap`.
- **Update firmware jarak jauh (OTA)** dari `config.firmware_update`:
  - Alat mengunduh saat diam, memeriksa ukuran dan MD5, lalu restart.
  - Firmware baru berstatus percobaan. Kalau crash sebelum dinyatakan sehat, alat kembali ke versi lama dan melaporkan `raw.ota_failed`.
  - Restart karena listrik padam atau tombol EN di masa percobaan diulang sampai 3 kali, tidak langsung dianggap gagal.
- **Partisi `min_spiffs`:** 2 slot aplikasi 1,9 MB plus coredump. Alat dengan firmware ≤ 1.4.0 harus di-upload sekali lewat USB.
- **ID alat disimpan** di NVS "identitas". Build OTA (`./upload.sh -b`, flag `OTA_BUILD`) memakai ID tersimpan, sehingga satu file `.bin` aman dikirim ke semua alat.
- Header layar boot dipusatkan supaya nomor versi tidak terpotong.

## Firmware 1.4.0 — 1 Oktober 2026

- **Watchdog 60 detik:** alat restart sendiri kalau program macet.
- **Restart harian terjadwal** (`config.restart_at`, bawaan 03:00), hanya saat alat diam.
- Alasan restart terakhir tampil di monitor serial dan Info alat, dan dikirim lewat heartbeat (`raw.reset_reason`).
- Identitas baru **"Absensi RFID Terintegrasi"** di layar boot, monitor serial, dan User-Agent.

## Firmware 1.3.0 — rilis open source pertama

Tap kartu dengan hasil di layar, antrean offline 200 tap, screensaver pengumuman, layar meredup, PIN dan judul dari server, panduan penyetelan di layar sentuh, kalibrasi layar, dan reset pabrik.

---

## Server acuan Laravel (`api/`)

| Untuk firmware | Perubahan | Migrasi |
|---|---|---|
| 1.4.0 | Jam restart harian per alat (`config.restart_at`), diatur di halaman Alat | `2026_10_01_000011_add_restart_at_to_devices_table` |
| 1.5.0 | **Pemantauan alat:** kolom kesehatan, riwayat kejadian (restart, crash, ganti firmware, OTA gagal), peringatan di halaman Alat & dasbor | `…000013_add_health_columns_to_devices_table`, `…000014_create_device_events_table` |
| 1.5.0 | **Menu Firmware:** unggah `.bin` (validasi ukuran, byte `0xE9`, versi di dalam file), jadwalkan per alat / semua alat, `config.firmware_update`, unduhan `GET /api/absensi/firmware/{id}` | `…000012_create_firmware_releases_table` |
| 1.6.0 | **Mode absen:** `POST /api/absensi/check-in` & `/check-out`, `config.tap_mode` per alat, tampilan mode & pilihan alat di halaman Alat | `2026_10_02_000001_add_tap_mode_columns_to_devices_table` |

Semua kode baru aman dijalankan **sebelum** migrasinya: fitur yang butuh kolom baru otomatis nonaktif sampai `php artisan migrate` dijalankan. Tes otomatis: 160 tes lulus.

## Contoh integrasi (`contoh-integrasi/`) & dokumentasi

- **[doc/integrasi-aplikasi.md](doc/integrasi-aplikasi.md):** panduan integrasi ke aplikasi lain dengan **6 fitur wajib** (Kartu belum terdaftar, Rekap, Alat, Firmware, Pengumuman, Pengaturan), urutan kerja, model data, Postman/Newman, checklist, dan masalah umum.
- **Server contoh PHP & Node** menjalankan keenam fitur lewat API admin JSON (`X-Admin-Key`), dengan perilaku identik, ditambah endpoint `/check-in` & `/check-out`.
- **Postman** disusun ulang: folder **1. API alat** (uji kepatuhan untuk aplikasi mana pun) dan **2. Admin contoh**, plus file `contoh-firmware.bin` untuk menguji alur firmware. Bisa dijalankan otomatis dengan Newman.
- **[doc/spesifikasi-api.md](doc/spesifikasi-api.md):** bagian 4.1 Mode pilih, field heartbeat baru, `config.firmware_update`, dan `config.tap_mode`.
- **[doc/panduan-pengguna.md](doc/panduan-pengguna.md):** panduan untuk pengguna/klien.

## Perangkat keras

- **PCB dot matrix** dirancang ulang untuk papan **1 sisi 30 × 50 lubang** (label `1a`–`2d`, `001`–`050`), dengan posisi LCD, RC522, dan ESP32 diukur langsung di papan:
  - semua komponen di depan, kabel di belakang, disolder langsung ke kaki;
  - LED lewat kabel; buzzer di papan dan langsung ke D17;
  - baris 042–050 tidak dipakai.
  - Panduan interaktif: [doc/rakit-dotmatrix.html](doc/rakit-dotmatrix.html).
- Alat pertama dirakit dengan tata letak ini dan berjalan, termasuk update jarak jauh 1.5.0 → 1.9.1.

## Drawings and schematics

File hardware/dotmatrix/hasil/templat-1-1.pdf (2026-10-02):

## Absensi RFID Terintegrasi - templat dot matrix 1:1

## DEPAN (sisi komponen)

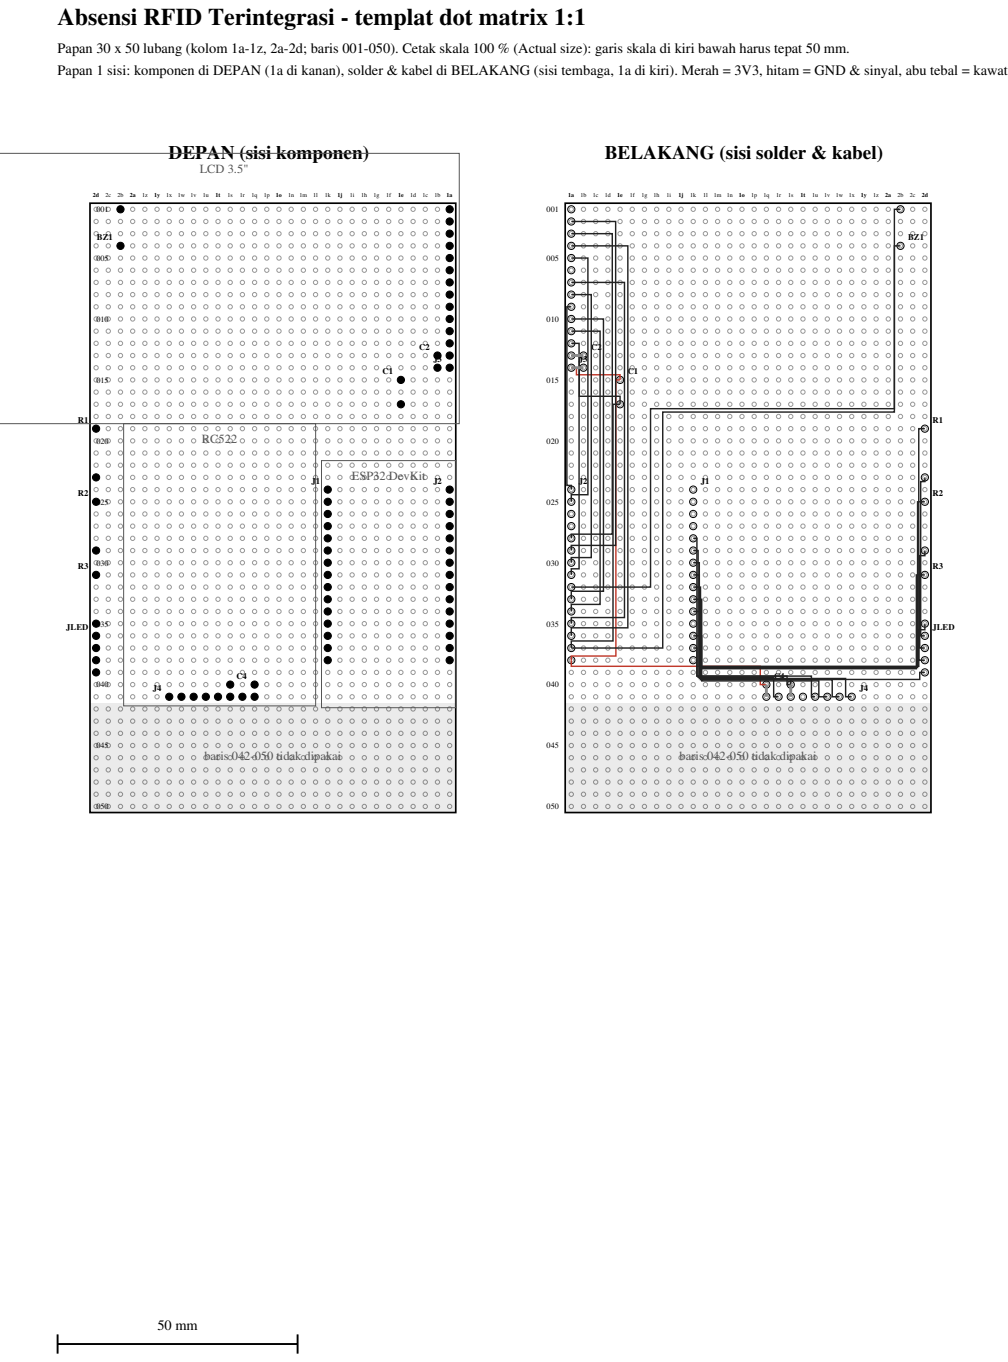
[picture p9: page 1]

Papan 30 x 50 lubang (kolom 1a-1z, 2a-2d; baris 001-050). Cetak skala 100 % (Actual size): garis skala di kiri bawah harus tepat 50 mm.
Papan 1 sisi: komponen di DEPAN (1a di kanan), solder & kabel di BELAKANG (sisi tembaga, 1a di kiri). Merah = 3V3, hitam = GND & sinyal, abu tebal = kawat polos.

BELAKANG (sisi solder & kabel)

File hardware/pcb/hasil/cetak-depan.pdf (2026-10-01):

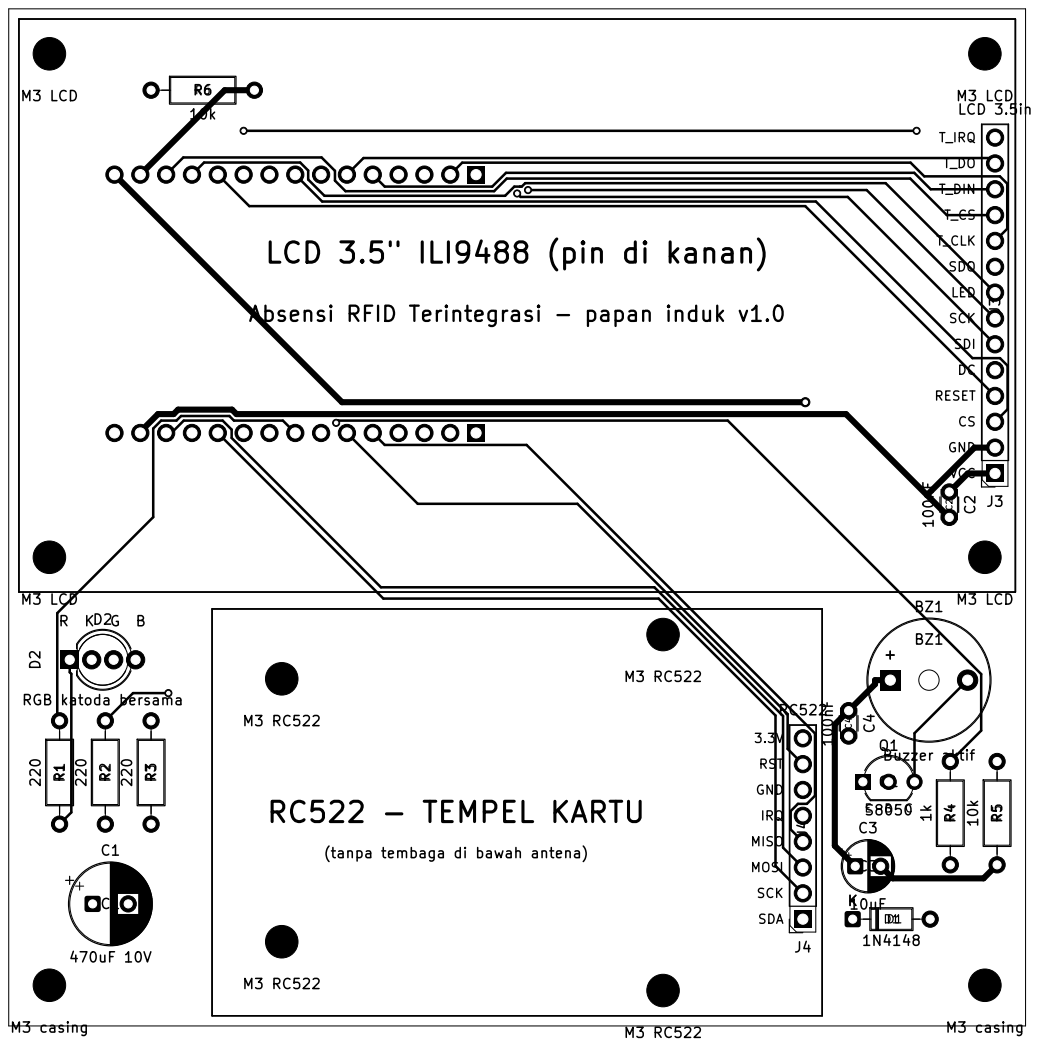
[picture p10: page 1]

LCD 3.5" ILI9488 (pin di kanan)

Absensi RFID Terintegrasi - papan induk v1.0

IRQ MISO MOSI SCK

(tanpa tembaga di bawah antena)

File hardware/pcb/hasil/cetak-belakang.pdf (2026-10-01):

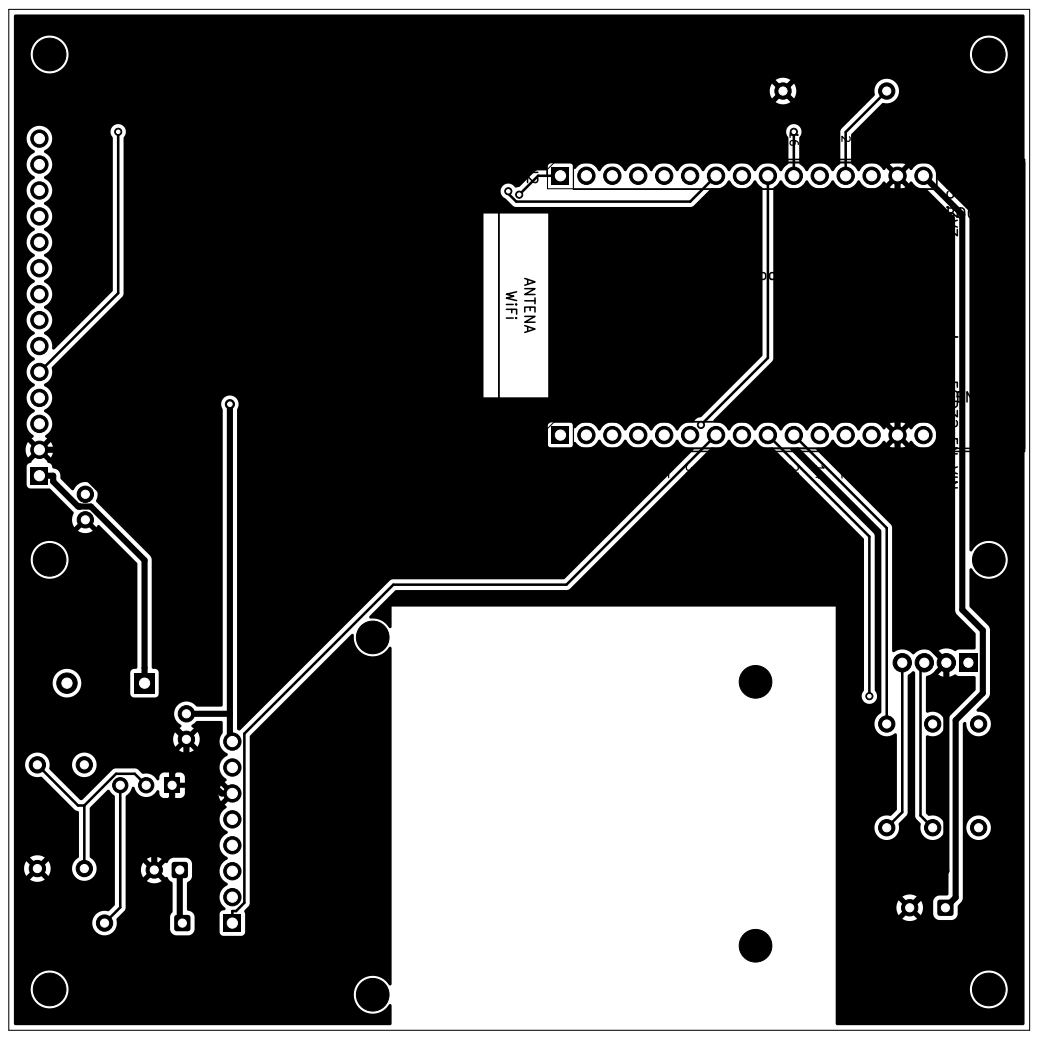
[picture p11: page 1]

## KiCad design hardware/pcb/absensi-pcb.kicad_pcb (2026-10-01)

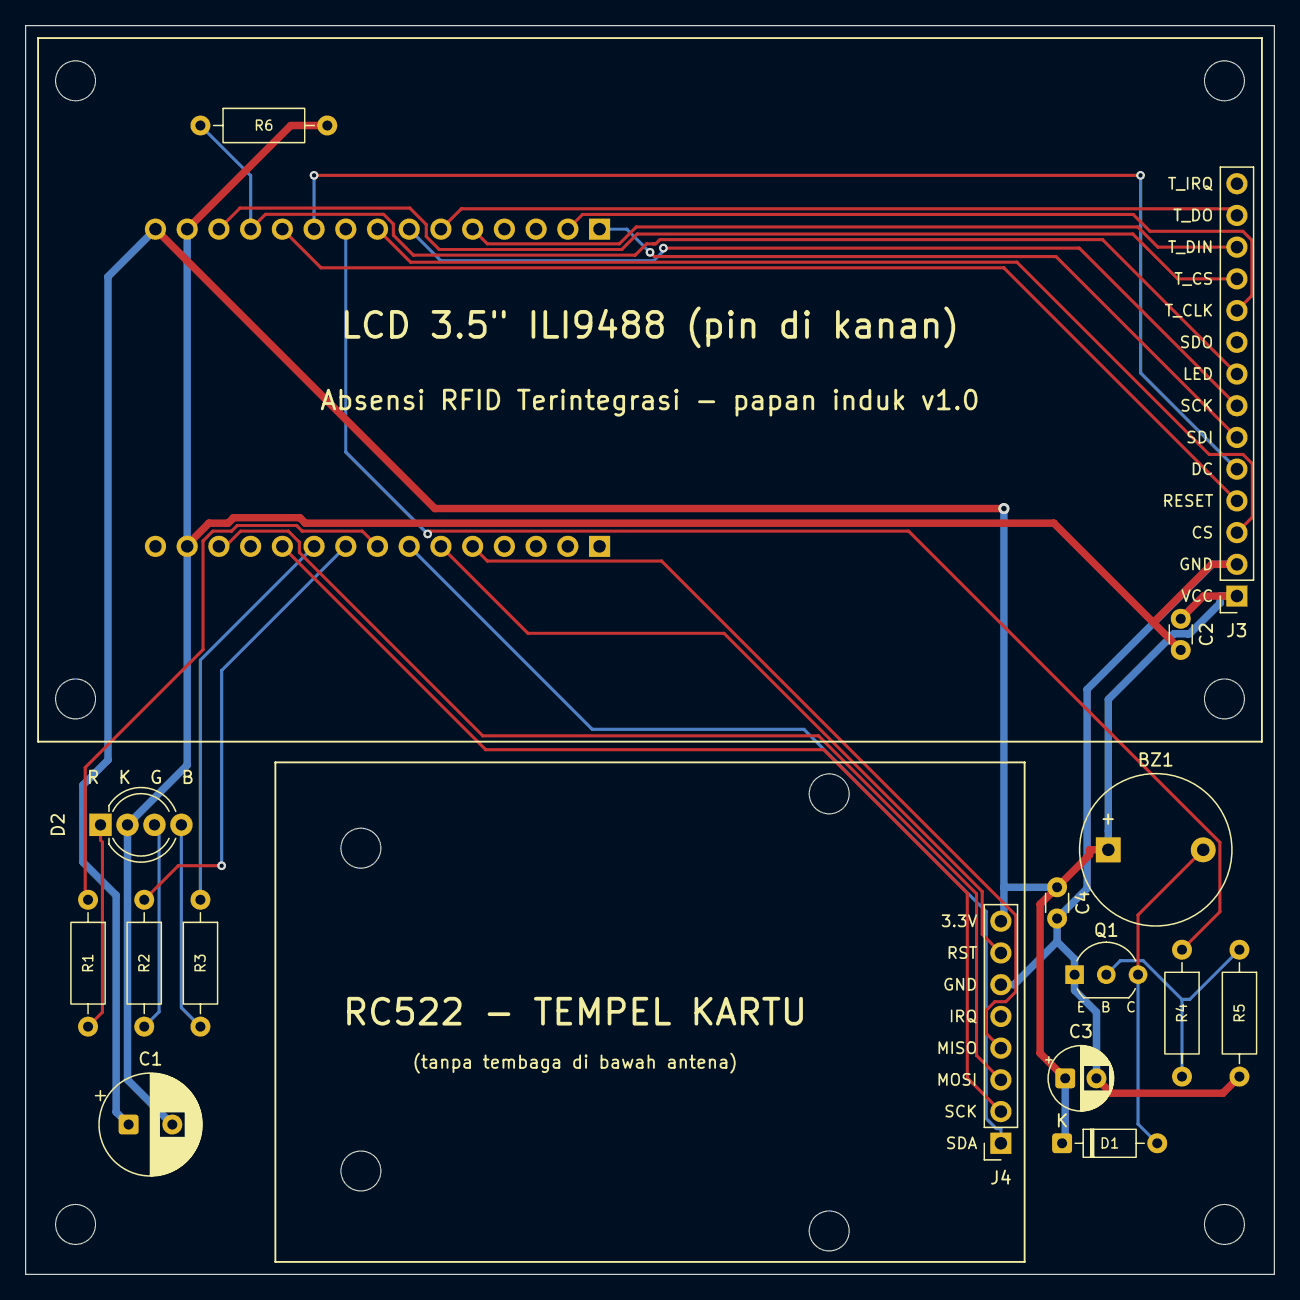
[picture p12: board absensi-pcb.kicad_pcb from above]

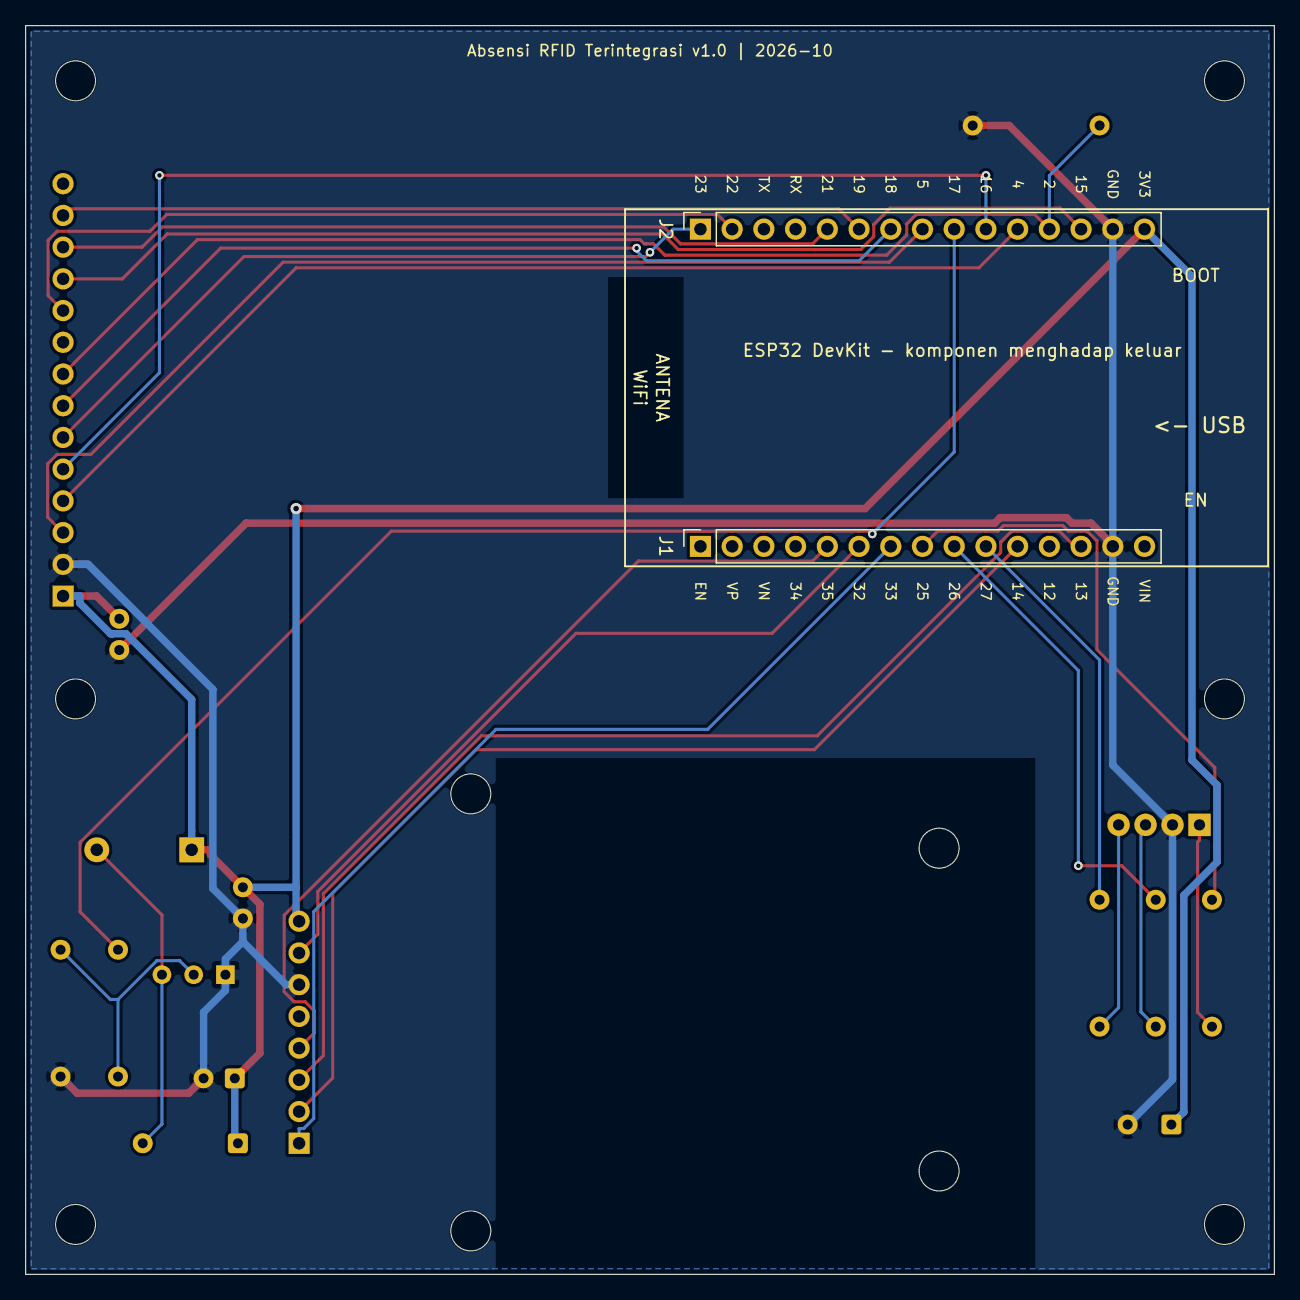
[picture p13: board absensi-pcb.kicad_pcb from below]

Board: 2 copper layers, 100.0 x 100.0 mm, 28 parts (2 on the bottom side), 26 nets.

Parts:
BZ1: Buzzer aktif; Buzzer_12x9.5RM7.6
C1: 470uF 10V; CP_Radial_D8.0mm_P3.50mm
C2, C4: 100nF; C_Disc_D3.0mm_W1.6mm_P2.50mm
C3: 10uF; CP_Radial_D5.0mm_P2.50mm
D1: 1N4148; D_DO-35_SOD27_P7.62mm_Horizontal
D2: RGB katoda bersama; LED_D5.0mm-4_RGB_Wide_Pins
H1, H2, H3, H4: M3 LCD; MountingHole_3.2mm_M3
H5, H6, H7, H8: M3 RC522; MountingHole_3.2mm_M3
H9, H10: M3 casing; MountingHole_3.2mm_M3
J1: ESP32 EN..VIN; PinSocket_1x15_P2.54mm_Vertical
J2: ESP32 D23..3V3; PinSocket_1x15_P2.54mm_Vertical
J3: LCD 3.5in; PinSocket_1x14_P2.54mm_Vertical
J4: RC522; PinSocket_1x08_P2.54mm_Vertical
Q1: S8050; TO-92_Inline_Wide
R1, R2, R3: 220; R_Axial_DIN0207_L6.3mm_D2.5mm_P10.16mm_Horizontal
R4: 1k; R_Axial_DIN0207_L6.3mm_D2.5mm_P10.16mm_Horizontal
R5, R6: 10k; R_Axial_DIN0207_L6.3mm_D2.5mm_P10.16mm_Horizontal

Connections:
+3V3: BZ1.1, C1.1, C2.1, C3.1, C4.1, D1.1, J2.15, J3.1, J4.8
BUZ: J2.9, R4.1
BUZ_B: Q1.2, R4.2, R5.1
BUZ_K: BZ1.2, D1.2, Q1.3
GND: C1.2, C2.2, C3.2, C4.2, D2.2, J1.14, J2.14, J3.2, J4.6, Q1.1, R5.2, R6.2
LCD_CS: J2.8, J3.3
LCD_DC: J2.10, J3.5
LCD_LED: J2.12, J3.8, R6.1
LCD_MOSI: J2.1, J3.6
LCD_RST: J2.11, J3.4
LCD_SCK: J2.7, J3.7
LED_B: D2.4, R3.2
LED_B_IO: J1.10, R3.1
LED_G: D2.3, R2.2
LED_G_IO: J1.9, R2.1
LED_R: D2.1, R1.2
LED_R_IO: J1.8, R1.1
RFID_MISO: J1.5, J4.4
RFID_MOSI: J1.13, J4.3
RFID_RST: J1.6, J4.7
RFID_SCK: J1.11, J4.2
RFID_SS: J1.7, J4.1
T_CLK: J2.2, J3.10
T_CS: J2.13, J3.11
T_DIN: J2.5, J3.12
T_OUT: J2.6, J3.13

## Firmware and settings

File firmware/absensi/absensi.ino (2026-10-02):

// Absensi RFID Terintegrasi: alat absensi kartu RFID dengan layar sentuh 3.5" yang terhubung ke website.
// Alat umum: bisa dihubungkan ke aplikasi apa saja yang mengikuti doc/spesifikasi-api.md.
// Kartu ditempel -> POST {Base URL}/tap -> layar menampilkan MASUK / PULANG / dst.
// Semua pengaturan (WiFi, Base URL, API key, PIN) diisi lewat layar sentuh.
//
// File:
//   config.h      pin, waktu, versi, nilai bawaan pabrik (PIN 2026)
//   tft_setup.h   pin layar untuk TFT_eSPI
//   pengaturan.h  pengaturan tersimpan di memori (NVS), ID alat, hitungan tekan EN
//   feedback.h    buzzer dan LED RGB
//   lampu.h       lampu latar layar (D2): meredup saat alat diam
//   perawatan.h   watchdog, restart harian terjadwal, alasan restart terakhir, ringkasan crash
//   modeabsen.h   mode absen: otomatis (/tap) atau pilih DATANG/PULANG (/check-in, /check-out)
//   rfid.h        pembaca kartu RC522 (dan cek kabel MOSI/MISO)
//   waktu.h       jam (server_time / NTP) dan zona waktu
//   antrean.h     antrean tap saat server tidak bisa dihubungi (LittleFS)
//   jaringan.h    WiFi dan HTTP/HTTPS (sambungan keep-alive, satu batas waktu per request)
//   galat.h       kode error singkat di layar (E10 WiFi tidak ditemukan, E21 API key salah, dst.)
//   ota.h         update firmware jarak jauh dari server, kembali ke versi lama kalau gagal
//   api.h         /ping, /tap, /heartbeat, pengaturan jarak jauh
//   ui.h          warna, alat bantu gambar, layar utama, layar hasil
//   ikon.h        ikon pengumuman (digambar dengan garis dan bentuk dasar)
//   pengumuman.h  daftar pengumuman dari GET /announcements (disimpan di LittleFS)
//   screensaver.h layar pengumuman bergantian saat alat diam
//   foto.h        foto pemilik kartu (JPEG)
//   touch.h       layar sentuh dan kalibrasinya
//   modal.h       alat bantu layar pengaturan (pesan, tanya Ya/Batal)
//   keyboard.h    papan ketik di layar
//   keypad.h      keypad PIN
//   penyetelan.h  pilih WiFi, Base URL, API key, tes koneksi, panduan pertama kali
//   menu.h        menu Pengaturan: info alat, ganti PIN, kalibrasi, tes buzzer & LED, tes screensaver,
//                 cek kabel RFID, reset pabrik
//
// Kalibrasi ulang layar sentuh: tekan EN, lalu tekan BOOT saat muncul tulisan "Tekan BOOT sekarang"
// (dalam 1 detik), atau lewat Pengaturan (gir) > "Kalibrasi layar".
// Reset pabrik: tekan EN 3 kali dalam 5 detik, lalu pilih "Ya, reset".
// Lampu layar: meredup setelah diam 60 detik (atau config.dim_after dari server). Kartu langsung membuatnya
// terang; sentuhan pertama hanya menyalakan lampu.
// Screensaver: layar utama diam (tanpa sentuhan dan kartu) selama "idle" detik dari server -> pengumuman
// tampil bergantian. Kartu tetap bisa di-tap. Sentuh layar untuk kembali.
// Tap cepat: hasil tampil begitu server menjawab (paling lama TAP_TIMEOUT_MS, lewat dari itu tap disimpan
// di antrean). Request lain (heartbeat, pengumuman, antrean) hanya dikirim saat alat diam, supaya tidak
// membuat orang yang tap menunggu.
// Buka Serial Monitor 115200 baud untuk melihat catatan program (termasuk lama tiap tap, contoh "Tap: 245 ms").

#include <SPI.h>
#include <TFT_eSPI.h>
#include "config.h"

TFT_eSPI tft = TFT_eSPI();   // layar, dipakai oleh file-file di bawah

#include "pengaturan.h"
#include "feedback.h"
#include "lampu.h"
#include "rfid.h"
#include "waktu.h"
#include "perawatan.h"
#include "modeabsen.h"
#include "antrean.h"
#include "jaringan.h"
#include "galat.h"
#include "ota.h"
#include "api.h"
#include "ui.h"
#include "ikon.h"
#include "pengumuman.h"
#include "screensaver.h"
#include "foto.h"
#include "touch.h"
#include "modal.h"
#include "keyboard.h"
#include "keypad.h"
#include "penyetelan.h"
#include "menu.h"

enum Layar { LAYAR_BOOT, LAYAR_UTAMA, LAYAR_HASIL, LAYAR_SCREENSAVER };
Layar layar = LAYAR_BOOT;
uint32_t waktuLayar = 0;          // kapan layar sekarang dibuka (di layar utama: kapan terakhir dipakai)

uint32_t antreanBerikut = 0;      // antrean boleh dikirim lagi mulai waktu ini
uint32_t aktifTerakhir = 0;       // kapan terakhir ada kartu atau sentuhan (request latar menunggu alat diam)

// ---------- Pindah layar ----------

// LED saat menunggu: napas pelan kalau semua normal, berkedip kalau ada masalah.
void ledSiaga() {
  if (modeLed == LED_TES) return;                         // tes LED sedang berjalan
  if (!wifiTerhubung() || statusServer == SERVER_GAGAL) ledKedip(LED_ORANYE);
  else if (!rfidAda) ledKedip(LED_MERAH);
  else ledNapas(LED_SIAGA);
}

void bukaUtama() {
  layar = LAYAR_UTAMA;
  waktuLayar = millis();                                  // hitung diam untuk screensaver mulai dari sini
  uiUtama();
  ledSiaga();
}

void bukaScreensaver() {
  Serial.printf("Screensaver: mulai (%d pengumuman)\n", jumlahPengumuman);
  layar = LAYAR_SCREENSAVER;
  uiScreensaver();
}

// ---------- Kartu di-tap ----------

void prosesKartu(const String& rfid, const String& uidHex) {
  uint32_t mulai = millis();
  lampuBangun();                                          // layar redup: langsung terang, kartu tetap diproses
  bip(1, 60);                                             // langsung: tanda kartu sudah terbaca
  ledNyala(LED_BIRU);
  uiMengirim(rfid);
  // Mode pilih tapi DATANG/PULANG belum dipilih: tap tidak dikirim, minta petugas memilih dulu.
  if (modePilih() && pilihanMode.length() == 0) {
    Serial.printf("Kartu terbaca: %s, tapi mode DATANG/PULANG belum dipilih (tidak dikirim)\n", rfid.c_str());
    HasilTap h;
    h.jenis = HASIL_PILIH_MODE;
    h.kode = 0;
    h.rfid = rfid;
    rfidMulaiJeda();
    uiHasil(h);
    bip(2, 200);
    ledNyala(LED_KUNING);
    layar = LAYAR_HASIL;
    waktuLayar = millis();
    aktifTerakhir = millis();
    return;
  }
  // tap_id, waktu, dan mode dibuat sekarang, dan ikut tersimpan kalau tap masuk antrean
  TapAntrean t = {tapIdBaru(), rfid, uidHex, waktuIso(), modeTap()};
  Serial.printf("Kartu terbaca: %s (UID %s), tap_id %s%s\n", rfid.c_str(), uidHex.c_str(), t.tapId.c_str(),
                t.mode == "check_in" ? ", mode DATANG" : t.mode == "check_out" ? ", mode PULANG" : "");

  // Program menunggu di sini paling lama TAP_TIMEOUT_MS. Gagal / terlalu lama = tap disimpan di antrean
  // dan dikirim nanti dengan tap_id yang sama (server tidak mencatat dua kali).
  HasilTap h = apiTap(t, false);
  if (h.jenis == HASIL_TERSIMPAN) {
    if (antreanSiap) antreanTambah(t);
    else h.jenis = HASIL_GAGAL;                           // penyimpanan rusak: tidak bisa disimpan
  }
  rfidMulaiJeda();

  uiHasil(h);
  switch (h.jenis) {
    case HASIL_MASUK:           bip(1, 150); ledNyala(LED_HIJAU);  break;
    case HASIL_PULANG:          bip(1, 150); ledNyala(LED_BIRU);   break;
    case HASIL_DUPLIKAT:        bip(2, 90);  ledNyala(LED_KUNING); break;
    case HASIL_TIDAK_TERDAFTAR:
    case HASIL_DITOLAK:         bip(3, 90);  ledNyala(LED_MERAH);  break;
    case HASIL_INFO:            bip(1, 150); ledNyala(LED_PUTIH);  break;
    case HASIL_TERSIMPAN:       bip(2, 200); ledNyala(LED_ORANYE); break;
    default:                    bip(1, 700); ledNyala(LED_MERAH);  break;   // HASIL_GAGAL
  }

  Serial.printf("Tap: %lu ms\n", (unsigned long)(millis() - mulai));   // dari kartu terbaca sampai hasil tampil

  if (h.fotoUrl.length() > 0) {
    bipTunggu();                                          // bunyi selesai dulu, unduh foto membuat program berhenti
    if (!fotoTampilkan(h.fotoUrl, FOTO_X, FOTO_Y, latarHasil)) uiHasilKotakIkon();
  }
  layar = LAYAR_HASIL;
  waktuLayar = millis();                                  // hitung mundur dimulai setelah foto tampil
  aktifTerakhir = millis();
}

// ---------- Pekerjaan latar (di layar utama dan screensaver) ----------
// Setiap request membuat layar berhenti sebentar (paling lama LATAR_TIMEOUT_MS), jadi paling banyak
// satu request per putaran loop, dan hanya saat alat diam.

// Kirim satu tap dari antrean. 2xx, 3xx, 4xx = selesai, dihapus dari antrean.
// Galat jaringan, timeout, 5xx, atau 429 (server sibuk) = tetap di antrean, dicoba lagi nanti.
void urusAntrean() {
  if (jumlahAntrean == 0 || !wifiTerhubung() || statusServer != SERVER_OK) return;
  if ((int32_t)(millis() - antreanBerikut) < 0) return;

  TapAntrean t;
  if (!antreanPertama(t)) {                               // baris rusak: dibuang
    Serial.println("Antrean: baris rusak dibuang");
    antreanBuangPertama();
    antreanBerikut = millis() + ANTREAN_JEDA_MS;
    return;
  }
  Serial.printf("Antrean: mengirim tap %s (%s)\n", t.rfid.c_str(), t.waktu.c_str());
  HasilTap h = apiTap(t, true);
  if (!gagalJaringan(h.kode)) {
    antreanBuangPertama();
    antreanBerikut = millis() + ANTREAN_JEDA_MS;
    if (kode2xx(h.kode)) Serial.printf("Antrean: terkirim (HTTP %d), sisa %d\n", h.kode, jumlahAntrean);
    else Serial.printf("Antrean: tap %s DIBUANG, ditolak server (%s), sisa %d\n", t.tapId.c_str(),
                       teksGalat(h.kode).c_str(), jumlahAntrean);
  } else {
    antreanBerikut = millis() + ANTREAN_ULANG_MS;         // server belum bisa: berhenti dulu
    Serial.printf("Antrean: gagal (%s), dicoba lagi %lu detik lagi\n", teksGalat(h.kode).c_str(),
                  (unsigned long)(ANTREAN_ULANG_MS / 1000));
  }
}

// Paling banyak satu request per putaran: heartbeat dulu, lalu pengumuman, lalu antrean.
// Hanya kalau tidak ada kartu dan sentuhan selama DIAM_LATAR_MS, jadi antrean tidak dikirim
// selama orang masih antre tap, dan kartu tidak pernah menunggu request latar yang baru dimulai.
void urusServer() {
  if (millis() - aktifTerakhir < DIAM_LATAR_MS) return;
  if (urusHeartbeat()) return;
  if (urusPengumuman()) return;
  urusAntrean();
}

// ---------- Urutan menyala (boot) ----------

enum LangkahBoot { BOOT_WIFI, BOOT_SERVER, BOOT_JAM, BOOT_SELESAI };
LangkahBoot langkahBoot = BOOT_WIFI;
uint32_t waktuLangkah = 0;

void bootSelesai() {
  langkahBoot = BOOT_SELESAI;
  waktuLangkah = millis();
  Serial.println("Siap menerima kartu.");
}

void urusBoot() {
  switch (langkahBoot) {
    case BOOT_WIFI:
      if (wifiTerhubung()) {
        uiLangkah(3, LANGKAH_OK, WiFi.localIP().toString());
        uiLangkah(4, LANGKAH_PROSES, "Memeriksa...");
        langkahBoot = BOOT_SERVER;
      } else if (millis() - waktuLangkah > WIFI_BOOT_TIMEOUT_MS) {
        Serial.println("WiFi: belum tersambung, lanjut dulu (dicoba terus di belakang)");
        String kode = kodeGalatWifi();
        uiLangkah(3, LANGKAH_GAGAL, kode.length() > 0 ? galatTeks(kode) : String("Belum tersambung"));
        uiLangkah(4, LANGKAH_LEWAT, "Dilewati");
        uiLangkah(5, LANGKAH_LEWAT, "Dilewati");
        bootSelesai();
      } else {
        static uint32_t animasi = 0;                      // "Menyambung." ".." "..."
        static int titik = 0;
        if (millis() - animasi > 400) {
          animasi = millis();
          titik = (titik + 1) % 4;
          uiLangkah(3, LANGKAH_PROSES, String("Menyambung") + String("...").substring(0, titik));
        }
      }
      break;

    case BOOT_SERVER: {
      HasilPing p = apiPing();
      uiLangkah(4, p.ok ? LANGKAH_OK : LANGKAH_GAGAL, p.pesan);
      uiLangkah(5, LANGKAH_PROSES, "Sinkron...");
      langkahBoot = BOOT_JAM;
      waktuLangkah = millis();
      break;
    }

    case BOOT_JAM:
      // Jam dari server_time (langsung) atau NTP (tunggu maks. 8 detik)
      if (jamValid()) {
        uiLangkah(5, LANGKAH_OK, jamMenit() + " " + offsetTeks() + (jamDariServer ? " (server)" : " (NTP)"));
        bootSelesai();
      } else if (millis() - waktuLangkah > 8000) {
        Serial.println("Jam: belum sinkron, dicoba terus di belakang");
        uiLangkah(5, LANGKAH_GAGAL, "E31 Belum sinkron");
        bootSelesai();
      }
      break;

    case BOOT_SELESAI:
      if (millis() - waktuLangkah > 1500) bukaUtama();    // beri waktu membaca daftar
      break;
  }
}

// ---------- setup & loop ----------

void setup() {
  Serial.begin(115200);
  delay(300);
  Serial.printf("\n##### ABSENSI RFID TERINTEGRASI v%s #####\n", VERSI_FIRMWARE);
  Serial.printf("Restart terakhir: %s\n", alasanResetTeks());
  watchdogMulai();
  crashBaca();                                            // ringkasan crash sebelumnya (kalau ada)
  aturMulai();                                            // pengaturan tersimpan + ID alat
  pilihanMuat();                                          // pilihan DATANG/PULANG terakhir (mode pilih)
  otaMulai();                                             // firmware baru dari OTA? / dulu gagal?
  bool tanyaReset = bootHitungNaik();                     // EN ditekan 3 kali?
  pinMode(PIN_TOMBOL_BOOT, INPUT_PULLUP);
  feedbackMulai();
  lampuMulai();                                           // lampu layar terang (D2)
  zonaTerapkan();

  tft.init();
  tft.setRotation(1);                                     // landscape 480 x 320
  tft.fillScreen(TFT_BLACK);
  Serial.println("Layar: OK");

  touchMulai();
  touchSiapkan();                                         // kalibrasi dulu kalau perlu

  rfidMulai();
  antreanMulai();                                         // memasang LittleFS (antrean + pengumuman)
  if (tanyaReset) tanyaResetPabrik();                     // setelah LittleFS terpasang, supaya ikut terhapus
  pengumumanMuat();                                       // daftar terakhir, supaya tetap tampil walau server mati
  wifiMulai();
  if (!aturLengkap()) panduanPenyetelan();                // alat baru / setelah reset pabrik

  uiBoot();
  uiLangkah(0, LANGKAH_OK, "480 x 320");
  uiLangkah(1, LANGKAH_OK, "Terkalibrasi");
  char versi[24];
  snprintf(versi, sizeof(versi), "RC522 (0x%02X)", rfidVersi);
  if (rfidAda) uiLangkah(2, LANGKAH_OK, versi);
  else         uiLangkah(2, LANGKAH_GAGAL, "E30 Tidak terdeteksi");
  uiLangkah(3, LANGKAH_PROSES, "Menyambung");
  waktuLangkah = millis();
}

void loop() {
  urusLatar();                                            // buzzer, LED, WiFi, cek RFID

  if (layar == LAYAR_BOOT) {
    urusBoot();
    return;
  }
  if (layar == LAYAR_UTAMA || layar == LAYAR_SCREENSAVER) ledSiaga();

  // Kartu bisa di-tap di layar utama, saat screensaver, atau langsung saat hasil orang sebelumnya masih tampil.
  // Setelah hasil tampil, alat kembali ke layar utama (bukan ke screensaver).
  String rfidNomor, uidHex;
  if (rfidBaca(rfidNomor, uidHex)) {
    prosesKartu(rfidNomor, uidHex);
    return;
  }

  int x = 0, y = 0;
  bool disentuh = sentuhBaru(x, y);
  if (disentuh) {
    Serial.printf("Sentuh: x=%d y=%d\n", x, y);
    aktifTerakhir = millis();
  }

  if (layar == LAYAR_UTAMA) {
    if (disentuh) waktuLayar = millis();                  // layar dipakai: hitung diam mulai lagi
    // Mode diganti server (config.tap_mode), atau pilihan dikosongkan karena tanggal berganti
    if (modeAbsenBerubah || pilihanCekTanggal()) {
      modeAbsenBerubah = false;
      bukaUtama();
      return;
    }
    // Mode pilih: tombol DATANG / PULANG (sekali pilih, berlaku untuk tap berikutnya)
    if (disentuh && modePilih() && (kena(TOMBOL_DATANG, x, y) || kena(TOMBOL_PULANG, x, y))) {
      String pilih = kena(TOMBOL_DATANG, x, y) ? "check_in" : "check_out";
      klik();
      if (pilih != pilihanMode) {
        pilihanSimpan(pilih);
        heartbeatSegera = true;                           // server segera tahu pilihan baru
      }
      uiTombolMode();
      uiInfo(true);
      return;
    }
    uiUtamaUrus();
    if (disentuh && kena(TOMBOL_GIR, x, y)) {
      klik();
      bukaPengaturan();                                   // PIN, lalu menu (menunggu sampai ditutup)
      if (tesScreensaver) {                               // "Tes screensaver" dipilih di menu
        tesScreensaver = false;
        bukaScreensaver();
      } else {
        bukaUtama();
      }
      return;
    }
    if (jumlahPengumuman > 0 && millis() - waktuLayar >= diamPengumuman * 1000UL) {
      bukaScreensaver();
      return;
    }
    urusRestartHarian(millis() - aktifTerakhir >= RESTART_DIAM_MS);
    if (urusOta(millis() - aktifTerakhir >= OTA_DIAM_MS)) {   // update gagal: gambar ulang layar utama
      bukaUtama();
      return;
    }
    urusServer();
  } else if (layar == LAYAR_SCREENSAVER) {
    // Sentuhan apa pun hanya menutup screensaver (tidak menekan tombol di layar utama)
    if (disentuh || !ssUrus()) {
      Serial.println("Screensaver: selesai");
      bukaUtama();
      return;
    }
    urusRestartHarian(millis() - aktifTerakhir >= RESTART_DIAM_MS);
    if (urusOta(millis() - aktifTerakhir >= OTA_DIAM_MS)) {
      bukaUtama();
      return;
    }
    urusServer();
  } else {                                                // LAYAR_HASIL
    uint32_t lewat = millis() - waktuLayar;
    uiHasilSisa(1.0f - (float)lewat / HASIL_TAMPIL_MS);
    if (disentuh || lewat >= HASIL_TAMPIL_MS) bukaUtama();
  }
}

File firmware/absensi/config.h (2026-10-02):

// Pengaturan tetap alat absensi: pin, waktu, versi, dan nilai bawaan pabrik.
// Yang diisi di sini hanya ID alat. WiFi, Base URL, API key, PIN, dan judul diisi lewat layar sentuh
// (disimpan di memori alat, lihat pengaturan.h).
#pragma once

// ---------- ID alat (ubah untuk SETIAP alat sebelum upload) ----------
// Tampil di layar dan dikirim ke server sebagai X-Device-ID. Harus berbeda di tiap alat.
// Kosongkan ("") kalau ingin dibuat otomatis dari MAC, contoh "ABS-79438C".
const char ID_ALAT[] = "ABS-001";

// ---------- Build untuk update jarak jauh / OTA (README 2.7) ----------
// Hanya untuk pengguna Arduino IDE yang membuat file .bin lewat "Export Compiled Binary":
// hapus "//" di depan #define di bawah SEBELUM export, lalu pasang lagi "//" SESUDAHNYA.
// Selama aktif, ID_ALAT di atas tidak dipakai: tiap alat tetap memakai ID yang sudah tersimpan di alat.
// Pengguna ./upload.sh -b tidak perlu mengubah baris ini (skrip mengaktifkannya sendiri).
// #define OTA_BUILD

// ---------- Versi & nilai bawaan pabrik ----------
const char VERSI_FIRMWARE[] = "1.9.1";          // naikkan setiap membuat firmware baru (wajib untuk OTA)
const char VERSI_SPEK[]     = "1";              // versi spesifikasi API (header X-Spec-Version)
const char PIN_BAWAAN[]     = "2026";           // PIN menu Pengaturan sebelum diganti
const char JUDUL_BAWAAN[]   = "Absensi RFID";   // judul layar utama sebelum diganti
const int  OFFSET_BAWAAN    = 7 * 60;           // zona waktu bawaan dalam menit (+07:00 = WIB)
const char NTP_SERVER[]     = "pool.ntp.org";   // cadangan jam kalau server tidak mengirim server_time

// ---------- Waktu (milidetik) ----------
// Batas waktu di bawah ini berlaku untuk SELURUH request: sambung + TLS + tunggu jawaban (+ coba ulang).
const uint32_t HTTP_TIMEOUT_MS       = 8000;    // GET /ping (saat menyala dan "Tes koneksi")
const uint32_t TAP_TIMEOUT_MS        = 3000;    // POST /tap langsung: lewat dari ini tap disimpan di antrean
const uint32_t LATAR_TIMEOUT_MS      = 3000;    // request latar: heartbeat, pengumuman, kirim antrean
const uint32_t HTTP_ULANG_MIN_MS     = 1000;    // sambungan lama gagal: coba ulang hanya kalau sisa waktu masih segini
const uint32_t FOTO_TIMEOUT_MS       = 3000;    // batas unduh foto
const uint32_t DIAM_LATAR_MS         = 5000;    // request latar hanya dikirim kalau tidak ada kartu / sentuhan selama ini
const uint32_t DNS_ULANG_MS          = 600000;  // alamat IP server dicari ulang (DNS) paling cepat tiap 10 menit
const uint32_t HEARTBEAT_INTERVAL_MS = 60000;   // heartbeat tiap 1 menit
const uint32_t ANTREAN_JEDA_MS       = 1000;    // jeda antar kiriman antrean
const uint32_t ANTREAN_ULANG_MS      = 30000;   // antrean gagal terkirim: coba lagi setelah ini
const uint32_t HASIL_TAMPIL_MS       = 4000;    // lama layar hasil tap
const uint32_t MENU_TIMEOUT_MS       = 60000;   // menu Pengaturan ditutup kalau tidak disentuh
const uint32_t KARTU_JEDA_MS         = 3000;    // kartu yang sama diabaikan selama ini
const uint32_t WIFI_BOOT_TIMEOUT_MS  = 15000;   // batas tunggu WiFi saat menyala
const uint32_t WIFI_TES_TIMEOUT_MS   = 15000;   // batas tunggu WiFi saat "Tes koneksi"
const uint32_t PIN_KUNCI_MS          = 60000;   // keypad dikunci setelah PIN salah berkali-kali
const int      PIN_SALAH_MAKS        = 5;       // berapa kali PIN boleh salah
const uint32_t RESET_TANYA_MS        = 15000;   // layar "Reset pabrik?" batal sendiri
const uint32_t PENGUMUMAN_CEK_MS     = 600000;  // pengumuman diambil ulang paling lambat tiap 10 menit
const uint32_t PENGUMUMAN_ULANG_MS   = 60000;   // gagal karena jaringan: coba lagi setelah ini (jeda dilipatgandakan
                                                // tiap gagal lagi, paling lama PENGUMUMAN_CEK_MS)
const uint32_t BOOT_AMAN_MS          = 5000;    // alat menyala lebih lama dari ini = bukan tekan EN beruntun
const int      BOOT_RESET_KALI       = 3;       // tekan EN sebanyak ini dalam 5 detik = tawaran reset pabrik

// ---------- Batas data ----------
const int    PIN_MIN_ANGKA  = 4;                // PIN menu Pengaturan: 4 sampai 8 angka
const int    PIN_MAKS_ANGKA = 8;
const int    JUDUL_UTAMA_MAKS = 30;             // judul layar utama (config.title) paling banyak 30 huruf
const int    ANTREAN_MAKS   = 200;              // tap yang disimpan saat server tidak bisa dihubungi
const size_t FOTO_MAKS_BYTE = 30 * 1024;        // foto paling besar 30 KB
const int    FOTO_MAKS_PX   = 160;              // foto paling besar 160 x 160 piksel
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

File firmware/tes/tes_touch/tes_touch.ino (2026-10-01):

// Tes touch dengan jalur SPI sendiri (tidak berbagi kabel dengan layar).
// Touch: T_CLK=D22, T_DIN=D21 (header I2C expansion), T_OUT=D19, T_CS=D15.
// Layar: lihat tft_setup.h.
// Lampu latar LCD di D2 dinyalakan penuh (sama dengan kabel firmware utama).
// Kalibrasi 3 titik disimpan di memori ESP32 (terpisah dari kalibrasi firmware utama).
// Mengulang kalibrasi: tekan EN, lalu tekan BOOT saat layar menampilkan "Tekan BOOT sekarang"
// (jangan menahan BOOT sambil menekan EN: ESP32 akan masuk mode upload).

#include <SPI.h>
#include <TFT_eSPI.h>
#include <XPT2046_Touchscreen.h>
#include <Preferences.h>

const int T_CLK = 22, T_DIN = 21, T_OUT = 19, T_CS = 15;
const int PIN_TOMBOL_BOOT = 0;
const int PIN_LAMPU_LCD = 2;      // kabel LED LCD

TFT_eSPI tft = TFT_eSPI();
SPIClass touchSpi(HSPI);
XPT2046_Touchscreen ts(T_CS);
Preferences prefs;

// Data kalibrasi: nilai mentah di dua posisi layar per sumbu, plus apakah sumbu tertukar
struct Kal { bool tukar; int16_t x1, x2, y1, y2; } kal;
const int PX1 = 30, PX2 = 450, PY1 = 30, PY2 = 290;   // posisi silang di layar 480x320

void silang(int x, int y, uint16_t warna) {
  tft.drawLine(x - 12, y, x + 12, y, warna);
  tft.drawLine(x, y - 12, x, y + 12, warna);
}

const int TEKANAN_MIN = 600;
bool ditekan() { return ts.touched() && ts.getPoint().z > TEKANAN_MIN; }

TS_Point tungguSentuh() {
  while (!ditekan()) delay(5);
  long sx = 0, sy = 0; int n = 0;
  while (ditekan() && n < 30) { TS_Point p = ts.getPoint(); sx += p.x; sy += p.y; n++; delay(10); }
  while (ditekan()) delay(5);
  delay(200);
  TS_Point p; p.x = sx / max(n, 1); p.y = sy / max(n, 1); p.z = 0;
  return p;
}

TS_Point ambilTitik(int x, int y, const char* nama) {
  tft.fillScreen(TFT_BLACK);
  tft.setTextColor(TFT_WHITE, TFT_BLACK);
  tft.drawCentreString("Kalibrasi: tekan tengah tanda silang", 240, 150, 2);
  silang(x, y, TFT_MAGENTA);
  TS_Point p = tungguSentuh();
  Serial.printf("  %s: mentah x=%d y=%d\n", nama, p.x, p.y);
  return p;
}

void kalibrasi() {
  Serial.println("Kalibrasi 3 titik...");
  TS_Point a = ambilTitik(PX1, PY1, "kiri atas");
  TS_Point b = ambilTitik(PX2, PY1, "kanan atas");
  TS_Point c = ambilTitik(PX1, PY2, "kiri bawah");
  // dari kiri atas ke kanan atas, sumbu mentah mana yang paling berubah = sumbu X layar
  kal.tukar = abs(b.y - a.y) > abs(b.x - a.x);
  kal.x1 = kal.tukar ? a.y : a.x;  kal.x2 = kal.tukar ? b.y : b.x;
  kal.y1 = kal.tukar ? a.x : a.y;  kal.y2 = kal.tukar ? c.x : c.y;
  if (abs(kal.x2 - kal.x1) < 500 || abs(kal.y2 - kal.y1) < 500) {
    Serial.println("Hasil kalibrasi tidak masuk akal, diulang. Tekan tepat di tengah tanda silang.");
    kalibrasi();
    return;
  }
  prefs.putBytes("kal", &kal, sizeof(kal));
  Serial.printf("Kalibrasi disimpan: tukar=%d x(%d..%d) y(%d..%d)\n", kal.tukar, kal.x1, kal.x2, kal.y1, kal.y2);
}

// Baca posisi dengan penyaring: abaikan awal sentuhan, ambil 5 sampel, buang kalau tidak konsisten.
bool bacaLayar(int& x, int& y) {
  static unsigned long mulaiTekan = 0;
  if (!ditekan()) { mulaiTekan = 0; return false; }
  if (mulaiTekan == 0) { mulaiTekan = millis(); return false; }
  if (millis() - mulaiTekan < 30) return false;          // bacaan awal masih goyah

  const int N = 5;
  int sx[N], sy[N];
  for (int i = 0; i < N; i++) {
    TS_Point p = ts.getPoint();
    if (p.z < TEKANAN_MIN) return false;                  // stylus mulai diangkat
    sx[i] = kal.tukar ? p.y : p.x;
    sy[i] = kal.tukar ? p.x : p.y;
    delayMicroseconds(500);
  }
  int minX = sx[0], maxX = sx[0], minY = sy[0], maxY = sy[0];
  long jx = 0, jy = 0;
  for (int i = 0; i < N; i++) {
    minX = min(minX, sx[i]); maxX = max(maxX, sx[i]);
    minY = min(minY, sy[i]); maxY = max(maxY, sy[i]);
    jx += sx[i]; jy += sy[i];
  }
  if (maxX - minX > 60 || maxY - minY > 60) return false; // sampel tidak konsisten = titik liar
  x = constrain(map(jx / N, kal.x1, kal.x2, PX1, PX2), 0, 479);
  y = constrain(map(jy / N, kal.y1, kal.y2, PY1, PY2), 0, 319);
  return true;
}

void layarGambar() {
  tft.fillScreen(TFT_BLACK);
  tft.setTextColor(TFT_WHITE, TFT_BLACK);
  tft.drawString("Sentuh layar untuk menggambar", 10, 12, 2);
  tft.fillRoundRect(375, 5, 100, 40, 8, TFT_RED);
  tft.setTextColor(TFT_WHITE, TFT_RED);
  tft.drawCentreString("Hapus", 425, 17, 2);
}

void setup() {
  Serial.begin(115200);
  delay(300);
  Serial.println("\n##### TES TOUCH #####");
  pinMode(PIN_TOMBOL_BOOT, INPUT_PULLUP);
  pinMode(PIN_LAMPU_LCD, OUTPUT);
  digitalWrite(PIN_LAMPU_LCD, HIGH);       // lampu layar menyala penuh

  tft.init();
  tft.setRotation(1);
  touchSpi.begin(T_CLK, T_OUT, T_DIN, T_CS);
  ts.begin(touchSpi);

  prefs.begin("touch", false);
  bool ada = prefs.getBytes("kal", &kal, sizeof(kal)) == sizeof(kal);
  bool valid = ada && abs(kal.x2 - kal.x1) > 500 && abs(kal.y2 - kal.y1) > 500;
  if (ada && !valid) Serial.println("Kalibrasi tersimpan tidak valid, diulang.");
  bool ulang = false;
  if (valid) {                             // beri 1.5 detik untuk meminta kalibrasi ulang
    tft.fillScreen(TFT_BLACK);
    tft.setTextColor(TFT_WHITE, TFT_BLACK);
    tft.drawCentreString("Tekan BOOT sekarang untuk kalibrasi ulang", 240, 150, 2);
    unsigned long mulai = millis();
    while (millis() - mulai < 1500 && !ulang) { ulang = digitalRead(PIN_TOMBOL_BOOT) == LOW; delay(10); }
  }
  if (!valid || ulang) kalibrasi();
  else Serial.printf("Memakai kalibrasi tersimpan: tukar=%d x(%d..%d) y(%d..%d)\n", kal.tukar, kal.x1, kal.x2, kal.y1, kal.y2);

  layarGambar();
  Serial.println("Mode gambar: titik kuning harus muncul tepat di bawah stylus.");
}

void loop() {
  static unsigned long lastRaw = 0;
  if (millis() - lastRaw > 1000) {
    lastRaw = millis();
    TS_Point r = ts.getPoint();
    Serial.printf("  (mentah) x=%4d y=%4d tekanan=%4d touched=%d\n", r.x, r.y, r.z, ts.touched());
  }
  int x, y;
  if (bacaLayar(x, y)) {
    if (x > 375 && y < 45) { layarGambar(); Serial.println("Layar dihapus"); delay(300); return; }
    tft.fillCircle(x, y, 3, TFT_YELLOW);
    static unsigned long last = 0;
    if (millis() - last > 200) { last = millis(); Serial.printf("Sentuh: x=%d y=%d\n", x, y); }
  }
}

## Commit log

2026-10-01 Absensi RFID Terintegrasi: rilis open source pertama
    Alat absensi tap kartu RFID (ESP32 + RC522 + LCD sentuh 3.5") yang
    terhubung ke website lewat API sederhana.
    - firmware/: firmware alat v1.3.0, sketsa tes, skrip upload & monitor
    - api/: server acuan Laravel + panel admin
    - contoh-integrasi/: contoh server PHP & Node, skrip pemeriksa, Postman
    - hardware/: tata letak PCB dot matrix, PCB cetak (KiCad), casing 3D (OpenSCAD)
    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
    [absensi-pcb-B_Cu.gbl, absensi-pcb-B_Mask.gbs, absensi-pcb-B_Silkscreen.gbo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]
2026-10-01 Firmware 1.4.0: watchdog, restart harian, dan identitas baru
    Firmware:
    - Watchdog 60 detik: alat restart sendiri kalau program macet.
    - Restart harian sesuai jam dari server (config.restart_at), hanya saat alat
    diam dan sudah menyala minimal 1 jam.
    - Alasan restart terakhir tampil di monitor serial dan Info alat, dan
    dikirim lewat heartbeat (raw.reset_reason).
    - Identitas baru "Absensi RFID Terintegrasi" di layar boot, monitor serial,
    dan User-Agent.
    Server:
    - Kolom restart_at per alat (bawaan 03:00, kosong = mati), bisa diatur dari
    halaman admin, dikirim di config.
    - Tes, README, spesifikasi API, dan contoh integrasi diperbarui.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
    [absensi.ino, config.h]
2026-10-01 Firmware 1.5.0: kode error, laporan kesehatan, dan update jarak jauh (OTA)
    - Kode error singkat di layar, saat boot, dan di Info alat (E10-E13 WiFi,
    E20-E26 server, E30 RFID, E31 jam), juga dikirim lewat heartbeat.
    - Ringkasan crash dari coredump (task, PC, backtrace, id build) dikirim
    lewat heartbeat lalu dihapus. Heartbeat juga mengirim min_free_heap.
    - Update firmware jarak jauh dari config.firmware_update: unduh saat alat
    diam, cek MD5, restart. Firmware baru berstatus percobaan; kalau crash
    sebelum sehat, alat kembali ke versi lama dan melaporkan ota_failed.
    Restart karena listrik / EN di masa percobaan diulang, bukan dianggap gagal.
    - Partisi diganti ke min_spiffs (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
    [absensi.ino, config.h]
2026-10-02 Firmware 1.9.1: mode absen, update firmware manual, perbaikan buzzer
    - Mode absen (1.6.0): Otomatis (/tap) atau Pilih Datang/Pulang dengan tombol
    DATANG & PULANG di layar utama -> POST /check-in & /check-out. Pilihan
    disimpan, dikosongkan saat ganti hari; tap sebelum memilih tidak dikirim.
    Antrean menyimpan mode tiap tap; config.tap_mode dari server; heartbeat
    mengirim raw.tap_mode & raw.tap_select; menu Mode absen & baris Info alat.
    - Buzzer bisa langsung ke D17 (tanpa transistor): arus pin dinaikkan maksimum.
    - Menu Pengaturan -> Update firmware (1.7.0): cek server sekarang, pasang
    langsung tanpa menunggu alat diam, alasan gagal tampil di layar.
    - Buzzer dimatikan & LED biru sela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
    [absensi.ino, config.h, feedback.h]
2026-10-02 Server: endpoint /check-in & /check-out dan mode absen per alat
    - POST /api/absensi/check-in & /check-out (aturan status sesuai spesifikasi
    4.1, tap_id idempoten lintas endpoint, tap antrean memakai tapped_at).
    - devices.tap_mode (config.tap_mode), reported_tap_mode & tap_select dari
    heartbeat; pilihan "Mode absen" di halaman Alat.
    - Aman sebelum migrasi (kolom dicek dulu). 15 tes baru, 160 tes lulus.
2026-10-02 Dot matrix 1 sisi, panduan pengguna, CHANGELOG
    - Tata letak PCB dot matrix untuk papan 1 sisi 30x50 (label 1a-2d/001-050),
    posisi LCD/RC522/ESP32 diukur di papan, kabel disolder langsung ke kaki,
    LED lewat kabel, buzzer langsung ke D17, baris 042-050 tidak dipakai.
    Panduan interaktif bisa dibalik depan/belakang, jalur kabel otomatis.
    - doc/panduan-pengguna.md: panduan untuk klien (absen, mode, menu, kode
    error, update firmware, perawatan).
    - CHANGELOG.md dan README (status, update manual, dokumen baru).
    [tata_letak.py]
2026-10-14 Firmware 1.10.0-1.11.4: RTC, jadwal mode pilih, indikator baterai UPS
    - RTC DS3231 opsional sebagai cadangan jam (terdeteksi otomatis, raw.rtc).
    - Jadwal otomatis mode Pilih (config.tap_schedule), pilihan manual kembali
    ke jadwal setelah 3 menit.
    - Indikator baterai UPS LX-2BUPS (baterai.h): pembagi 10k+10k ke D34
    (tegangan baterai) dan VP (listrik ada/padam). Ikon baterai di bilah
    status, pesan listrik padam / baterai lemah, heartbeat raw.power.
    Persen seperti di HP: tidak naik saat padam, disimpan di memori saat
    alat dimatikan.
    - Info alat dibagi 3 halaman (Ringkasan, Jaringan, Perangkat) dengan
    tombol panah, ditambah tegangan baterai bacaan langsung.
    - Menu "Tes buzzer" untuk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
2026-10-14 Panduan rakit dot matrix versi RTC dan UPS
    - Versi rtc: modul jam DS3231 di header JRTC menggantikan LED, plus daya
    baterai LX-2BUPS lewat saklar KCD11 ke JDAYA.
    - Versi ups: versi rtc ditambah pantau baterai. Header JBAT (BAT 2d-036,
    PLN 2d-037) ke D34 dan VP, pembagi 10k+10k disolder di modul UPS,
    langkah ukur multimeter sebelum dicolok, tes listrik padam.
    - Ketiga versi dibuat dari hardware/dotmatrix/tata_letak.py
    (python3 hardware/dotmatrix/tata_letak.py [led|rtc|ups]).
